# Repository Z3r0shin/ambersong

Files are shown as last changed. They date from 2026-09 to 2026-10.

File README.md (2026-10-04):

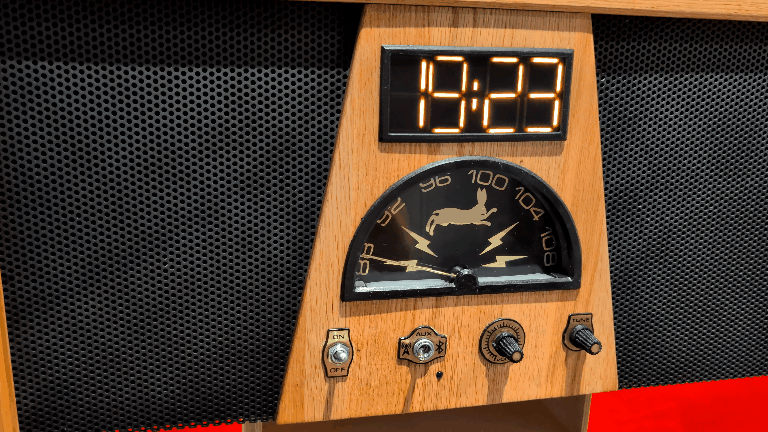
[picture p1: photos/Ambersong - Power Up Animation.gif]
Ambersong powering up


# Ambersong

*An old soul, glowing anew into the modern world.*

A LLOYD'S TM-838N tube radio from the early sixties, rebuilt around two ESP32 boards that
add Bluetooth, a retro-looking clock and a needle over a brass dial that follows the tuning.

## How it started

I found this radio in the trash, in a pile of other junk. The enclosure was bashed in and both the
power cord and antennas were pulled out. I tried it anyway, curious. Even though all it gave me was 
static, it was warm static, kind of like warm wind at night. I wasn't ready to throw that away.

So, I started restoring it. A couple of the old components had to be replaced. The tubes, though, 
still had enough life in them for a lot more years of use. If the tubes could last that long, I could
make something durable out of it, an heirloom.

I wanted it to look warm and cozy, mostly as an excuse and a challenge, to show off some of my 
woodworking skills and try some brass work. The cabinet is oiled oak and walnut, brass, and matte 
black accents. That cabinet, wood and brass together, is the part I'm proudest of. When it's on, 
it glows amber and still feels analog in all the good parts.

From there, the goal was to make it last for decades and write every part of it down so someone else 
could build their own (or use it as help/guide for something similar), repair one or change something.

## What it does

The tube set still does the receiving. Its original knob still turns its own tuning capacitor.
A magnetic angle sensor reads the capacitor's shaft and a small stepper motor moves the needle to 
match. The frequency scale isn't a straight line, so the radio calibrates itself. While it plays, 
an RDA5807M FM chip listens for the tube set's local oscillator, works out which station the set 
is really tuned to and corrects the needle's curve in firmware.

The tube radio's sound output goes through a PCM1802 ADC converter into the audio board, out through a
PCM5102A DAC to the amplifier and speakers of a repurposed Kramer Tavor 5-O pair. A front DPDT switch 
changes the audio from radio, Bluetooth or an AUX input. Four LED-filament digits at the top
show the time from a battery-backed RTC that sets itself over the network. A small web page on
the home network shows and changes every setting and updates both boards over WiFi.

## Why a Bible and a Gospel

Two documents describe the whole machine: the Hardware Bible for everything physical and the
Firmware Gospel for the code. Each one is meant to be the book you trust for its half of the
radio. The religious names are iconography, nothing more: I'm not religious, I just like the
symbols. Don't be upset about this please.

Each comes in two editions with the same information. The **Human Readable edition** is the one to
read (if you're a human): chapters, figures, an index and a "when something is wrong" table at the end of most chapters.
The **LLM edition** is the complete reference text it was written from; where the two differ, the LLM
edition is right. Why two "editions"? Because the LLM edition can't be understood at all by humans
(except maybe geniuses or complete fools) and I didn't only publish this project for it to be found
by AIs. Anyway, the Human Edition is also pretty, not the LLM one.

- **Hardware Bible**: what is wired to what, fitted values, the tube radio circuit, the FM antenna, the
  amplifier, the cabinet and the printed parts.
  [PDF](docs/Ambersong%20-%20Hardware%20Bible%20-%20Human%20Readable.pdf) ·
  [chapters](docs/human/hardware-bible/) ·
  [LLM edition](docs/llm-edition/HARDWARE-BIBLE.md)
- **Firmware Gospel**: what the firmware does and why, every setting, what was tried and dropped, and
  how to build, flash, update and recover it.
  [PDF](docs/Ambersong%20-%20Firmware%20Gospel%20-%20Human%20Readable.pdf) ·
  [chapters](docs/human/firmware-gospel/) ·
  [LLM edition](docs/llm-edition/FIRMWARE-GOSPEL.md)

## Building your own

Your radio, cabinet and amplifier probably won't be the same as mine and the documents are 
written with that in mind (hopefully). You could source your own parts and make it painful to you 
too to make everything work just enough that, past that pissed off state that you will certainly
achieve doing something like this, you can accept the flaws and embrace the result. Parts that only 
make sense for this build are marked as such. On the firmware side, expect to change pins, sensor 
directions, the tuner's travel and the needle's limits; the Gospel should say where each one lives.

The firmware is one PlatformIO project with two environments, `s3` for the main board (ESP32-S3,
N16R8) and `a32` for the audio board (ESP32). The toolchain is pinned to `espressif32@7.0.1`, just
to make sure that at least some stuff will translate correctly to you.

## Safety

Many tube radios from this era have no isolation transformer. If you find/use an old tube radio,
check if the chassis is tied to mains. Mine was, and since in those years the wall plug was reversible,
either live/hot or neutral could go to the whole chassis. Unplug it before you open it/play with such
a tube radio. Hardware Bible §31.1 covers what that means in this build.

## What's in here

```
docs/                    the Hardware Bible and the Firmware Gospel: Human Readable PDFs,
                         their chapters (docs/human/) and the LLM editions (docs/llm-edition/)
firmware/                the PlatformIO project for both boards
hardware/schematics/     the KiCad project, a collated PDF file and the radio's factory schematic
hardware/STLs/           the 76 printed parts and a Sketchup project with all those parts
photos/                  the finished radio, wow, such radio, mucho bueno
```

The KiCad sheets show what was built, drawn to be read. They aren't a PCB layout, so ERC and such do
not resolve correctly, that is normal. I don't know how to operate KiCad for this purpose anyway, I
use it to help route stuff visually only. I hope nobody's eyes bleed too much looking at them. Both 
the KiCad schematics and the Bible should agree. If not, open an issue, I'll correct it.

## What's NOT in here

I made my own antenna. I used what I had at home to make it. It's a 3 elements yagi, mainly because
where I am, almost all the stations are on Mount Royal, making it pretty directional. You should
definitely look what is best for your own case. The antenna build itself is in Bible and the Sketchup 
file though, if you want to take a look.

There is no bill of materials. Mostly because this specific build is made using what I found in a
pretty random fashion. Yes, I did buy the DAC, ADC, stepper, etc. but those are readily available in
the same form I bought, and I am pretty sure you can substitute most of them for something similar
and have similar results. Obviously, some adjustments will be needed, especially the STLs and the
electrical components values. As I said, this is not a build guide, its for inspiration and for
other mad folks that might stumble here trying to resolve a problem that is a part of my build.

## Credits

- My parents and friends, for their input on the design.
- Axiris, for the LEDitron: seven-segment digits made from LED filaments. I borrowed the idea
  and the name, nothing else. See the [LEDitron display](https://www.elektormagazine.com/labs/leditron-display-150448)
  on Elektor Labs (2015) and the [LEDitron clock and scoreboard](https://www.elektormagazine.com/labs/160205-clock-scoreboardtimer-with-leditron-modules).
- Phil Schatzmann, for the [ESP32-A2DP](https://github.com/pschatzmann/ESP32-A2DP) library that
  handles Bluetooth audio.
- My stupidity for making me do this and convincing myself that its a good idea.
- My wife and kids for putting up with me. It's done now, papa can come home.

The factory schematic of the TM-838N is included for reference, but note that it is superseded 
by the KiCad schematic. The documents also cite the SAMS Photofact for this set, which is 
copyrighted and not included.

## Disclaimer

I have barely coded anything in this. It's all been vibe-coded with Claude Code and Codex. The artwork,
design, and anything other than sound and electrical engineering and the actual coding were done
without AI, by me with the help of my friends and family.

## Contributions

You can open issues if you have questions and I'll try to help if I can, but don't count on me to 
make this yours. I'll just help with what I can, if I can.

## License

- Firmware: GPL-3.0-or-later
- Hardware design files (KiCad, STL): CERN-OHL-S-2.0
- Documentation: CC BY-SA 4.0
- Photos and renders: CC BY-NC-ND 4.0
- The running hare : all rights reserved. It's family imagery, not for reuse.

Apart from the photos and the hare, you can use any of it, change it and share it, commercially
too, as long as what you share stays under the same license. Details and exceptions are in [`LICENSE`](LICENSE) and [`NOTICE`](NOTICE).

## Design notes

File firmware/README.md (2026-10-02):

# Ambersong firmware

One PlatformIO project for the two boards of Ambersong:

| Environment | Board | What it runs |
|---|---|---|
| `s3` | ESP32-S3 (N16R8: 16 MB flash, 8 MB octal PSRAM) | the clock display, the dial needle and its sensors, the tuning calibration (RDA5807M), the panel lamps, WiFi, the web portal, over-the-air updates for both boards |
| `a32` | ESP32 | audio: the tube radio through the PCM1802 ADC, Bluetooth A2DP, the PCM5102A DAC, the source switch, the volume knob, the Bluetooth button and lamp, the DS3231 clock |

```
src/s3/      main board
src/a32/     audio board
include/     shared by both: pins.h (every pin), proto.h and link.h (the link between the boards)
data/        the portal's web page (gzipped into src/s3/page_gz.h at build time)
scripts/     build scripts: version stamping, page packing
```

## Build

```
pio run -e s3
pio run -e a32
```

The platform is pinned to `espressif32@7.0.1` (Arduino-ESP32 2.0.17, ESP-IDF 4.4.7), and the
ESP32-A2DP library to one commit. Do not update either without re-testing everything.

## Everything else

Flashing, the first boot, the portal, updates over the air, recovery, every setting and the reason
behind each design decision are in the Firmware Gospel: the [Human Readable edition](../docs/Ambersong%20-%20Firmware%20Gospel%20-%20Human%20Readable.pdf)
([chapters](../docs/human/firmware-gospel/)) or the complete [LLM edition](../docs/llm-edition/FIRMWARE-GOSPEL.md).
Start with its chapter 3 to build and flash from a clean PC, and its chapter 1 if the radio
misbehaves. What each pin is wired to is in the Hardware Bible,
the [Hardware Bible](../docs/Ambersong%20-%20Hardware%20Bible%20-%20Human%20Readable.pdf)
([chapters](../docs/human/hardware-bible/), [LLM edition](../docs/llm-edition/HARDWARE-BIBLE.md)).

Pins, sensor directions, the tuner's travel and the needle's limits are those of the author's
radio. Expect to change them for yours: the Gospel says where each one lives.

Licence: GPL-3.0-or-later (see [`../LICENSE`](../LICENSE)).

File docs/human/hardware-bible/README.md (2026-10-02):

# Ambersong — Hardware Bible, Human Readable edition

The same book as a PDF: [`Ambersong - Hardware Bible - Human Readable.pdf`](../../Ambersong%20-%20Hardware%20Bible%20-%20Human%20Readable.pdf).
The complete text it is based on (LLM edition): [`docs/llm-edition/`](../../llm-edition/).

## Contents

- [About this book](00-about.md)
- [1. What Ambersong is](01-what-it-is.md)
- [2. Safety before you open it](02-safety.md)
- [3. The physical build](03-physical-build.md)
- [4. The two microcontroller boards](04-boards.md)
- [5. Power, earth and grounds](05-power.md)
- [6. The audio chain](06-audio.md)
- [7. The clock display](07-display.md)
- [8. Dial, needle and tuning sensors](08-dial-sensors.md)
- [9. Front-panel controls and lamps](09-controls-lamps.md)
- [10. Cables and harnesses](10-cables.md)
- [11. The FM antenna](11-antenna.md)
- [12. The amplifier and speakers](12-amp.md)
- [13. The tube radio (LLOYDS TM-838N)](13a-tube-radio.md)
- [13b-tube-radio](13b-tube-radio.md)
- [Appendix A. Datasheet facts used in this machine](A-datasheet-limits.md)
- [Appendix B. Where the schematics differ from this book](B-schematic-differences.md)
- [Appendix C. What this book does not cover, and open points](C-open-points.md)
- [Appendix D. Printed parts](D-printed-parts.md)
- [Glossary](G-glossary.md)

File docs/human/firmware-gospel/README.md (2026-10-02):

# Ambersong — Firmware Gospel, Human Readable edition

The same book as a PDF: [`Ambersong - Firmware Gospel - Human Readable.pdf`](../../Ambersong%20-%20Firmware%20Gospel%20-%20Human%20Readable.pdf).
The complete text it is based on (LLM edition): [`docs/llm-edition/`](../../llm-edition/).

## Contents

- [About this book](00-about.md)
- [1. Rescue: when the radio misbehaves](01-rescue.md)
- [2. The machine at a glance](02-at-a-glance.md)
- [3. Building, flashing and updating](03-build-flash-update.md)
- [4. The main board: start-up, clock, lamps and time](04-main-board.md)
- [5. The dial needle](05-needle.md)
- [6. Tuning and the dial's self-calibration](06-tuning.md)
- [7. Settings](07-settings.md)
- [8. Network, web portal and console](08-network-portal.md)
- [9. The audio board and the link between the boards](09-audio-board-link.md)
- [10. Sound and Bluetooth](10-sound-bluetooth.md)
- [11. History and bench tests](11-history.md)
- [12. Known issues, ideas and untested paths](12-known-issues.md)
- [Appendix A. Settings reference](A-settings-reference.md)
- [Appendix B. Network and portal constants, HTTP endpoints, state fields](B-network-constants.md)
- [Appendix C. Portal actions](C-portal-actions.md)
- [Appendix D. Console keys](D-console-keys.md)
- [Appendix E. Portal map: tabs, cards, buttons and the calls they make](E-portal-map.md)
- [Appendix F. Link reference: constants, messages and payloads](F-link-reference.md)
- [Appendix G. Audio constants and experiments](G-audio-constants.md)
- [Appendix H. The pop hunt in detail](H-pop-hunt.md)
- [Appendix I. Pins as the firmware uses them](I-pin-use.md)

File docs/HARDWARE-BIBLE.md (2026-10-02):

# Ambersong — Hardware Bible

## 0. About this document

**What Ambersong is.** A vintage vacuum tube radio, a LLOYDS TM-838N AM/SW/FM set, connected with ESP32 audio and
control. Two ESP32 boards sit beside the tube chassis. The main MCU, an ESP32-S3, drives the LED clock display, the
dial-needle stepper and its sensors, the RDA5807M tuning calibrator and the panel lamps. The audio MCU, an ESP32 called
"A32" throughout, digitises the tube radio's output through a PCM1802 ADC, feeds a PCM5102A DAC to an external amplifier,
and reads the front-panel source switch (RADIO / BT / AUX), the Bluetooth button and LED, a volume pot and a DS3231 RTC.

**What this document covers.** The hardware: what joins what in the machine and in the tube radio inside it. For the
tube radio it also gives the fitted values and the original specifications held in the sheet's hidden Spec fields. The FM
antenna as built is §29; what the amp and its speakers are, and the amp's input panel, are §30; the physical build (the
cabinet, access, the front panel, the tuning and needle mechanics, the Faraday cages) is §31, mentioned rather than detailed.
This is not a step-by-step build guide: it does not cover wire colours (except the amp supply's four wires, §30), pin-1
sides, crimp/JST housings, individual cable lengths or routing, the contact order inside a connector, or the amp's circuit. Firmware is documented in `FIRMWARE-GOSPEL.md`. This document takes only five pin facts from the
firmware, listed below.

**How to read it with the Gospel and the sheets.** The KiCad sheets in `hardware/schematics/` are visual aids. The author
uses KiCad to show a human what was built, not to make a PCB, and some drawings place a part where it reads best rather
than where it sits (§22 says where). This document states the fitted hardware. Where a sheet and this document differ,
this document is right, and §25 lists the known drawing errors: all are corrected in the published sheets except two
typos. `FIRMWARE-GOSPEL.md` describes what the firmware does with this hardware. A firmware comment or define that
describes wiring is not a hardware record: where one disagrees with this document, the comment is stale (§26 lists the
known ones).

**Order of truth.** For the machine: the fitted hardware first, then the main sheet, then the sub-sheets. For the tube
radio: the fitted hardware first, then the factory schematic (`hardware/schematics/LLOYDS TM-838 factory schematic.jpg`),
then the SAMS Photofact for the set (a published, copyrighted service document, not included here). The tube radio sheet
reflects the fitted hardware, except for a few details noted on the sheet itself. Datasheet facts (§24) are quoted and
marked, and they describe the datasheet part, which is not always the fitted one.

**Pin facts taken from the firmware.** Five facts come from the firmware, not from the drawings, because on these points
the firmware is exact: the digit order, the digit MOSFET part, the Bluetooth button and LED pins, the volume pot wiper
pin, and the positions of the front DPDT source switch. The lines are quoted as they read in the firmware on 2026-09-12, before v.1.0 (paths under `firmware/`). Some of their comments have since been reworded or removed; the code on these lines and every pin number are unchanged.

- Digit order; line 42 is a comment asking for re-confirmation, written before the order was confirmed:
  - `include/pins.h` — `//  exactly one digit lights at a time. To be re-confirmed on the next run.`
  - `include/pins.h` — `#define S3_DIGIT_1         42      // was 2`
  - `include/pins.h` — `#define S3_DIGIT_2          2      // was 42, confirmed: this pin lights digit 2`
  - `include/pins.h` — `#define S3_DIGIT_3         40      // was 41`
  - `include/pins.h` — `#define S3_DIGIT_4         41      // was 40, confirmed: this pin lights digit 4`
- Digit MOSFET part FQP27P06; a comment:
  - `include/pins.h` — `//  S3 -> digit-driver ULN2003 input -> 1k -> FQP27P06 gate (high side).`
- BT button GPIO25 and BT LED GPIO33, both active low:
  - `include/pins.h` — `#define A32_BT_BUTTON      25      // ACTIVE LOW, ground-referenced, INPUT_PULLUP`
  - `include/pins.h` — `#define A32_BT_LED         33      // sinks; anode on 3V3, so drive LOW to light`
  - `src/a32/main.cpp` — `  pinMode(A32_BT_BUTTON, INPUT_PULLUP);      // ACTIVE LOW, measured`
  - `src/a32/main.cpp` — `  bool down = (digitalRead(A32_BT_BUTTON) == LOW);`
  - `src/a32/btled.cpp` — `  ledcWrite(LED_CH, 255 - v);         // ACTIVE LOW`
  - `src/a32/btled.cpp` — `  ledcAttachPin(A32_BT_LED, LED_CH);`
- Volume pot wiper GPIO35:
  - `include/pins.h` — `#define A32_VOLUME_POT     35`
  - `src/a32/main.cpp` — `  for (int i = 0; i < 5; i++) { v[i] = analogRead(A32_VOLUME_POT); delayMicroseconds(150); }`
  - `src/a32/main.cpp` — `    uint16_t r = analogRead(A32_VOLUME_POT);`
- Source select on GPIO36: below 424 counts AUX, 2471 and up RADIO, between BT:
  - `include/pins.h` — `#define A32_MODE_ADC       36`
  - `src/a32/main.cpp` — `  for (int i = 0; i < 5; i++) { v[i] = analogRead(A32_MODE_ADC); delayMicroseconds(200); }`
  - `src/a32/main.cpp` — `  raw = v[2];`
  - `include/pins.h` — `#define A32_MODE_THRESH_AUX_BT     424   // raw below this          -> AUX`
  - `include/pins.h` — `#define A32_MODE_THRESH_BT_RADIO  2471   // raw above this          -> RADIO`
  - `src/a32/main.cpp` — `  if (raw <  A32_MODE_THRESH_AUX_BT)   return SRC_AUX;`
  - `src/a32/main.cpp` — `  if (raw >= A32_MODE_THRESH_BT_RADIO) return SRC_RADIO;`
  - `src/a32/main.cpp` — `  return SRC_BT;`
- The ladder, and the level each source reads, in comments that are exact for the switch positions (which leg gives which level follows from the drawn 22 kΩ and 68 kΩ):
  - `include/pins.h` — `//  The ladder itself is exactly as drawn - A_VDC through the switch, one leg`
  - `include/pins.h` — `//  direct and one through 68k, joining a single 22k to GND, then 1k + 0.1uF at`
  - `include/pins.h` — `//  the pin. Levels land at 3.3 V / 0.807 V / 0 V as designed.`
  - `include/pins.h` — `//        measured   AUX = 0        BT = 848 (0.81 V)   RADIO = 4095 (3.3 V)`

**How it was made.** A script read the saved `.kicad_sch` source text (never the netlist, never a picture for text) and
computed connectivity. Every item was then looked up again in the source and checked against the author's knowledge of
the fitted hardware.

**Where the drawings are wrong.** §25 lists the drawing errors found while this document was made, and how each was
corrected. If a drawing disagrees with this document, check §25 first.

**Conventions.**
- Coordinates are sheet millimetres. The author often types a value into a part's Reference field, so a part may be
  named by its value plus its position: `10kΩ@21.59,140.97`.
- Pins: `#1` is a pin number; `VCC`, `SCK`, `A`, `K` are pin names. The MCU symbols name their pins by GPIO number
  (U7 pin `4` is GPIO4). `p2/3` is the 2nd of 3 pins counted top-to-bottom in the library symbol, used when a symbol
  has neither name nor number (the JST connectors, the PC817). `p`-order is not a moulded contact number.
- A label name (`GPIO4`, `A_IO22`) is how the drawings refer to one conductor. A net can carry two names, a global
  label and a local label joined by a wire; both name that conductor.
- `A_VDC` = `A_3V3`: the same rail, joined by the bus. `S3_3V3` is the S3's 3.3 V. `5VDC_S` = `5VDC`.
- `CABLE S/FTP` on a connector pin: the cable's shield and foil are terminated there, to GND on the board side, and
  left open at the cable's other end, unless noted otherwise.
- Source lines name the drawing (the main sheet, the cable sheet, or `sheet <title>`; the files are listed below);
  "the author" where the fact rests on the author's knowledge of the fitted hardware rather than on a drawing; and SCn
  for a drawing correction in §25. "Label names across all drawings" means the label name was looked up on every
  drawing. Line numbers inside the `.kicad_sch` files and net numbers are left out, because every save moves them.
- `block B47`, `note B29`, `drawn blocks B6 and B7`: the rectangles drawn on a sheet, numbered B1, B2, … by position — top edge
  first, rounded to the millimetre, then left edge — as read when this document was made (a later save may renumber them); a
  text note carries the number of the smallest rectangle around it. The numbers are not printed on the drawings. The ones
  this document cites, by corners in sheet mm: the main sheet B29 (12.70,38.10)-(71.75,43.18), B30 (12.70,43.18)-(71.75,48.26), B31 (12.70,48.26)-(71.75,53.34), B47 (69.22,93.98)-(107.31,125.73); sheet HERE (the star-point buses) B5 (130.18,76.83)-(139.06,119.38), B6 (159.38,76.83)-(168.28,119.38), B7 (173.35,76.83)-(182.25,119.38).
  `G1` to `G9` name this document's nine Ambersong groups (§4 to §12); `T1` to `T9` name the tube radio groups (§13 to §21).
- Tube radio: a tube is drawn as units of one tube (its signal sections in their circuit, its heater on the heater string);
  S1A–S1G are seven drawn units of one mode switch; the terminal identifiers of L5, L6, L8–L14 and S1A–S1G are logical, not
  physical lugs. `CHASSIS` is the radio's circuit common, on mains neutral. In the polarized capacitors C1A–C1C and C2,
  pin #1 is the + terminal (read from the symbol embedded in the sheet).

**The drawings**, in `hardware/schematics/` (as saved on 2026-09-23):

| Named in this document | File |
|---|---|
| the main sheet | `Ambersong.kicad_sch` |
| the cable sheet | `Ambersong - CABLES.kicad_sch` |
| sheet 7 SEGMENTS 24H CLOCK DISPLAY | `Ambersong - 7 SEGMENTS 24H CLOCK DISPLAY.kicad_sch` |
| sheet AUDIO MCU ESP32-WROOM-32 | `Ambersong - AUDIO MCU ESP32-WROOM-32.kicad_sch` |
| sheet BLUETOOTH PAIR BUTTON & FRONT PANEL BLUETOOTH LED & DPDT ON-OFF-ON AUDIO SWITCH | `Ambersong - BLUETOOTH PAIR BUTTON & FRONT PANEL BLUETOOTH LED & DPDT ON-OFF-ON AUDIO SWITCH.kicad_sch` |
| sheet DS3231 RTC | `Ambersong - DS3231 RTC.kicad_sch` |
| the tube radio sheet | `Ambersong - LLOYDS TM-838N TUBE RADIO.kicad_sch` |
| sheet MAIN MCU ESP32-S3 N16R8 | `Ambersong - MAIN MCU ESP32-S3 N16R8.kicad_sch` |
| sheet P-MOSFET DIGITS & P-MOSFET DIGIT DRIVER & 7 SEGMENTS BUS DRIVER | `Ambersong - P-MOSFET DIGITS & P-MOSFET DIGIT DRIVER & 7 SEGMENTS BUS DRIVER.kicad_sch` |
| sheet PANEL RADIO LED PWM CONTROL | `Ambersong - PANEL RADIO LED PWM CONTROL.kicad_sch` |
| sheet PCM1802 ADC | `Ambersong - PCM1802 ADC & TUBE RADIO AUDIO JACK IN INTO PCM1802.kicad_sch` |
| sheet PCM5102A DAC | `Ambersong - PCM5102A DAC.kicad_sch` |
| sheet HERE (the star-point buses) | `Ambersong - STAR POINT VDC & GND JST XH BUSES.kicad_sch` (its box on the main sheet reads HERE) |
| sheet Power Detect | `Ambersong - POWER DETECT.kicad_sch` |
| sheet RDA5807M | `Ambersong - RDA5807M.kicad_sch` |
| sheet STEPPER DRIVER | `Ambersong - STEPPER DRIVER.kicad_sch` |
| sheet STEPPER LIMIT | `Ambersong - STEPPER LIMIT.kicad_sch` |
| sheet USB-C CONNECTORS | `Ambersong - USB-C CONNECTORS.kicad_sch` |
| sheet BOX FAN | `Ambersong - BOX FAN.kicad_sch` |

## 1. The two MCU boards

> Board markings as read by the author. Chip data is esptool output, read over USB on 2026-09-13. Each query reset its
> board into the ROM bootloader and back (`Hard resetting via RTS pin...`). Read-only: nothing was written. The boards'
> MAC addresses are masked here.

### Main MCU — ESP32-S3 devkit

Both boards are devkits. Module tin: "ESP32-S3-N16R8 FCC ID: 2AD6X-ESP32S3N16R8 IC: 29018-ESP32S3N16R8 CMIT ID: 2022DP2107". Board: "ESP32-S3 N16R8 YD-ESP32-23 2022-v1.3". The board's RGB LED is on GPIO48.

**USB:** `USB VID:PID=303A:1001 SER=xx:xx:xx:xx:xx:xx` on COM9 (`pio device list`, 2026-09-13).

**esptool.py v4.9.0, `--port COM9 flash_id`, exit 0:**
```
esptool.py v4.9.0
Serial port COM9
Connecting...
Detecting chip type... ESP32-S3
Chip is ESP32-S3 (QFN56) (revision v0.2)
Features: WiFi, BLE, Embedded PSRAM 8MB (AP_3v3)
Crystal is 40MHz
USB mode: USB-Serial/JTAG
MAC: xx:xx:xx:xx:xx:xx
Uploading stub...
Running stub...
Stub running...
Manufacturer: 68
Device: 4018
Detected flash size: 16MB
Flash type set in eFuse: quad (4 data lines)
Flash voltage set by eFuse to 3.3V
Hard resetting via RTS pin...
```

### Audio MCU (A32) — ESP32 devkit

The A32 board is marked "FCC IDL 2BB77-ESP32-32X". It is meant to carry an ESP32-WROOM-32E module.

**USB:** `USB VID:PID=10C4:EA60 SER=0001 LOCATION=1-5.4.4`, "Silicon Labs CP210x USB to UART Bridge", on COM8 (`pio device list`, 2026-09-13).

**esptool.py v4.9.0, `--port COM8 flash_id`, exit 0:**
```
esptool.py v4.9.0
Serial port COM8
Connecting....
Detecting chip type... Unsupported detection protocol, switching and trying again...
Connecting......
Detecting chip type... ESP32
Chip is ESP32-D0WD-V3 (revision v3.1)
Features: WiFi, BT, Dual Core, 240MHz, VRef calibration in efuse, Coding Scheme None
Crystal is 40MHz
MAC: xx:xx:xx:xx:xx:xx
Uploading stub...
Running stub...
Stub running...
Manufacturer: 5e
Device: 4016
Detected flash size: 4MB
Flash voltage set by a strapping pin to 3.3V
Hard resetting via RTS pin...
```

### Not yet established

- Whether the S3 module and the A32 module match any Espressif module datasheet. Espressif's FCC grantee code is 2AC7Z (per an esp32.com thread); the S3 module's 2AD6X is a different code; the A32's 2BB77 has not been looked up. Each datasheet fact in this document says what it describes: the chips as read above, or an Espressif module or devkit document.
- The flash chip makers behind manufacturer IDs 0x68 and 0x5e — not looked up.

## 2. Pin map — Main MCU (ESP32-S3), U7 on the main sheet

One row per module pin as drawn on the main sheet, in drawn order, with the author's statements about the fitted hardware applied.

| Pin | Signal | Goes to | Source |
|---|---|---|---|
| 3V3 (ord 1, left, 30.48,138.43) | S3_3V3 | C23 0.1uF and C25 10uF (return to U7 GND ord 2); 10k pull-ups on GPIO4/GPIO5; by label: U89.VDD with C28 (RDA5807M, main), U11.VCC (AS5600, main), S3_TUNER.p2 and S3_3V3 connector (S3 sub-sheet and cable sheet), RDA_3V3.p2 (RDA5807M sub-sheet and cable sheet) | the main sheet; label names across all drawings; SC16 |
| GND (ord 2, right, 54.61,138.43) | unnamed net | C23.#2, C25.#2 only | the main sheet; the author; SC16 |
| 3V3 (ord 3, left, 30.48,140.97) | no-connect | nothing | the main sheet |
| 43 | no-connect | nothing | the main sheet |
| RST | no-connect | nothing | the main sheet |
| 44 | no-connect | nothing | the main sheet |
| 4 | GPIO4 | 10kΩ to S3_3V3 and 0.1uF to GND on the main sheet; no other GPIO4 label on any drawing; S3 sub-sheet: U70 LIMITS header p2, jack p2 no-connect. Still wired to the LIMITS JST female, goes nowhere else | the main sheet; label names across all drawings; sheet MAIN MCU ESP32-S3 N16R8; the author |
| 1 | GPIO1 | 10kΩ pull-up; U6 PC817 p2/4 (collector) (main); Power-Detect sub-sheet U83.p2/4 (collector), U84.p2, POWER_DET.p2; cable sheet POWER_DET.p2 and S3_PWR_DET.p1; S3 sub-sheet S3_PWR_DET.p1 | the main sheet; label names across all drawings |
| 5 | GPIO5 | 10kΩ pull-up and 0.1uF; U42.OUT A3144 (main); cable sheet LIMIT.p3 and S3_LIMITS.p3; STEPPER LIMIT sub-sheet U90.p1, LIMIT.p3; S3 sub-sheet S3_LIMITS.p3 | the main sheet; label names across all drawings; the author |
| 2 | GPIO2 (digit 2 per SC4) | U5.I2 (main); cable sheet DIGIT_IN.p2, S3_DIGIT.p3; P-MOSFET sub-sheet U29.p2, DIGIT_IN.p2; S3 sub-sheet S3_DIGIT.p4 (the cable sheet orders these contacts differently; contact order is out of scope) | the main sheet; label names across all drawings; SC4; the author |
| 6 | GPIO6 | U2.I1 (main); cable sheet DISPLAY_IN.p1, S3_DISPLAY.p1; P-MOSFET sub-sheet U24.p1; S3 sub-sheet S3_DISPLAY.p1 | the main sheet; label names across all drawings |
| 42 | GPIO42 (digit 1 per SC4) | U5.I1 (main); cable sheet DIGIT_IN.p1, S3_DIGIT.p4; P-MOSFET sub-sheet U29.p1, DIGIT_IN.p1; S3 sub-sheet S3_DIGIT.p3 (the cable sheet orders these contacts differently; contact order is out of scope) | the main sheet; label names across all drawings; SC4; the author |
| 7 | GPIO7 | U2.I2 (main); cable sheet DISPLAY_IN.p2, S3_DISPLAY.p2; P-MOSFET sub-sheet U24.p2; S3 sub-sheet S3_DISPLAY.p2 | the main sheet; label names across all drawings |
| 41 | GPIO41 (digit 4 per SC4) | U5.I4 (main); cable sheet DIGIT_IN.p4, S3_DIGIT.p1; P-MOSFET sub-sheet U29.p4, DIGIT_IN.p4; S3 sub-sheet S3_DIGIT.p2 (the cable sheet orders these contacts differently; contact order is out of scope) | the main sheet; label names across all drawings; SC4; the author |
| 15 | GPIO15 | U2.I3 (main); cable sheet DISPLAY_IN.p3, S3_DISPLAY.p3; P-MOSFET sub-sheet U24.p3; S3 sub-sheet S3_DISPLAY.p3 | the main sheet; label names across all drawings |
| 40 | GPIO40 (digit 3 per SC4) | U5.I3 (main); cable sheet DIGIT_IN.p3, S3_DIGIT.p2; P-MOSFET sub-sheet U29.p3, DIGIT_IN.p3; S3 sub-sheet S3_DIGIT.p1 (the cable sheet orders these contacts differently; contact order is out of scope) | the main sheet; label names across all drawings; SC4; the author |
| 16 | GPIO16 | U2.I4 (main); cable sheet DISPLAY_IN.p4, S3_DISPLAY.p4; P-MOSFET sub-sheet U24.p4; S3 sub-sheet S3_DISPLAY.p4 | the main sheet; label names across all drawings |
| 39 | pin node → 220Ω → GPIO39 | 10kΩ pull-up to S3_3V3 at the pin, then 220Ω@63.50,158.75, then U11.SCL AS5600 (main); cable sheet S3_TUNER.p4; S3 sub-sheet S3_TUNER.p4 | the main sheet; label names across all drawings; the author |
| 17 | GPIO17 | U2.I5 (main); cable sheet DISPLAY_IN.p5, S3_DISPLAY.p5; P-MOSFET sub-sheet U24.p5; S3 sub-sheet S3_DISPLAY.p5 | the main sheet; label names across all drawings |
| 38 | pin node → 220Ω → GPIO38 | 10kΩ pull-up to S3_3V3 at the pin, then 220Ω@58.42,166.37, then U11.SDA AS5600 (main); cable sheet S3_TUNER.p3; S3 sub-sheet S3_TUNER.p3 | the main sheet; label names across all drawings; the author |
| 18 | GPIO18 | U2.I7 (main); cable sheet DISPLAY_IN.p7 and S3_DISPLAY.p7; P-MOSFET sub-sheet U24.p7; S3 sub-sheet S3_DISPLAY.p6 (the cable sheet orders these contacts differently; contact order is out of scope) | the main sheet; label names across all drawings |
| 37 | no-connect | nothing | the main sheet |
| 8 | GPIO8 | U2.I6 (main); cable sheet DISPLAY_IN.p6 and S3_DISPLAY.p6; P-MOSFET sub-sheet U24.p6; S3 sub-sheet S3_DISPLAY.p7 (the cable sheet orders these contacts differently; contact order is out of scope) | the main sheet; label names across all drawings |
| 36 | no-connect | nothing | the main sheet |
| 3 | no-connect | nothing | the main sheet |
| 35 | no-connect | nothing | the main sheet |
| 46 | no-connect | nothing | the main sheet |
| 0 | no-connect | nothing | the main sheet |
| 9 | GPIO9 | U3.I1 (main); cable sheet S3_STEPPER.p4, STEPPER_IN.p1; STEPPER DRIVER sub-sheet U38.p1; S3 sub-sheet S3_STEPPER.p4 | the main sheet; label names across all drawings |
| 45 | no-connect | nothing | the main sheet |
| 10 | GPIO10 | U3.I2 (main); cable sheet S3_STEPPER.p3, STEPPER_IN.p2; STEPPER DRIVER sub-sheet U38.p2; S3 sub-sheet S3_STEPPER.p3 | the main sheet; label names across all drawings |
| 48 | GPIO48 | U89.SCLK RDA5807M (main); RDA5807M sub-sheet RDA_I2C.p2, U92.p2; cable sheet RDA_I2C.p2 and S3_RDA.p1; S3 sub-sheet S3_RDA.p2 (the cable sheet orders these contacts differently; contact order is out of scope); also the S3 board's RGB LED | the main sheet; label names across all drawings; the author |
| 11 | GPIO11 | U3.I3 (main); cable sheet S3_STEPPER.p2, STEPPER_IN.p3; STEPPER DRIVER sub-sheet U38.p3; S3 sub-sheet S3_STEPPER.p2 | the main sheet; label names across all drawings |
| 47 | GPIO47 | U89.SDIO RDA5807M (main); RDA5807M sub-sheet RDA_I2C.p1, U92.p3; cable sheet RDA_I2C.p1 and S3_RDA.p2; S3 sub-sheet S3_RDA.p1 (the cable sheet orders these contacts differently; contact order is out of scope) | the main sheet; label names across all drawings; the author |
| 12 | GPIO12 | U3.I4 (main); cable sheet S3_STEPPER.p1, STEPPER_IN.p4; STEPPER DRIVER sub-sheet U38.p4; S3 sub-sheet S3_STEPPER.p1 | the main sheet; label names across all drawings |
| 21 | GPIO21 | 100Ω.#2 in block B47 (main); PANEL RADIO LED PWM sub-sheet 100Ω.#2, U82.p3, RLPC_IN.p1; cable sheet FM_LED_IN.p1 and S3_FM_LED.p2; S3 sub-sheet S3_FM_LED.p2. GPIO21 lands on Q1's gate, through the drawn 100 Ω | the main sheet; label names across all drawings; the author |
| 13 | S3_to_A32 | U10 pin 26 (main); AUDIO MCU sub-sheet U74.26, U80.p1, A32_UART.p1; cable sheet A32_UART.p1 and S3_UART.p2; S3 sub-sheet S3_UART.p2 | the main sheet; label names across all drawings |
| 20 | no-connect on the drawing | GPIO20 is the ESP32-S3's USB_D+ (datasheet, §24). The back-panel USB-C reaches the S3's native USB port (SC24). | the main sheet; SC24 |
| 14 | A32_to_S3 | U10 pin 27 (main); AUDIO MCU sub-sheet U74.27, U80.p2, A32_UART.p2; cable sheet A32_UART.p2 and S3_UART.p3; S3 sub-sheet S3_UART.p3 | the main sheet; label names across all drawings |
| 19 | no-connect on the drawing | GPIO19 is the ESP32-S3's USB_D− (datasheet, §24). The back-panel USB-C reaches the S3's native USB port (SC24). | the main sheet; SC24 |
| 5V (ord 41, left, 30.48,189.23) | 5VDC | 100uF@19.05,191.77 and 0.1uF@22.86,191.77 (return to U7 GND ord 43); the 5VDC rail (power buses); S3 sub-sheet S3_5VIN.p2; cable sheet S3_5VIN.p2 | the main sheet; label names across all drawings; SC16 |
| GND (ord 42, right, 54.61,189.23) | GND | global GND label | the main sheet |
| GND (ord 43, left, 30.48,191.77) | unnamed net | 100uF.#2, 0.1uF@22.86,191.77.#2 only | the main sheet |
| GND (ord 44, right, 54.61,191.77) | no-connect | nothing | the main sheet |

## 3. Pin map — Audio MCU (A32), U10 on the main sheet

One row per module pin as drawn on the main sheet, in drawn order, with the author's statements about the fitted hardware applied.

| Pin | Signal | Goes to | Source |
|---|---|---|---|
| 3V3 | A_3V3 | C20 0.1µF, C21 10µF, C22 10µF (returns to U10 GND ord 2); A_3V3 bus: sheet HERE (the star-point buses) (U52-U56, A32_VDC, A32_3V3, same net as A_VDC); A32 sub A32_3V3 p1 and A32_BT_LED p1; BT sub A32_BT_LED.p2/4 | the main sheet; label names across all drawings; the author; SC17 |
| GND (ord 2, right top) | unnamed net | C20/C21/C22 returns (main); sub: GND label, C54/C55/C56 returns + A32_3V3 cable GND | the main sheet; sheet AUDIO MCU ESP32-WROOM-32 |
| EN | no-connect | — | the main sheet |
| 23 | no-connect | — | the main sheet |
| 36 | A_IO36 via 1 kΩ (A_IO36_H on sub) | 0.1µF to GND at the pin; 1kΩ to the ladder node: 22kΩ to GND, 68kΩ to A_IO36_L, A32_SWITCH p2/3 (THIS A32_SWITCH.p2/3 -> LISTENER.p2/3; BT sub LISTENER/U43/U44 p2/3) to the front DPDT switch; main 22kΩ.#1, 68kΩ.#1, DPDT_ON_OFF_ON.A | the main sheet; label names across all drawings; the author |
| 22 | A_IO22 | U8.SDA (main); RTC module SDA U16/RTC_I2C p3/4; A32_RTC cable; THIS A32_RTC.p1/3, RTC_I2C.p3/4 | the main sheet; label names across all drawings |
| 39 | no-connect | — as drawn; not joined to GPIO34 or GPIO36 on the board now (§26) | the main sheet; the author |
| 1 | no-connect | — | the main sheet |
| 34 | no-connect | — as drawn; not joined to GPIO39 or GPIO36 on the board now (§26) | the main sheet; the author |
| 3 | no-connect | — | the main sheet |
| 35 | A_IO35 (drawn A_IO34 until 2026-09-23; SC6 done) | RV4.2 volume pot wiper (main); A32_VOL cable p1/2 (sub); THIS VOLUME.p2/3 | the main sheet; label names across all drawings; the author; SC6; firmware (§0) |
| 21 | A_IO21 | U8.SCL (main); RTC module SCL U16/RTC_I2C p4/4 as drawn; A32_RTC cable; THIS A32_RTC.p3/3, RTC_I2C.p4/4 as drawn. The RTC_I2C 4th position is not connected (SCV6 done: the 2026-09-23 save draws RTC_I2C with two of its four positions connected, which is right) | the main sheet; label names across all drawings; the author |
| 32 | no-connect | — | the main sheet |
| GND (ord 14, right) | no-connect | — on the main sheet; the sub-sheet puts a local GND label on the pin (since 2026-09-23) | the main sheet; sheet AUDIO MCU ESP32-WROOM-32 |
| 33 | A_IO33 | BT LED D29 cathode (main, anode A_VDC); A32_BT_LED p2/4; THIS BT_LED.p1/4; BT sub LED − (SC3) | the main sheet; label names across all drawings; the author; SC3; firmware (§0) |
| 19 | A_IO19 | PCM1802.DOUT (main); A32_I2S p7/7; THIS ADC_I2S.p1/6; PCM1802 sub U23.p1/6 | the main sheet; label names across all drawings |
| 25 | A_IO25 | BT pair button SW2.1 (main; SW2 pin 2 on GND per SC3); A32_BT_LED p4/4; THIS BT_LED.p3/4; BT sub button (SC3) | the main sheet; label names across all drawings; the author; SC3; firmware (§0) |
| 18 | A_IO18 | PCM1802.BCK and U9 PCM5102A.BCK (main); A32_I2S p6/7; THIS ADC_I2S.p2/6, DAC_I2S.p2/6 | the main sheet; label names across all drawings |
| 26 | S3_to_A32 | S3 U7.13 (main) / U63.13 (S3 sub); A32_UART p1/3; THIS S3_UART.p2/3 | the main sheet; label names across all drawings |
| 5 | no-connect | — | the main sheet |
| 27 | A32_to_S3 | S3 U7.14 (main) / U63.14 (S3 sub); A32_UART p2/3; THIS S3_UART.p3/3 | the main sheet; label names across all drawings |
| 17 | A_IO17 | PCM1802.LRCK and U9.LRCK (main); A32_I2S p4/7; THIS ADC_I2S.p4/6, DAC_I2S.p4/6 | the main sheet; label names across all drawings |
| 14 | no-connect | — | the main sheet |
| 16 | no-connect (unused) | — | the main sheet; the author (GPIO16 unused) |
| 12 | no-connect | — | the main sheet |
| 4 | A_IO4 | U9 PCM5102A.DIN and 100kΩ@116.84,24.13.#1 (main); A32_I2S p2/7; THIS DAC_I2S.p3/6; DAC sub U13.p4/6 | the main sheet; label names across all drawings |
| GND (ord 27, left) | GND | 5V decoupling returns; A32_5VIN cable GND (sub) | the main sheet; sheet AUDIO MCU ESP32-WROOM-32 |
| 0 | GPIO0 node → A_IO0A (ADC clock) and A_IO0D (DAC clock) | Two 33 Ω at the A32 pin, one per converter. Main sheet: 33Ω@109.22,175.26 → A_IO0A → PCM1802.SCK, 33Ω@109.22,180.34 → A_IO0D → U9 PCM5102A.SCK (SC8 done). A32 sub-sheet: 33Ω@167.64,102.87 → A_IO0A → A32_I2S.p3/7, 33Ω@167.64,107.95 → A_IO0D → A32_I2S.p1/7. Cable sheet: A32_I2S.p3/7 = A_IO0A = ADC_I2S.p6/6; A32_I2S.p1/7 = A_IO0D = DAC_I2S.p1/6. | the main sheet; sheet AUDIO MCU ESP32-WROOM-32; the cable sheet; label names across all drawings; the author; SC7; SC8 |
| 13 | no-connect | — | the main sheet |
| 2 | no-connect | — | the main sheet |
| 9 | no-connect | — | the main sheet |
| 15 | no-connect | — | the main sheet |
| 10 | no-connect | — | the main sheet |
| 8 | no-connect | — | the main sheet |
| 11 | no-connect | — | the main sheet |
| 7 | no-connect | — | the main sheet |
| 5V | 5VDC | 0.1µF + 100µF to GND; 5VDC rail via A32_5VIN cable (THIS A32_5VIN.p2/2; sheet HERE (the star-point buses)) | the main sheet; label names across all drawings |
| 6 | no-connect | — | the main sheet |

## 4. Main MCU (ESP32-S3) and the back-panel USB-C

### On the main sheet

- **S3_3V3** — The S3 board's upper 3V3 pin drives the S3_3V3 rail, decoupled by C23 0.1 µF and C25 10 µF, and feeds the GPIO4 and GPIO5 pull-ups.
  - members: U7.3V3 (ord 1, upper left), C23.#1 (0.1uF), C25.#1 (10uF), 10kΩ@21.59,140.97.#1, 10kΩ@27.94,143.51.#1, global label S3_3V3 (22.86,135.89)
  - source: the main sheet; SC16
- **unnamed net** — C23/C25 return to U7's top-right GND pin. The net has no GND label.
  - members: C23.#2, C25.#2, U7.GND (ord 2, top right, 54.61,138.43)
  - source: the main sheet (U7 pin 2/44)
- **S3_3V3** — Supply end of the GPIO1 pull-up.
  - members: 10kΩ@57.15,143.51.#1, global label S3_3V3 (58.42,140.97)
  - source: the main sheet
- **S3_3V3** — Supply end of the GPIO38/GPIO39 pull-ups (10 kΩ).
  - members: 10kΩ@58.42,161.29.#1, 10kΩ@60.96,160.02.#1, global label S3_3V3 (66.04,161.29)
  - source: the main sheet; the author
- **GPIO1** — GPIO1 has a 10 kΩ pull-up to S3_3V3. By label it reaches U6 (PC817) pin p2/4 on the main sheet.
  - members: U7.1, 10kΩ@57.15,143.51.#2, global label GPIO1
  - source: the main sheet; label names across all drawings
- **GPIO4** — GPIO4 has a 10 kΩ pull-up and 0.1 µF to GND. No other drawing carries a GPIO4 label. It is still wired to the LIMITS JST female with these parts, and goes nowhere else.
  - members: U7.4, 10kΩ@21.59,140.97.#2, 0.1uF@19.05,146.05.#1, global label GPIO4 (19.05,142.24)
  - source: the main sheet; label names across all drawings; the author
- **GPIO5** — GPIO5 has a 10 kΩ pull-up and 0.1 µF to GND. By label it reaches U42.OUT (A3144 Hall switch), carried on the LIMITS harness.
  - members: U7.5, 10kΩ@27.94,143.51.#2, 0.1uF@19.02,151.13.#2, global label GPIO5 (19.05,154.94)
  - source: the main sheet; label names across all drawings; the author
- **GND** — Ground return of the GPIO4 and GPIO5 capacitors.
  - members: 0.1uF@19.05,146.05.#2, 0.1uF@19.02,151.13.#1, global label GND (15.24,147.32)
  - source: the main sheet
- **GND** — The only U7 GND pin drawn onto a GND label.
  - members: U7.GND (ord 42, right, 54.61,189.23), global label GND (57.15,189.23)
  - source: the main sheet
- **5VDC** — The S3 board's 5V pin takes 5VDC, with 100 µF and 0.1 µF across it.
  - members: U7.5V, 100uF@19.05,191.77.#1, 0.1uF@22.86,191.77.#1, global label 5VDC (16.51,186.69)
  - source: the main sheet; SC16
- **unnamed net** — The 5V capacitors return to U7's bottom-left GND pin. The net has no GND label.
  - members: U7.GND (ord 43, bottom left, 30.48,191.77), 100uF@19.05,191.77.#2, 0.1uF@22.86,191.77.#2
  - source: the main sheet (U7 pin 43/44)
- **unnamed net** — Pin 39, then the 10 kΩ pull-up junction, then the 220 Ω series resistor.
  - members: U7.39, 10kΩ@60.96,160.02.#2, 220Ω@63.50,158.75.#2
  - source: the main sheet
- **GPIO39** — Cable side of the 220 Ω. By label it reaches U11.SCL (AS5600).
  - members: 220Ω@63.50,158.75.#1, global label GPIO39
  - source: the main sheet; label names across all drawings
- **unnamed net** — Pin 38, then the 10 kΩ pull-up junction, then the 220 Ω series resistor.
  - members: U7.38, 10kΩ@58.42,161.29.#2, 220Ω@58.42,166.37.#1
  - source: the main sheet
- **GPIO38** — Cable side of the 220 Ω. By label it reaches U11.SDA (AS5600).
  - members: 220Ω@58.42,166.37.#2, global label GPIO38
  - source: the main sheet; label names across all drawings
- **GPIO2 / GPIO42 / GPIO41 / GPIO40** — Digit-select outputs: GPIO42 → digit 1, GPIO2 → digit 2, GPIO40 → digit 3, GPIO41 → digit 4 (SC4). The main sheet draws this order (SC4 done).
  - members: U7.2 label GPIO2, U7.42 label GPIO42, U7.41 label GPIO41, U7.40 label GPIO40
  - source: the main sheet; SC4
- **GPIO6, 7, 15, 16, 17, 8, 18** — Segment outputs by global label to the segment ULN2003A U2.
  - members: U7.6 → U2.I1, U7.7 → U2.I2, U7.15 → U2.I3, U7.16 → U2.I4, U7.17 → U2.I5, U7.8 → U2.I6, U7.18 → U2.I7
  - source: the main sheet; label names across all drawings
- **GPIO9, 10, 11, 12** — Stepper outputs by global label to U3 (ULN2003A_1).
  - members: U7.9 → U3.I1, U7.10 → U3.I2, U7.11 → U3.I3, U7.12 → U3.I4
  - source: the main sheet; label names across all drawings
- **S3_to_A32 / A32_to_S3** — Inter-MCU UART: S3 GPIO13 to A32 pin 26, A32 pin 27 to S3 GPIO14.
  - members: U7.13 → U10.26, U7.14 → U10.27
  - source: the main sheet; label names across all drawings
- **GPIO48 / GPIO47** — RDA5807M bus with no external pull-ups. GPIO48 also controls the S3 board's RGB LED (it was off before, and is bright now).
  - members: U7.48 → U89.SCLK, U7.47 → U89.SDIO
  - source: the main sheet; label names across all drawings; the author
- **GPIO21** — Panel-lamp PWM output. It lands on Q1's gate; the 100 Ω on the way is drawn.
  - members: U7.21 → 100Ω.#2 (block B47)
  - source: the main sheet; label names across all drawings; the author
- **U7 no-connect** — No-connect X on each; nothing attached.
  - members: 3V3 (ord 3), RST, 43, 44, 37, 36, 35, 3, 46, 0, 45, 20, 19, GND (ord 44)
  - source: the main sheet

### On sheet: MAIN MCU ESP32-S3 N16R8

- **U63 power** — Since the 2026-09-23 save (SC16 done) the sub-sheet draws U63's power pins connected: both 3V3 pins on the local label 3V3 (= S3_3V3), decoupled by C45 0.1uF and C53 10uF, which return to U63's GND ord 2; the 5V pin on the local label 5V (= 5VDC); the other three GND pins on local GND labels. The main sheet X's U7's lower 3V3 pin (ord 3) and GND ord 44; this sheet puts both on labels.
  - members: U63.3V3 (ord 1), C45.#1, C53.#1, U63.3V3 (ord 3) on 3V3; U63.GND (ord 2), C45.#2, C53.#2 on GND; U63.5V (ord 41) on 5V; U63.GND (ord 42, 43, 44) on GND
  - source: sheet MAIN MCU ESP32-S3 N16R8; the author; SC16
- **3V3 = S3_3V3** — The local label 3V3 carries U63's two 3V3 pins with C45 and C53, and feeds all five pull-ups (the global name S3_3V3 is drawn only on the TUNER pull-ups' conductor and the S3_3V3 connector), the TUNER harness supply and the 2-pin S3_3V3 connector.
  - members: U63.3V3 (ord 1), U63.3V3 (ord 3), C45.#1, C53.#1, 10kΩ@133.35,73.66.#1, 10kΩ@130.81,74.93.#1, 10kΩ@167.64,73.66.#1, 10kΩ@170.18,96.52.#1, 10kΩ@165.10,96.52.#1, U66.p3, S3_TUNER.p2, S3_3V3.p1, U73.p1
  - source: sheet MAIN MCU ESP32-S3 N16R8
- **5V = 5VDC / GND** — 5VIN connector (pin 1 GND, pin 2 5VDC) with 100 µF + 0.1 µF; S3_3V3 connector (pin 1 3V3, pin 2 GND).
  - members: U63.5V, S3_5VIN.p2, U72.p2, 0.1uF@146.05,130.81.#1, 100uF.#1, both cap returns (local GND), U63.GND (all four), S3_5VIN.p1, U72.p1, S3_3V3.p2, U73.p2
  - source: sheet MAIN MCU ESP32-S3 N16R8
- **CABLE S/FTP = GND** — LIMITS harness ground, also the GPIO4/GPIO5 capacitor return. Shield and foil are terminated to GND at the board and open at the far end.
  - members: S3_LIMITS.p1, U70.p1, 0.1uF@128.27,72.39.#1, 0.1uF@121.92,74.93.#1
  - source: sheet MAIN MCU ESP32-S3 N16R8; the author
- **GPIO4 node** — GPIO4 with pull-up and cap reaches LIMITS header pin 2; the jack pin 2 is no-connect. It is wired to the LIMITS JST female, and goes nowhere else.
  - members: U63.4, 10kΩ@133.35,73.66.#2, 0.1uF@128.27,72.39.#2, U70.p2, S3_LIMITS.p2 (no-connect)
  - source: sheet MAIN MCU ESP32-S3 N16R8; the author
- **GPIO5** — GPIO5 with pull-up and cap leaves on LIMITS pin 3.
  - members: U63.5, 10kΩ@130.81,74.93.#2, 0.1uF@121.92,74.93.#2, U70.p3, S3_LIMITS.p3
  - source: sheet MAIN MCU ESP32-S3 N16R8
- **GPIO1 / GND** — Power-detect harness: pin 1 GPIO1, pin 2 GND and shield.
  - members: U63.1, 10kΩ@167.64,73.66.#2, U64.p2, S3_PWR_DET.p1, S3_PWR_DET.p2, U64.p1 (CABLE S/FTP = GND)
  - source: sheet MAIN MCU ESP32-S3 N16R8; the author
- **DIGIT harness** — Digit-select harness as drawn. Digit order truth is SC4.
  - members: S3_DIGIT.p1 GPIO40 / U67.p4, S3_DIGIT.p2 GPIO41 / U67.p3, S3_DIGIT.p3 GPIO42 / U67.p2, S3_DIGIT.p4 GPIO2 / U67.p1
  - source: sheet MAIN MCU ESP32-S3 N16R8; SC4
- **DISPLAY harness** — Segment harness as drawn on this sheet.
  - members: S3_DISPLAY.p1 GPIO6, p2 GPIO7, p3 GPIO15, p4 GPIO16, p5 GPIO17, p6 GPIO18, p7 GPIO8
  - source: sheet MAIN MCU ESP32-S3 N16R8
- **STEPPER harness** — Stepper harness.
  - members: S3_STEPPER.p1 GPIO12, p2 GPIO11, p3 GPIO10, p4 GPIO9
  - source: sheet MAIN MCU ESP32-S3 N16R8
- **UART harness** — Inter-MCU UART harness.
  - members: S3_UART.p1 GND / CABLE S/FTP, S3_UART.p2 S3_to_A32 (U63.13), S3_UART.p3 A32_to_S3 (U63.14)
  - source: sheet MAIN MCU ESP32-S3 N16R8
- **TUNER harness** — AS5600 harness with 10 kΩ pull-ups and 220 Ω series resistors at the S3 end.
  - members: U63.39 → 10k junction → 220Ω@167.64,92.71 → GPIO39 → S3_TUNER.p4, U63.38 → 10k junction → 220Ω@172.72,95.25 → GPIO38 → S3_TUNER.p3, S3_TUNER.p2 S3_3V3, S3_TUNER.p1 GND / CABLE S/FTP
  - source: sheet MAIN MCU ESP32-S3 N16R8; the author
- **RDA harness** — RDA5807M I2C pair only, no ground or supply conductor.
  - members: S3_RDA.p1 GPIO47 / U91.p2, S3_RDA.p2 GPIO48 / U91.p1
  - source: sheet MAIN MCU ESP32-S3 N16R8
- **FM LED harness** — Panel-lamp PWM harness.
  - members: S3_FM_LED.p2 GPIO21 / U62.p1, S3_FM_LED.p1 GND (local) + CABLE S/FTP / U62.p2
  - source: sheet MAIN MCU ESP32-S3 N16R8
- **U63 no-connect** — Same X'd signal pins as the main sheet.
  - members: RST, 43, 44, 37, 36, 35, 3, 46, 0, 45, 20, 19
  - source: sheet MAIN MCU ESP32-S3 N16R8

### On sheet: USB-C CONNECTORS

- **P2 (MAIN)** — Back-panel USB-C for the S3: carried through, VBUS and GND included, to the S3 board's native USB port.
  - members: P2.VBUS, P2.D-, P2.D+ and P2.GND (ord 4), each labelled 'TO MAIN MCU ESP32-S3'S USB-C' (a visual aide, not one conductor); P2's other three GND pins (A12, B1, B12) wired together, unlabelled
  - source: sheet USB-C CONNECTORS; the author; SC24
- **P1 (AUDIO)** — Back-panel USB-C for the A32: carried through, VBUS and GND included, to the audio MCU board's USB-C.
  - members: P1.VBUS, P1.D-, P1.D+ and P1.GND (ord 4), each labelled 'TO AUDIO MCU ESP32-WROOM USB-C' (a visual aide, not one conductor); P1's other three GND pins (A12, B1, B12) wired together, unlabelled
  - source: sheet USB-C CONNECTORS; the author; SC24

## 5. Audio MCU (ESP32, "A32") and the DS3231 RTC

### On the main sheet

- **A_3V3** — A32 3V3 pin on the A_3V3 bus, decoupled by 0.1 µF + 10 µF + 10 µF
  - members: U10.3V3, C20.#1 (0.1uF), C21.#1 (10uF), C22.#1 (10uF), label A_3V3(g)
  - source: the main sheet; the author; SC17
- **unnamed net** — 3V3 decoupling caps return to the top-right GND pin
  - members: U10.GND (ord 2), C20.#2, C21.#2, C22.#2
  - source: the main sheet
- **5VDC** — A32 5V pin on 5VDC, 0.1 µF + 100 µF
  - members: U10.5V, 0.1uF@76.20,180.34.#1, 100uF@80.01,180.34.#1, label 5VDC(g)
  - source: the main sheet
- **GND** — Left GND pin and 5V cap returns
  - members: U10.GND (ord 27), 0.1uF@76.20,180.34.#2, 100uF@80.01,180.34.#2, label GND(g)
  - source: the main sheet
- **GPIO36 input** — Front DPDT audio switch input: pin, 0.1 µF to GND at the pin, 1 kΩ to the ladder node. This is the **selector signal only**: on AUX the audio itself never reaches the A32 (§22).
  - members: U10.36, 1kΩ@80.01,147.32 (series), 0.1 µF to GND on the pin side, A_IO36 ladder node: 22kΩ.#1, 68kΩ.#1, DPDT_ON_OFF_ON.A
  - source: the main sheet; the author
- **A_IO35 (drawn A_IO34 until 2026-09-23; SC6 done)** — Volume pot wiper to GPIO35
  - members: U10.35, RV4.2
  - source: the main sheet; the author; SC6; firmware (§0)
- **A_IO33** — BT LED cathode to GPIO33 (active low)
  - members: U10.33, D29.K
  - source: label names across all drawings; the author; SC3; firmware (§0)
- **A_IO25** — BT pair button to GPIO25 (active low; SW2 pin 2 on GND)
  - members: U10.25, SW2.1
  - source: label names across all drawings; the author; SC3; firmware (§0)
- **S3_to_A32** — UART S3 GPIO13 -> A32 GPIO26
  - members: U10.26, U7.13
  - source: label names across all drawings
- **A32_to_S3** — UART A32 GPIO27 -> S3 GPIO14
  - members: U10.27, U7.14
  - source: label names across all drawings
- **A_IO22** — RTC SDA
  - members: U10.22, U8.SDA
  - source: label names across all drawings
- **A_IO21** — RTC SCL
  - members: U10.21, U8.SCL
  - source: label names across all drawings
- **A_IO19** — ADC data in
  - members: U10.19, PCM1802.DOUT
  - source: label names across all drawings
- **A_IO18** — Shared I2S bit clock
  - members: U10.18, PCM1802.BCK, U9.BCK
  - source: label names across all drawings
- **A_IO17** — Shared I2S word clock
  - members: U10.17, PCM1802.LRCK, U9.LRCK
  - source: label names across all drawings
- **A_IO4** — DAC data out
  - members: U10.4, U9.DIN, 100kΩ@116.84,24.13.#1
  - source: label names across all drawings
- **GPIO0 clock (A_IO0A, A_IO0D)** — SCK clock from GPIO0, one 33 Ω per converter branch at the A32: the branch named A_IO0A reaches the PCM1802 SCK, the branch named A_IO0D the PCM5102A SCK
  - members: U10.0, 33Ω@109.22,175.26 → A_IO0A → PCM1802.SCK, 33Ω@109.22,180.34 → A_IO0D → U9 (PCM5102A).SCK
  - source: the main sheet; the author; SC8
- **A_VDC** — RTC supply on A_VDC (= A_3V3 on sheet HERE (the star-point buses))
  - members: U8.VCC, label A_VDC(g); as drawn, the DS3231M symbol's eight hidden GND pins (#5–#12) also lie on this wire, and are disregarded because they are hidden — the fitted RTC is a DS3231 ZS-042-style module
  - source: the main sheet; label names across all drawings
- **GND** — RTC ground
  - members: U8.GND (visible), label GND(g)
  - source: the main sheet
- **no-connect** — Unused U10 pins carry X
  - members: U10.EN, 23, 39, 1, 34, 3, 32, GND ord 14, 5, 14, 16, 12, 13, 2, 9, 15, 10, 8, 11, 7, 6
  - source: the main sheet; the author (GPIO16 unused)

### On sheet: AUDIO MCU ESP32-WROOM-32

- **5VDC** — 5 V in on the A32_5VIN cable
  - members: U74.5V, 0.1uF@128.27,118.11.#1, 100uF.#1, U81.p1/2, A32_5VIN.p2/2
  - source: sheet AUDIO MCU ESP32-WROOM-32
- **GND** — 5 V input ground
  - members: U74.GND ord 27, 0.1uF@128.27,118.11.#2, 100uF.#2, U81.p2/2, A32_5VIN.p1/2
  - source: sheet AUDIO MCU ESP32-WROOM-32
- **A_3V3** — A32 3V3 pin feeds A_3V3 out on the +-3V3 cable, decoupled by C54 0.1uF, C55 10uF and C56 10uF (since the 2026-09-23 save; SC17 done)
  - members: U74.3V3, C54.#1 (0.1uF), C55.#1 (10uF), C56.#1 (10uF), U75.p1/2, A32_3V3.p1/2
  - source: sheet AUDIO MCU ESP32-WROOM-32; SC17
- **GND** — 3V3 cable ground, and the returns of C54, C55 and C56
  - members: U74.GND ord 2, C54.#2, C55.#2, C56.#2, U75.p2/2, A32_3V3.p2/2
  - source: sheet AUDIO MCU ESP32-WROOM-32
- **A_3V3** — 3V3 to the BT LED/button cable
  - members: U79.p4/4, A32_BT_LED.p1/4
  - source: sheet AUDIO MCU ESP32-WROOM-32
- **A_IO33** — BT LED (active low)
  - members: U74.33, U79.p3/4, A32_BT_LED.p2/4
  - source: sheet AUDIO MCU ESP32-WROOM-32; the author; firmware (§0)
- **GND** — BT cable ground (labels only)
  - members: U79.p2/4, A32_BT_LED.p3/4
  - source: sheet AUDIO MCU ESP32-WROOM-32
- **A_IO25** — BT pair button (active low)
  - members: U74.25, U79.p1/4, A32_BT_LED.p4/4
  - source: sheet AUDIO MCU ESP32-WROOM-32; the author; firmware (§0)
- **S3_to_A32** — UART RX
  - members: U74.26, U80.p1/3, A32_UART.p1/3
  - source: sheet AUDIO MCU ESP32-WROOM-32
- **A32_to_S3** — UART TX
  - members: U74.27, U80.p2/3, A32_UART.p2/3
  - source: sheet AUDIO MCU ESP32-WROOM-32
- **GND + CABLE S/FTP** — UART cable GND and shield/foil terminated at board side
  - members: U80.p3/3, A32_UART.p3/3
  - source: sheet AUDIO MCU ESP32-WROOM-32; the author
- **GND + CABLE S/FTP** — Switch cable ground/shield; ladder and filter returns
  - members: U78.p3/3, A32_SWITCH.p1/3, 22kΩ.#1, 0.1uF@135.89,77.47.#1
  - source: sheet AUDIO MCU ESP32-WROOM-32; the author
- **A_IO36_H** — Ladder node (H = 3.3 V level)
  - members: U78.p2/3, A32_SWITCH.p2/3, 22kΩ.#2, 68kΩ.#1, 1kΩ.#2
  - source: sheet AUDIO MCU ESP32-WROOM-32; the author
- **A_IO36_L** — L leg through 68 kΩ (0.8 V level)
  - members: U78.p1/3, A32_SWITCH.p3/3, 68kΩ.#2
  - source: sheet AUDIO MCU ESP32-WROOM-32; the author
- **GPIO36 pin node** — Pin node with 0.1 µF at the pin
  - members: U74.36, 1kΩ.#1, 0.1uF@135.89,77.47.#2
  - source: sheet AUDIO MCU ESP32-WROOM-32; the author
- **A_IO21** — RTC SCL out
  - members: U74.21, U76.p3/3, A32_RTC.p1/3
  - source: sheet AUDIO MCU ESP32-WROOM-32
- **GND + CABLE S/FTP** — RTC cable ground/shield
  - members: U76.p2/3, A32_RTC.p2/3
  - source: sheet AUDIO MCU ESP32-WROOM-32; the author
- **A_IO22** — RTC SDA out
  - members: U74.22, U76.p1/3, A32_RTC.p3/3
  - source: sheet AUDIO MCU ESP32-WROOM-32
- **A_IO19** — I2S ADC data
  - members: U74.19, U77.p1/7, A32_I2S.p7/7
  - source: sheet AUDIO MCU ESP32-WROOM-32
- **A_IO18** — I2S BCK
  - members: U74.18, U77.p2/7, A32_I2S.p6/7
  - source: sheet AUDIO MCU ESP32-WROOM-32
- **GND + CABLE S/FTP** — I2S cable ground/shield
  - members: U77.p3/7, A32_I2S.p5/7
  - source: sheet AUDIO MCU ESP32-WROOM-32; the author
- **A_IO17** — I2S LRCK
  - members: U74.17, U77.p4/7, A32_I2S.p4/7
  - source: sheet AUDIO MCU ESP32-WROOM-32
- **A_IO0A — GPIO0 clock branch to the ADC (through 33Ω@167.64,102.87)** — One of the two GPIO0 clock branches, each with its own 33 Ω, both at the A32's pin. Since the 2026-09-23 save this branch is named A_IO0A, the name the PCM1802 sheet puts on the ADC's SCK (ADC_I2S.p6/6, U23.p6/6).
  - members: 33Ω@167.64,102.87.#2, U77.p5/7, A32_I2S.p3/7
  - source: the author; SC7; SC8; sheet AUDIO MCU ESP32-WROOM-32
- **A_IO4** — I2S DAC data
  - members: U74.4, U77.p6/7, A32_I2S.p2/7
  - source: sheet AUDIO MCU ESP32-WROOM-32
- **A_IO0D — GPIO0 clock branch to the DAC (through 33Ω@167.64,107.95)** — The second GPIO0 clock branch. Since the 2026-09-23 save it is named A_IO0D, the name the PCM5102A sheet puts on the DAC's SCK (U13.p6/6, U14.p1/6).
  - members: 33Ω@167.64,107.95.#2, U77.p7/7, A32_I2S.p1/7
  - source: sheet AUDIO MCU ESP32-WROOM-32; SC8
- **GPIO0 node** — GPIO0 splits into two 33 Ω at the pin
  - members: U74.0, 33Ω@167.64,107.95.#1, 33Ω@167.64,102.87.#1
  - source: sheet AUDIO MCU ESP32-WROOM-32; SC8
- **A_IO35** — Volume pot wiper to GPIO35
  - members: U74.35, U45.p2/2, A32_VOL.p1/2
  - source: sheet AUDIO MCU ESP32-WROOM-32; the author; SC6; firmware (§0)
- **GND + CABLE S/FTP** — Volume cable ground/shield
  - members: U45.p1/2, A32_VOL.p2/2
  - source: sheet AUDIO MCU ESP32-WROOM-32; the author
- **no-connect** — Unused pins with X. GND ord 14 is not one of them: since the 2026-09-23 save it carries a local GND label at the pin, and nothing else is on its wire.
  - members: U74.EN, 23, 39, 1, 34, 3, 32, 5, 14, 16, 12, 13, 2, 9, 15, 10, 8, 11, 7, 6
  - source: sheet AUDIO MCU ESP32-WROOM-32; SC17

### On sheet: DS3231 RTC (file renamed from DS3132 2026-09-23)

- **A_VDC = VCC** — RTC module supply from A_VDC
  - members: RTC_3V3.p1/2, U15.p2/2
  - source: sheet DS3231 RTC; the author
- **GND** — Supply header ground
  - members: RTC_3V3.p2/2, U15.p1/2
  - source: sheet DS3231 RTC
- **RTC_I2C 4th position — not connected** — The RTC_I2C 4th position is not connected. As drawn, RTC_I2C and U16 put p1/4 and p2/4 on no-connect, p3/4 on A_IO22 (SDA) and p4/4 on A_IO21 (SCL) (SCV6 done: the 2026-09-23 save draws RTC_I2C with two of its four positions connected, which is right).
  - members: RTC_I2C.p1/4 and p2/4, U16.p1/4 and p2/4: all drawn no-connect
  - source: the author; sheet DS3231 RTC
- **A_IO22 = SDA** — Module SDA to A32 GPIO22
  - members: RTC_I2C.p3/4, U16.p3/4
  - source: sheet DS3231 RTC
- **A_IO21 = SCL** — Module SCL to A32 GPIO21, drawn on RTC_I2C p4/4 and U16 p4/4; p1/4 and p2/4 are drawn no-connect (the 2026-09-23 save, which is right: it is a 4-pin JST with only 2 pins connected). The RTC_I2C 4th position is not connected; "4th position" counts the positions from one end, and the drawing's contact order does not settle which one that is (contact order inside a connector is not covered).
  - members: RTC_I2C.p4/4, U16.p4/4
  - source: sheet DS3231 RTC; the author
- **no-connect (as drawn)** — As drawn, p2/4 of the RTC I2C header is also no-connect; see the 4th-position entry above (SCV6 done 2026-09-23).
  - members: RTC_I2C.p2/4, U16.p2/4
  - source: sheet DS3231 RTC; the author

## 6. Audio converters: PCM1802 ADC, tube radio input, radio transformer output, PCM5102A DAC

### On the main sheet

- **5VDC (PCM1802 supply)** — The PCM1802 module's 5V pin is on 5VDC, with 100 µF and 0.1 µF (both fitted) to GND.
  - members: PCM1802.5V, 100uF@78.74,50.80.#1, 0.1uF@78.74,54.61.#1, global label 5VDC
  - source: the main sheet; the author
- **GND (PCM1802 supply caps)** — The other side of both PCM1802 supply caps is GND.
  - members: 100uF@78.74,50.80.#2, 0.1uF@78.74,54.61.#2, global label GND
  - source: the main sheet
- **GND (PCM1802 straps)** — MODE1, MODE0, BYPAS, OSR and FMT1 are tied to the module's GND.
  - members: PCM1802.GND, PCM1802.MODE1, PCM1802.MODE0, PCM1802.BYPAS, PCM1802.OSR, PCM1802.FMT1, global label GND
  - source: the main sheet
- **(unnamed) FMT0** — FMT0 is wired to the module's own P_3V3 pin, and to nothing else.
  - members: PCM1802.FMT0, PCM1802.P_3V3
  - source: the main sheet
- **P_3V3 (label)** — PDW and FSY are joined to a global label P_3V3 that appears on no other drawing and is not wired to the module's P_3V3 pin.
  - members: PCM1802.PDW, PCM1802.FSY, global label P_3V3
  - source: the main sheet; label names across all drawings
- **A_IO17** — LRCK of both converters is A32 GPIO17.
  - members: PCM1802.LRCK, U9.LRCK (#15), U10 GPIO17
  - source: label names across all drawings
- **A_IO18** — BCK of both converters is A32 GPIO18.
  - members: PCM1802.BCK, U9.BCK (#13), U10 GPIO18
  - source: label names across all drawings
- **A_IO19** — The ADC's data output goes to A32 GPIO19.
  - members: PCM1802.DOUT, U10 GPIO19
  - source: label names across all drawings
- **J51 — the radio jack (drawn as J42 before the correction)** — Cable side: sleeve on CABLE S/FTP, ring = RAD_L, tip = RAD_R (tip and ring interchangeable). Output side: sleeve and ring on GND, tip into the 4.7 kΩ. The radio output is mono.
  - members: J51.#S (ord1, output side) = GND, J51.#R (ord2, output side) = GND, J51.#S (ord3, cable side) = CABLE S/FTP, J51.#T (ord4, output side) → 4.7kΩ@92.71,90.17, J51.#R (ord5, cable side) = RAD_L, J51.#T (ord6, cable side) = RAD_R
  - source: the main sheet; the author
- **the attenuator node (LIN, and RIN in the hardware)** — The tip leg goes through the 4.7 kΩ to this node; a 1 kΩ and the 0.001 µF CBB22 capacitor C59 run from it to GND. It feeds the PCM1802's LIN by label, and its RIN in the hardware; the main sheet joins RIN to it by name since 2026-09-23 (SCH1 done).
  - members: 4.7kΩ@92.71,90.17.#2 ← J51.#T (ord4); 4.7kΩ@92.71,90.17.#1, 1kΩ@95.25,85.09.#2, C59.#1, label LIN → PCM1802.LIN; in the hardware also PCM1802.RIN
  - source: the main sheet; the author
- **GND (radio input)** — J51's output-side sleeve and ring, the 1 kΩ and C59 are on GND; so are the radio cable's shield and foil.
  - members: J51.#S (ord1), J51.#R (ord2), 1kΩ@95.25,85.09.#1, C59.#2, global label GND
  - source: the main sheet; the author
- **CABLE S/FTP (radio cable)** — J51's cable-side sleeve carries the radio cable's shield and foil.
  - members: J51.#S (ord3)
  - source: the main sheet; the author
- **RAD_L** — One end of the radio transformer secondary, with the 7.5 Ω 5 W load across it (marked 5W7Ω5J; drawn reference text 7.5Ω, Value 5W7.5Ω; the ±5% is irrelevant), to J51's cable-side ring (tip and ring interchangeable).
  - members: T1.SA, 7.5Ω.#1, J51.#R (ord5, cable side)
  - source: the main sheet; the author
- **RAD_R** — The other end of the transformer secondary (the 7.5 Ω 5 W load across the two) to J51's cable-side tip.
  - members: T1.SB, 7.5Ω.#2, J51.#T (ord6, cable side)
  - source: the main sheet; the author
- **50C5** — T1's primary is the tube radio's 50C5 output stage (the tube radio's internals: §13–§21).
  - members: T1.AA, T1.AB
  - source: the author
- **A_IO4** — DAC data input is A32 GPIO4, with a 100 kΩ (fitted) to GND.
  - members: U9.DIN (#14), 100kΩ@116.84,24.13.#1, U10 GPIO4
  - source: the main sheet; label names across all drawings; the author
- **GND (DIN pull-down)** — The DIN pull-down's other end is GND.
  - members: 100kΩ@116.84,24.13.#2, global label GND
  - source: the main sheet
- **5VDC (PCM5102A supply)** — The DAC module's VIN is on 5VDC with 100 µF, 10 µF ceramic and 0.1 µF, all fitted.
  - members: U9.VIN, C27.#1 (100 µF), C24.#1 (10 µF ceramic), C26.#1 (0.1 µF)
  - source: the main sheet; the author
- **GND (PCM5102A)** — The DAC module's GND and its supply caps are on GND.
  - members: U9.GND, C24.#2, C26.#2, C27.#2
  - source: the main sheet
- **GND (DAC straps)** — FLT, DEMP and FMT are tied to GND (normal-latency filter, de-emphasis off, I2S).
  - members: U9.FLT (#11), U9.DEMP (#10), U9.FMT (#16)
  - source: the main sheet
- **no-connect (XSMT is pulled up on the module)** — Nothing outside the module reaches XSMT or the module's A3V3 pin, and GPIO16 is unused. On the module XSMT is pulled up to the module's own 3.3 V, so the DAC is un-muted without any connection here.
  - members: U9.XSMT (#17), U9.A3V3, U10 GPIO16
  - source: the main sheet; the author; SC7
- **AMP_R+ / AMP_R- / AMP_L+ / AMP_L- (the four DAC-to-amp 470 Ω, drawn as a visual aide)** — The main sheet draws the four 470 Ω on U9's output pins. The main sheet is a visual aide that shows the resistances applied to the pins, not their exact emplacement. Where they are is the cable sheet's, and §6 "On sheet: THIS (cable) via SC13" and §12 carry it.
  - members: 470Ω@116.84,48.26 (#2 U9.OUTR (#7), #1 AMP_R+); 470Ω@116.84,55.88 (#2 U9.AGND (#9), #1 AMP_R-); 470Ω@116.84,60.96 (#1 U9.OUTL (#6), #2 AMP_L+); 470Ω@116.84,63.50 (#1 U9.AGND (#9), #2 AMP_L-); AMP_G on both drawn U9.AGND pins
  - source: the main sheet; the author

### On sheet: AUDIO MCU + THIS (cable) + PCM1802 ADC

- **clock at the ADC (A_IO0A)** — One of the two GPIO0 clock branches, each with its own 33 Ω, both at the A32's pin. Since the 2026-09-23 save the ADC's branch is named A_IO0A on every drawing: at the A32, GPIO0 → 33Ω@167.64,102.87 → A_IO0A → A32_I2S.p3/7; on the cable sheet A32_I2S.p3/7 and ADC_I2S.p6/6; on the PCM1802 sheet ADC_I2S.p6/6 and U23.p6/6 (SCK); on the main sheet 33Ω@109.22,175.26 → A_IO0A → PCM1802.SCK.
  - members: ADC_I2S.p6/6, U23.p6/6 (SCK), PCM1802.SCK
  - source: sheet AUDIO MCU ESP32-WROOM-32; the cable sheet; sheet PCM1802 ADC; SC8; SC7; the author

### On sheet: AUDIO MCU + THIS (cable) + PCM5102A DAC

- **clock at the DAC (A_IO0D)** — GPIO0 of the A32 feeds both the PCM1802 SCK and the PCM5102A SCK, each through its own 33 Ω, both at the A32's pin. Since the 2026-09-23 save the DAC's branch is named A_IO0D on every drawing: at the A32, GPIO0 → 33Ω@167.64,107.95 → A_IO0D → A32_I2S.p1/7; on the cable sheet A32_I2S.p1/7 and DAC_I2S.p1/6; on the PCM5102A sheet U13.p6/6 and U14.p1/6 (SCK); on the main sheet 33Ω@109.22,180.34 → A_IO0D → U9.SCK (#12).
  - members: DAC_I2S.p1/6, U13.p6/6 / U14.p1/6 (SCK), U9.SCK (#12)
  - source: the author; SC7; SC8

### On sheet: PCM1802 ADC

- **5VDC = 5VIN / GND** — The ADC module's 2-pin power header: + = 5VDC (left), - = GND (right).
  - members: U21.p1/2, ADC_5VIN.p1/2 (5VDC), U21.p2/2, ADC_5VIN.p2/2 (GND)
  - source: sheet PCM1802 ADC
- **I2S header** — The ADC's 6-pin I2S header, left to right as drawn.
  - members: U23/ADC_I2S p1 DOUT=A_IO19, p2 BCK=A_IO18, p3 no-connect, p4 LRCK=A_IO17, p5 no-connect, p6 SCK=A_IO0A
  - source: sheet PCM1802 ADC

### On sheet: PCM1802 ADC + THIS (cable)

- **RADIO_TO_ADC (= J42, drawn as J51 on the main sheet)** — Cable side: RAD_L on ring, RAD_R on tip, sleeve on CABLE S/FTP. Output side: ring and tip both labelled ATTENUATOR (into the main sheet's radio input), sleeve on GND.
  - members: RADIO_TO_ADC.#R (ord5) / J50.#R = RAD_L, RADIO_TO_ADC.#T (ord6) / J50.#T = RAD_R, RADIO_TO_ADC.#S (ord3) / J50.#S = CABLE S/FTP, RADIO_TO_ADC.#R (ord2) and #T (ord4) = ATTENUATOR, RADIO_TO_ADC.#S (ord1) = GND
  - source: sheet PCM1802 ADC, the cable sheet; the author
- **Ferrite cores on this cable (not drawn)** — Two clip-on cores, one near the tube radio transformer T1 end, one near the ADC end; the cable passes through each once. Measured: 10 mm OD, 3.5 mm ID, 3.5 mm walls, 20 mm long (the figures do not close: 3.5 + 3.5 + 3.5 is 10.5 against a 10 mm OD, so one is rounded). Material as supplied with the cores, with no maker, part number or grade: rectangle ratio 20, coercivity 16 A/m, remanence 200 mT, Curie temperature 130 °C, density 4.9 g/cm³, "Soft Magnetic".
  - source: the author

### On sheet: PCM5102A DAC

- **header** — The DAC's 6-pin header, left to right as drawn (no pull-down or caps drawn on this sheet; those are on the main sheet and fitted).
  - members: U13/U14 SCK=A_IO0D, BCK=A_IO18, DIN=A_IO4, LCK=A_IO17, GND, VIN=5VDC
  - source: sheet PCM5102A DAC; the author
- **module output jack J43, and plug J40 (DAC_OUT)** — The DAC module's 3-pole (TRS) output jack J43. Since the 2026-09-23 save the plug J40, Value DAC_OUT, is drawn on the same three nets. The cable sheet's plug J49 carries the same Value, DAC_OUT; no label name joins J40's poles to J49's, so the drawings do not say whether they are one plug.
  - members: J43.#S = J40.#S = AGND, J43.#R = J40.#R = OUTR, J43.#T = J40.#T = OUTL
  - source: sheet PCM5102A DAC; the author

### On sheet: THIS (cable) via SC13

- **AMP_L+** — DAC left out -> plug tip -> a 470 Ω at the DAC end of the cable -> amp input AMP_L+.
  - members: J43.#T (OUTL), J49.#T (plug DAC_OUT), 470Ω@212.09,40.64, AMP_IN.p3/9
  - source: the cable sheet; sheet PCM5102A DAC; the author; SC13
- **AMP_R+** — DAC right out -> plug ring -> a 470 Ω at the DAC end of the cable -> AMP_R+.
  - members: J43.#R (OUTR), J49.#R, 470Ω@212.09,30.48, AMP_IN.p7/9
  - source: the cable sheet; sheet PCM5102A DAC; the author; SC13
- **AMP_G** — DAC analog ground -> plug sleeve -> AMP_G, and to one end of both in-cable 470 Ω (the two on the − legs; all four signal legs carry a 470 Ω, the two others in series with AMP_L+ and AMP_R+ at the DAC end).
  - members: J43.#S (AGND), J49.#S, 470Ω@214.63,33.02.#1, 470Ω@214.63,38.10.#1, AMP_IN.p5/9
  - source: the cable sheet; sheet PCM5102A DAC; SC13
- **Ferrite cores on this cable (not drawn)** — Six cores, three at each end: one HDMI-type sleeve (17.4 mm OD, 9.7 mm ID, 28.5 mm long, the same type as the antenna feedpoint cores of §29), one small toroid (16 mm OD, 3 mm wall, 8 mm long) and one large toroid (22 mm OD, 4 mm wall, 8 mm long). The cable passes through each once; it is under 12 inches long, so no turns. The toroids are salvaged and unidentified: no maker, part number, grade or magnetic figure is recorded, and their material is not the clip-ons'.
  - source: the author
- **AMP_R-** — AMP_G through 470 Ω to AMP_R-.
  - members: 470Ω@214.63,33.02.#2, AMP_IN.p9/9
  - source: the cable sheet; SC13
- **AMP_L-** — AMP_G through 470 Ω to AMP_L-.
  - members: 470Ω@214.63,38.10.#2, AMP_IN.p1/9
  - source: the cable sheet; SC13

## 7. Volume pot, amp PSU 20 VDC, power detect, box and cage fans

*Specific to this build — adapt: the fans, the box and the amplifier's ±20 V supply suit this cabinet and this amplifier.*

### On the main sheet

- **+20V** — The amp PSU module's +20V output feeds the box-fan LM7812 input, with its 0.1uF and 100uF input caps, and the power-detect opto's 4.7kΩ LED resistor. The two drawn nets are joined by the +20V label.
  - members: U40.VI (#1), C14.#1, C15.#1, global label +20V @(132.08,130.81), U1.+20V, 4.7kΩ@264.16,171.45.#2, global label +20V @(260.35,168.91)
  - source: the main sheet
- **-20V** — The amp PSU -20V output goes only to a -20V label; no other drawing carries -20V.
  - members: U1.-20V, global label -20V @(255.27,179.07)
  - source: the main sheet; label names across all drawings
- **20V_GND** — The amp PSU's two 20V_GND pins are joined and return the PC817 input side (p3/4).
  - members: U1.20V_GND (ord 2/7), U1.20V_GND (ord 3/7), U6.p3/4 (LED cathode), global label 20V_GND @(255.27,173.99)
  - source: the main sheet
- **20V_GND (box-fan / LM7812 return; drawn unnamed as)** — The LM7812 ground, the low side of all four regulator caps, box fan M1's - and one end of D34 share one return. The drawing leaves it unnamed; it is 20V_GND.
  - members: U40.GND (#2), C13.#1, C14.#2, C15.#2, C16.#2, M1.-, D34.p1/2
  - source: the main sheet; the author
- **unnamed net 12 V box-fan rail** — The LM7812 output feeds box fan M1 +, with its output caps C13 0.1uF and C16 100uF and the other end of D34.
  - members: U40.VO (#3), C13.#2, C16.#1, M1.+, D34.p2/2
  - source: the main sheet
- **5VDC** — Cage fan M2 + is wired to the 5VDC bus.
  - members: M2.+, global label 5VDC @(134.62,144.78)
  - source: the main sheet
- **GND (cage fan)** — Cage fan M2 - is on GND.
  - members: M2.-, global label GND on pin @(125.73,144.78)
  - source: the main sheet
- **AC_L** — The amp PSU AC+ input is on AC_L, the switched side of the front-panel power toggle SW1; SW1.B is on AC_L_IN with J30.L and U4.AC+.
  - members: U1.AC+, SW1.A (by name,)
  - source: label names across all drawings; the main sheet
- **AC_N** — The amp PSU AC- input shares AC_N with the AC inlet J30 and the 5V PSU U4.
  - members: U1.AC-, J30.N (by name,), U4.AC- (by name,)
  - source: label names across all drawings
- **Earth** — The amp PSU EARTH pin is on the Earth node with the AC inlet earth, the Faraday-cage label and the antenna jack's shell.
  - members: U1.EARTH (power:Earth symbol on pin), J30.E (power:Earth), FARADAY_CAGE label net, J10 shell 'Ext' (per SC30)
  - source: the main sheet; SC30
- **unnamed net** — The 4.7kΩ resistor's pin 1 touches PC817 p1/4 (LED anode) directly, pin to pin.
  - members: 4.7kΩ@264.16,171.45.#1, U6.p1/4 (LED anode)
  - source: the main sheet
- **GPIO1** — The PC817 output p2/4 is on GPIO1, the S3's pin 1, which is pulled up to S3_3V3 through 10kΩ@57.15,143.51.
  - members: U6.p2/4 (collector) (label on pin), U7.1 (S3 pin '1', by name), 10kΩ@57.15,143.51.#2 (by name)
  - source: the main sheet
- **S3_3V3 (pull-up)** — The GPIO1 pull-up's other end is on S3_3V3.
  - members: 10kΩ@57.15,143.51.#1
  - source: the main sheet
- **GND (opto)** — PC817 p4/4 (emitter) is on GND.
  - members: U6.p4/4 (emitter) (label on pin)
  - source: the main sheet
- **A_IO35 (drawn A_IO34 until 2026-09-23; SC6 done)** — The volume pot RV4 (Value B10K on the main sheet) has its wiper on the A32's GPIO35.
  - members: RV4.2 (wiper), U10 pin 35 (A32, by label)
  - source: the main sheet; SC6; the author; firmware (§0)
- **A_VDC (= A_3V3)** — Pot end 1 is on A_VDC, which sheet HERE (the star-point buses) names A_3V3 as well; on the main sheet A_3V3 is the A32's 3V3 pin.
  - members: RV4.1
  - source: the main sheet; sheet HERE (the star-point buses); label names across all drawings
- **GND (pot)** — Pot end 3 is on GND.
  - members: RV4.3
  - source: the main sheet

### On sheet: Power Detect

- **+20V** — The sub-sheet LED resistor is fed from +20V.
  - members: 4.7kΩ.#2 (label on pin)
  - source: sheet Power Detect
- **unnamed net** — The resistor touches PC817 p1/4 (LED anode) directly.
  - members: 4.7kΩ.#1, U83.p1/4 (LED anode)
  - source: sheet Power Detect
- **20V_GND** — PC817 p3/4 (LED cathode) is wired to 20V_GND.
  - members: U83.p3/4 (LED cathode)
  - source: sheet Power Detect
- **GPIO1** — PC817 p2/4 (collector) runs through the U84 JST to the POWER_DET cable end, on GPIO1.
  - members: U83.p2/4 (collector), U84.p2/2, POWER_DET.p2/2
  - source: sheet Power Detect
- **GND** — PC817 p4/4 (emitter) runs through the U84 JST to the POWER_DET cable end, on GND.
  - members: U83.p4/4 (emitter), U84.p1/2, POWER_DET.p1/2
  - source: sheet Power Detect

### On sheet: BOX FAN (the 12V box-fan harness; file renamed from VOLUME POT 2026-09-23)

- **+20V = VI** — Box-fan harness supply in: +20V, locally named VI.
  - members: FAN_IN.p1/2, U88.p1/2
  - source: sheet BOX FAN; the author
- **20V_GND = FAN_- = GND** — Box-fan harness return: 20V_GND, the fan's -, locally named GND.
  - members: FAN_IN.p2/2, U88.p2/2, FAN_OUT.p1/2, U87.p2/2
  - source: sheet BOX FAN; the author
- **FAN_+ = VO** — Box-fan harness output to the fan's +, locally named VO.
  - members: FAN_OUT.p2/2, U87.p1/2
  - source: sheet BOX FAN; the author

## 8. The Leditron clock display (four digits and the colon)

*Specific to this build — adapt: the display (digits of discrete segment LEDs, and the colon) is made for this front panel.*

- **Digit numbering** — Digit 1 is the rightmost digit (units of minutes); digits 2, 3 and 4 run leftwards from it. GPIO42 → digit 1, GPIO2 → 2, GPIO40 → 3, GPIO41 → 4 (SC4).

### On the main sheet

- **Colon** — 5VDC → 33 Ω → colon LED → variable resistor (stuck at 1.5 kΩ) → GND, as the 7-segment sub-sheet draws it; the variable sits at the colon module. The main sheet draws R17 (variable, 1.5 kΩ) and the 33 Ω both on the 5 V side of the LED; that placement is intentional (SC12 done).
  - members: 5VDC, 33 Ω, COLON1 (colon LED), variable resistor stuck at 1.5 kΩ, GND
  - source: the author; SC12
- **unnamed net (digit 1 common anode)** — All seven segment anodes of LEDITRON DIGIT 1 join on header J1 pin 8.
  - members: D1.A, D2.A, D3.A, D4.A, D5.A, D6.A, D7.A, J1.Pin_8
  - source: the main sheet
- **unnamed nets** — Digit 1 Seg A cathode to J1 pin 1.
  - members: D1.K, J1.Pin_1
  - source: the main sheet
- **unnamed nets** — Digit 1 Seg B cathode to J1 pin 2.
  - members: D3.K, J1.Pin_2
  - source: the main sheet
- **unnamed nets** — Digit 1 Seg C cathode to J1 pin 3.
  - members: D5.K, J1.Pin_3
  - source: the main sheet
- **unnamed nets** — Digit 1 Seg D cathode to J1 pin 4.
  - members: D6.K, J1.Pin_4
  - source: the main sheet
- **unnamed nets** — Digit 1 Seg E cathode to J1 pin 5.
  - members: D4.K, J1.Pin_5
  - source: the main sheet
- **unnamed nets** — Digit 1 Seg F cathode to J1 pin 6.
  - members: D2.K, J1.Pin_6
  - source: the main sheet
- **unnamed nets** — Digit 1 Seg G cathode to J1 pin 7.
  - members: D7.K, J1.Pin_7
  - source: the main sheet
- **unnamed net (digit 2 common anode)** — All seven segment anodes of LEDITRON DIGIT 2 join on header J8 pin 8.
  - members: D22.A, D23.A, D24.A, D25.A, D26.A, D27.A, D28.A, J8.Pin_8
  - source: the main sheet
- **unnamed nets** — Digit 2 cathodes, one net each: Seg A..G to J8 pins 1..7 (A=D24, B=D27, C=D28, D=D26, E=D23, F=D22, G=D25).
  - members: D24.K–J8.Pin_1, D27.K–J8.Pin_2, D28.K–J8.Pin_3, D26.K–J8.Pin_4, D23.K–J8.Pin_5, D22.K–J8.Pin_6, D25.K–J8.Pin_7
  - source: the main sheet
- **unnamed net (digit 3 common anode)** — All seven segment anodes of LEDITRON DIGIT 3 join on header J4 pin 8.
  - members: D15.A, D16.A, D17.A, D18.A, D19.A, D20.A, D21.A, J4.Pin_8
  - source: the main sheet
- **unnamed nets** — Digit 3 cathodes, one net each: Seg A..G to J4 pins 1..7 (A=D17, B=D20, C=D21, D=D19, E=D16, F=D15, G=D18).
  - members: D17.K–J4.Pin_1, D20.K–J4.Pin_2, D21.K–J4.Pin_3, D19.K–J4.Pin_4, D16.K–J4.Pin_5, D15.K–J4.Pin_6, D18.K–J4.Pin_7
  - source: the main sheet
- **unnamed net (digit 4 common anode)** — All seven segment anodes of LEDITRON DIGIT 4 join on header J3 pin 8.
  - members: D8.A, D9.A, D10.A, D11.A, D12.A, D13.A, D14.A, J3.Pin_8
  - source: the main sheet
- **unnamed nets** — Digit 4 cathodes, one net each: Seg A..G to J3 pins 1..7 (A=D10, B=D13, C=D14, D=D12, E=D9, F=D8, G=D11).
  - members: D10.K–J3.Pin_1, D13.K–J3.Pin_2, D14.K–J3.Pin_3, D12.K–J3.Pin_4, D9.K–J3.Pin_5, D8.K–J3.Pin_6, D11.K–J3.Pin_7
  - source: the main sheet
- **Header/socket pairs (drawn mating, not a file net)** — Each digit's LED-side header is drawn plugged into a bus-side socket at the same origin. Pin n reaches pin n only through the connector mating; the file does not join them.
  - members: J1 Conn_01x08_Pin over J5 Conn_01x08_Socket @158.75,68.58, J8 over J7 @191.77,68.58, J4 over J6 @233.68,68.58, J3 over J2 @266.70,68.58
  - source: the main sheet; Ambersong.kicad_sch '(at 5.08 7.62 180)' and '(at -5.08 7.62 0)'
- **SEG_A_BUS (by label name)** — Segment A bus: socket pin 1 of all four digits, linked by global label to the bus-driver 200 Ω.
  - members: J5.Pin_1, J7.Pin_1, J6.Pin_1, J2.Pin_1, 200Ω@270.51,101.60.#1
  - source: the main sheet; label names across all drawings
- **SEG_B_BUS (by label name)** — Segment B bus: socket pin 2 of all four digits, linked to the bus-driver 200 Ω.
  - members: J5.Pin_2, J7.Pin_2, J6.Pin_2, J2.Pin_2, 200Ω@264.16,104.14.#1
  - source: the main sheet; label names across all drawings
- **SEG_C_BUS (by label name)** — Segment C bus: socket pin 3 of all four digits, linked to the bus-driver 200 Ω.
  - members: J5.Pin_3, J7.Pin_3, J6.Pin_3, J2.Pin_3, 200Ω@256.54,106.68.#1
  - source: the main sheet; label names across all drawings
- **SEG_D_BUS (by label name)** — Segment D bus: socket pin 4 of all four digits, linked to the bus-driver 200 Ω.
  - members: J5.Pin_4, J7.Pin_4, J6.Pin_4, J2.Pin_4, 200Ω@247.65,109.22.#1
  - source: the main sheet; label names across all drawings
- **SEG_E_BUS (by label name)** — Segment E bus: socket pin 5 of all four digits, linked to the bus-driver 200 Ω.
  - members: J5.Pin_5, J7.Pin_5, J6.Pin_5, J2.Pin_5, 200Ω@238.76,111.76.#1
  - source: the main sheet; label names across all drawings
- **SEG_F_BUS (by label name)** — Segment F bus: socket pin 6 of all four digits, linked to the bus-driver 200 Ω.
  - members: J5.Pin_6, J7.Pin_6, J6.Pin_6, J2.Pin_6, 200Ω@229.87,114.30.#1
  - source: the main sheet; label names across all drawings
- **SEG_G_BUS (by label name)** — Segment G bus: socket pin 7 of all four digits, linked to the bus-driver 200 Ω. Like the other six, it is its own bus (SC29).
  - members: J5.Pin_7, J7.Pin_7, J6.Pin_7, J2.Pin_7, 200Ω@220.98,116.84.#1
  - source: the main sheet; label names across all drawings; SC29
- **D1 (by label name)** — Label D1 joins socket J5 pin 8 and the first digit P-MOSFET's drain; GPIO42 selects it (SC4), drawn through U5.I1.
  - members: J5.Pin_8, P-Mosfet.D
  - source: the main sheet; label names across all drawings; SC4
- **D2 (by label name)** — Label D2 joins socket J7 pin 8 and PFet1's drain; GPIO2 selects it (SC4), drawn through U5.I2.
  - members: J7.Pin_8, PFet1.D
  - source: the main sheet; label names across all drawings; SC4
- **D3 (by label name)** — Label D3 joins socket J6 pin 8 and PFet2's drain; GPIO40 selects it (SC4), drawn through U5.I3.
  - members: J6.Pin_8, PFet2.D
  - source: the main sheet; label names across all drawings; SC4
- **D4 (by label name)** — Label D4 joins socket J2 pin 8 and PFet3's drain; GPIO41 selects it (SC4), drawn through U5.I4.
  - members: J2.Pin_8, PFet3.D
  - source: the main sheet; label names across all drawings; SC4

### On sheet: 7 SEGMENTS 24H CLOCK DISPLAY

- **5V = 5VDC** — Colon harness supply contact to the 33 Ω.
  - members: COLON_IN.p2/2, U34.p1/2, 33Ω.#1, 5V(l), 5VDC(g)
  - source: sheet 7 SEGMENTS 24H CLOCK DISPLAY
- **unnamed nets** — 33 Ω to colon output connector U35, first contact.
  - members: 33Ω.#2, U35.p1/2
  - source: sheet 7 SEGMENTS 24H CLOCK DISPLAY
- **GND** — Colon harness GND contact to the variable resistor.
  - members: COLON_IN.p1/2, U34.p2/2, R99.#1 (variable resistor glued at 1.5 kΩ; R1 until 2026-09-23, SCE2), GND(l), GND(g)
  - source: sheet 7 SEGMENTS 24H CLOCK DISPLAY; the author
- **unnamed nets** — Variable resistor to colon output connector U35, second contact.
  - members: R99.#2, U35.p2/2
  - source: sheet 7 SEGMENTS 24H CLOCK DISPLAY
- **Note beside COLON_IN (verbatim)** — "Caution! This 5VDC cable's polarity is / reversed at the COLON_IN side compared to others!".
  - source: sheet 7 SEGMENTS 24H CLOCK DISPLAY; the author
- **SEG_A_BUS (aliases IN SEG A, D1..D4 SEG A)** — Segment A: first contact of the 7-way input and of all four 8-way digit outputs.
  - members: LEDITRON_IN.p1/7, U12.p1/7, U18.p1/8, U17.p1/8, U19.p1/8, U32.p1/8
  - source: sheet 7 SEGMENTS 24H CLOCK DISPLAY
- **SEG_B_BUS** — Segment B: second contact of input and all four digit outputs.
  - members: LEDITRON_IN.p2/7, U12.p2/7, U18.p2/8, U17.p2/8, U19.p2/8, U32.p2/8
  - source: sheet 7 SEGMENTS 24H CLOCK DISPLAY
- **SEG_C_BUS** — Segment C: third contact.
  - members: LEDITRON_IN.p3/7, U12.p3/7, U18.p3/8, U17.p3/8, U19.p3/8, U32.p3/8
  - source: sheet 7 SEGMENTS 24H CLOCK DISPLAY
- **SEG_D_BUS** — Segment D: fourth contact.
  - members: LEDITRON_IN.p4/7, U12.p4/7, U18.p4/8, U17.p4/8, U19.p4/8, U32.p4/8
  - source: sheet 7 SEGMENTS 24H CLOCK DISPLAY
- **SEG_E_BUS** — Segment E: fifth contact.
  - members: LEDITRON_IN.p5/7, U12.p5/7, U18.p5/8, U17.p5/8, U19.p5/8, U32.p5/8
  - source: sheet 7 SEGMENTS 24H CLOCK DISPLAY
- **SEG_F_BUS** — Segment F: sixth contact.
  - members: LEDITRON_IN.p6/7, U12.p6/7, U18.p6/8, U17.p6/8, U19.p6/8, U32.p6/8
  - source: sheet 7 SEGMENTS 24H CLOCK DISPLAY
- **SEG_G_BUS** — Segment G: seventh contact.
  - members: LEDITRON_IN.p7/7, U12.p7/7, U18.p7/8, U17.p7/8, U19.p7/8, U32.p7/8
  - source: sheet 7 SEGMENTS 24H CLOCK DISPLAY
- **D1** — Digit 1 common: fourth ordinal of the 4-way driver input to contact 8 of output '1'.
  - members: DRIVER_IN.p4/4, U33.p4/4, U18.p8/8
  - source: sheet 7 SEGMENTS 24H CLOCK DISPLAY
- **D2** — Digit 2 common to contact 8 of output '2'.
  - members: DRIVER_IN.p3/4, U33.p3/4, U17.p8/8
  - source: sheet 7 SEGMENTS 24H CLOCK DISPLAY
- **D3** — Digit 3 common to contact 8 of output '3'.
  - members: DRIVER_IN.p2/4, U33.p2/4, U19.p8/8
  - source: sheet 7 SEGMENTS 24H CLOCK DISPLAY
- **D4** — Digit 4 common: first ordinal of the driver input to contact 8 of output '4'.
  - members: DRIVER_IN.p1/4, U33.p1/4, U32.p8/8
  - source: sheet 7 SEGMENTS 24H CLOCK DISPLAY

## 9. Display drivers: digit select (P-MOSFETs) and segment sinks

### On the main sheet

- **digit 1 select** — GPIO42 → digit 1 (SC4): label GPIO42 → U5.I1 → U5.O1 = PFET1 → 1 kΩ → P-Mosfet gate; its drain is D1.
  - members: label GPIO42, U5.I1 (#1), U5.O1 (#16) = PFET1, 1kΩ@153.67,135.89, P-Mosfet (FQP27P06) gate, P-Mosfet.D = D1
  - source: SC4; the main sheet
- **digit 2 select** — GPIO2 → digit 2 (SC4): label GPIO2 → U5.I2 → PFET2 → PFet1; drain D2.
  - members: label GPIO2, U5.I2 (#2), U5.O2 (#15) = PFET2, 1kΩ@189.23,135.89, PFet1 (FQP27P06) gate, PFet1.D = D2
  - source: SC4; the main sheet
- **digit 3 select** — GPIO40 → digit 3 (SC4): label GPIO40 → U5.I3 → PFET3 → PFet2; drain D3.
  - members: label GPIO40, U5.I3 (#3), U5.O3 (#14) = PFET3, 1kΩ@224.79,135.89, PFet2 (FQP27P06) gate, PFet2.D = D3
  - source: SC4; the main sheet
- **digit 4 select** — GPIO41 → digit 4 (SC4): label GPIO41 → U5.I4 → PFET4 → PFet3; drain D4.
  - members: label GPIO41, U5.I4 (#4), U5.O4 (#13) = PFET4, 1kΩ@261.62,135.89, PFet3 (FQP27P06) gate, PFet3.D = D4
  - source: SC4; the main sheet
- **PFET1 / PFET2 / PFET3 / PFET4** — Each U5 output reaches its gate resistor by global label name only (no wire).
  - members: U5.O1 ↔ 1kΩ@153.67,135.89.#2, U5.O2 ↔ 1kΩ@189.23,135.89.#2, U5.O3 ↔ 1kΩ@224.79,135.89.#2, U5.O4 ↔ 1kΩ@261.62,135.89.#2
  - source: label names across all drawings; the main sheet
- **unnamed net (gates)** — Each P-FET gate is fed through 1 kΩ and pulled to 5VDC (its source) by 100 kΩ.
  - members: 1kΩ@153.67.#1, 100kΩ@160.02,138.43.#1, P-Mosfet.G, 1kΩ@189.23.#1, 100kΩ@195.58,138.43.#1, PFet1.G, 1kΩ@224.79.#1, 100kΩ@231.14,138.43.#1, PFet2.G, 1kΩ@261.62.#1, 100kΩ@267.97,138.43.#1, PFet3.G
  - source: the main sheet
- **5VDC (digit sources)** — Each digit's source, gate pull-up and one side (#1) of its 0.1 µF and 10 µF are on 5VDC.
  - members: P-Mosfet.S, 100kΩ@160.02.#2, 0.1uF@160.02,146.05.#1, 10uF@165.10,146.05.#1, PFet1.S, 100kΩ@195.58.#2, 0.1uF@195.58.#1, 10uF@200.66.#1, PFet2.S, 100kΩ@231.14.#2, 0.1uF@231.14.#1, 10uF@236.22.#1, PFet3.S, 100kΩ@267.97,138.43.#2, 0.1uF@267.97.#1, 10uF@273.05.#1
  - source: the main sheet
- **GND (digit caps)** — Each digit block's two capacitors return to GND.
  - members: 0.1uF@160.02.#2, 10uF@165.10.#2, 0.1uF@195.58.#2, 10uF@200.66.#2, 0.1uF@231.14.#2, 10uF@236.22.#2, 0.1uF@267.97.#2, 10uF@273.05.#2
  - source: the main sheet
- **D1 / D2 / D3 / D4** — The four P-FET drains are the digit outputs D1-D4.
  - members: P-Mosfet.D, PFet1.D, PFet2.D, PFet3.D
  - source: the main sheet
- **U5 power and unused pins** — Digit driver ground on GND; COM and channels 5-7 no-connect.
  - members: U5.GND (#8) → GND, U5.COM (#9) NC, U5.I5-I7, O5-O7 NC
  - source: the main sheet
- **segment inputs** — Seven S3 GPIOs drive U2 inputs 1-7 (segments A-G).
  - members: GPIO6 → U2.I1, GPIO7 → U2.I2, GPIO15 → U2.I3, GPIO16 → U2.I4, GPIO17 → U2.I5, GPIO8 → U2.I6, GPIO18 → U2.I7
  - source: the main sheet
- **U2 power and COM** — Segment driver ground on GND; COM no-connect.
  - members: U2.GND (#8) → GND, U2.COM (#9) NC
  - source: the main sheet
- **U2 outputs to first resistor** — Each U2 output feeds a 10 Ω.
  - members: U2.O1 – 10Ω@260.35,101.60.#2, U2.O2 – 10Ω@252.73,104.14.#2, U2.O3 – 10Ω@243.84,106.68.#2, U2.O4 – 10Ω@234.95,109.22.#2, U2.O5 – 10Ω@226.06,111.76.#2, U2.O6 – 10Ω@217.17,114.30.#2, U2.O7 – 10Ω@213.36,116.84.#2 (, pin on pin)
  - source: the main sheet
- **channel mid-nodes A-F** — On each channel A–F the 10 Ω and 200 Ω are in series, and the mid-node has its own 100 kΩ to 5VDC: the seven channels are separate, one 100 kΩ per segment (SC29 done).
  - members: 10Ω@260.35.#1 – 200Ω@270.51.#2 – 100kΩ@267.97,119.38.#1, 10Ω@252.73.#1 – 200Ω@264.16.#2 – 100kΩ@260.35,119.38.#1, 10Ω@243.84.#1 – 200Ω@256.54.#2 – 100kΩ@252.73,119.38.#1, 10Ω@234.95.#1 – 200Ω@247.65.#2 – 100kΩ@243.84,119.38.#1, 10Ω@226.06.#1 – 200Ω@238.76.#2 – 100kΩ@234.95,119.38.#1, 10Ω@217.17.#1 – 200Ω@229.87.#2 – 100kΩ@226.06,119.38.#1
  - source: the main sheet; the author; SC29
- **channel G mid-node** — Channel G mid-node with its 100 kΩ pull-up to 5VDC.
  - members: 10Ω@213.36,116.84.#1, 200Ω@220.98,116.84.#2, 100kΩ@217.17,119.38.#1
  - source: the main sheet
- **SEG_A_BUS..SEG_G_BUS** — Each 200 Ω output end is its segment bus. There are seven separate buses (SC29).
  - members: 200Ω@270.51.#1 = SEG_A_BUS, 200Ω@264.16.#1 = SEG_B_BUS, 200Ω@256.54.#1 = SEG_C_BUS, 200Ω@247.65.#1 = SEG_D_BUS, 200Ω@238.76.#1 = SEG_E_BUS, 200Ω@229.87.#1 = SEG_F_BUS, 200Ω@220.98.#1 = SEG_G_BUS
  - source: the main sheet; SC29
- **5VDC (segment pull-up row)** — The bottom ends of all seven segment-section 100 kΩ are on 5VDC.
  - members: 100kΩ@217.17/226.06/234.95/243.84/252.73/260.35/267.97 ,119.38 .#2, 5VDC global label (275.59,121.92)
  - source: the main sheet
- **sheet box** — The sub-sheet box carries no sheet pins.
  - members: P-MOSFET DIGITS & P-MOSFET DIGIT DRIVER & 7 SEGMENTS BUS DRIVER box (153.03,90.17) 131.4x59.7, 0 pins
  - source: the main sheet

### On sheet: P-MOSFET DIGITS & P-MOSFET DIGIT DRIVER & 7 SEGMENTS BUS DRIVER

- **DISPLAY IN (segment inputs)** — The 7-pin JST DISPLAY_IN jack mates with header U24 and brings the seven segment GPIOs onto the driver board.
  - members: U24.p1/7–DISPLAY_IN.p1/7 GPIO6 = SEG DRIVER I1, p2 GPIO7 = I2, p3 GPIO15 = I3, p4 GPIO16 = I4, p5 GPIO17 = I5, p6 GPIO8 = I6, p7 GPIO18 = I7
  - source: sheet P-MOSFET DIGITS & P-MOSFET DIGIT DRIVER & 7 SEGMENTS BUS DRIVER
- **DISPLAY OUT (segment buses)** — Header U20 and jack DISPLAY_OUT carry the seven separate segment buses out to the display.
  - members: U20.p1/7–DISPLAY_OUT.p1/7 SEG DRIVER O1 = SEG_A_BUS, p2 O2 = SEG_B_BUS, p3 O3 = SEG_C_BUS, p4 O4 = SEG_D_BUS, p5 O5 = SEG_E_BUS, p6 O6 = SEG_F_BUS, p7 O7 = SEG_G_BUS
  - source: sheet P-MOSFET DIGITS & P-MOSFET DIGIT DRIVER & 7 SEGMENTS BUS DRIVER
- **DIGIT IN** — The 4-pin DIGIT_IN cable brings the four digit-select GPIOs, in the SC4 order.
  - members: U29.p1/4–DIGIT_IN.p1/4 = P_MOSFET I1 ← GPIO42 (digit 1), p2 = I2 ← GPIO2 (digit 2), p3 = I3 ← GPIO40 (digit 3), p4 = I4 ← GPIO41 (digit 4)
  - source: SC4; sheet P-MOSFET DIGITS & P-MOSFET DIGIT DRIVER & 7 SEGMENTS BUS DRIVER
- **DIGIT OUT** — The four drain outputs leave on the 4-pin DIGIT_OUT jack; header pin order is reversed relative to the jack's.
  - members: U26.p4/4–DIGIT_OUT@184.15,102.87.p1/4 = P_MOSFET O1 = D1, U26.p3/4–p2/4 = O2 = D2, U26.p2/4–p3/4 = O3 = D3, U26.p1/4–p4/4 = O4 = D4
  - source: sheet P-MOSFET DIGITS & P-MOSFET DIGIT DRIVER & 7 SEGMENTS BUS DRIVER
- **GND X2** — The GND×2 pair is the cable shield + foil terminating at the perfboard's common GND. DIGIT_OUT and DIGIT_OUT1 are one cable split by two JSTs.
  - members: U22.p1/2–DIGIT_OUT@184.15,77.47.p1/2 GND, U22.p2/2–DIGIT_OUT@184.15,77.47.p2/2 GND
  - source: the author; sheet P-MOSFET DIGITS & P-MOSFET DIGIT DRIVER & 7 SEGMENTS BUS DRIVER
- **VDC IN** — The driver board's 5 V and ground come in on the 2-pin DRIVERS_5VIN jack.
  - members: U28.p1/2–DRIVERS_5VIN.p1/2 GND, U28.p2/2–DRIVERS_5VIN.p2/2 5VDC
  - source: sheet P-MOSFET DIGITS & P-MOSFET DIGIT DRIVER & 7 SEGMENTS BUS DRIVER

## 10. Power distribution, mains side, earth and antenna

### On the main sheet

- **AC_L_IN** — Mains live from the IEC C14 inlet. It feeds the front-panel toggle's inlet side and, by the same name, the 5 V PSU's AC+. As drawn, the 5 V PSU sits ahead of the toggle.
  - members: J30.L (#1), SW1.B (#2), U4.AC+
  - source: the main sheet; label names across all drawings
- **AC_L** — Switched live from the front-panel power toggle SW1, to the amp PSU.
  - members: SW1.A (#1), U1.AC+ (AMP PSU, other group)
  - source: the main sheet; label names across all drawings
- **AC_N** — Mains neutral from the inlet, to the 5 V PSU and the amp PSU.
  - members: J30.N (#2), U4.AC-, U1.AC- (AMP PSU, other group)
  - source: label names across all drawings
- **Earth** — Earth: the inlet's E pin, the amp PSU earth, the radio's Faraday cage and the antenna connector's shell. Earth is a global power name, so these are one net. A Faraday cage sits over the AC line filter (between the tube radio's mains input and Ambersong's AC input, after the front power switch), bonded to the same earth; it is not drawn.
  - members: J30.E (#3) via #PWR03, U1.EARTH via #PWR04 (other group), FARADAY_CAGE label via #PWR01, J10.Ext (#2, coax shell)
  - source: the main sheet, with its Earth power symbol description; SC30
- **Earth and GND are joined in the machine, not on the drawings** — The amp's ground reaches the earth star point on its back aluminium plate through a washer on its Bass pot, so the DC-side GND is on mains earth at almost 0 Ω (§30.4).
  - source: the author
- **ANT** — Antenna signal on the coax connector's centre pin. The name ANT appears on no other drawing, so its destination is not drawn; the antenna (any FM/VHF antenna works, and the author made one for this) is §29, as built and installed. J10 is deliberately just a coax connector: it was F-type and is now a BNC male (the type does not matter).
  - members: J10.In (#1, coax centre)
  - source: SC30; label names across all drawings
- **FARADAY_CAGE = Earth** — The Faraday cage over the tube radio is bonded to Earth. Note B30 also says the cage over the AS5600 goes to EARTH (text only, no drawn symbol).
  - members: global label FARADAY_CAGE (134.62,162.56), #PWR01 Earth (128.27,167.64)
  - source: the main sheet
- **5VDC (= 5VDC_S)** — The 5 V PSU output feeds the 5 V star-point bus, 15 positions, drawn on the bus sub-sheet (box HERE) only: the main sheet no longer draws the bus. On the drawings 5VDC_S is on U4.5VDC alone; it is 5VDC, 5VDC_S being only the pre-bus name.
  - members: U4.5VDC (5VDC_S); by name, every 5VDC label on every drawing, the bus sub-sheet's 15 5 VDC positions included (On sheet: HERE (the star-point buses), below)
  - source: the main sheet; sheet HERE (the star-point buses); label names across all drawings; the author; SC15
- **GND (= PSU_GND)** — All the grounds are joined at a single star point, represented by the JST 2-pin buses (note B29). PSU_GND is the pre-bus name for GND.
  - members: U4.GND (PSU_GND); by name, every GND label on every drawing, the bus sub-sheet's GND pins included (On sheet: HERE (the star-point buses), below)
  - source: the main sheet; sheet HERE (the star-point buses); the author
- **A_VDC / A_3V3 bus** — The 5-position 3.3 VDC JST 2-pin bus, drawn on the bus sub-sheet (box HERE) only since the main sheet's drawing of the buses was removed; supplied from the A32's 3V3 pin with its three decoupling caps on the main sheet.
  - members: A_3V3 by name: U10.3V3 with C20 0.1 µF, C21 10 µF, C22 10 µF (main sheet); bus sub-sheet U52–U56 p1/2 with A32_VDC.p1/2 and A32_3V3.p1/2 (A_3V3 = A_VDC), U52–U56 p2/2 on GND
  - source: the main sheet; sheet HERE (the star-point buses); label names across all drawings; SC17; the author
- **SW1 placement** — SW1 (SPST, block 'FRONT PANEL / POWER TOGGLE') sits in the live leg between AC_L_IN and AC_L.
  - members: SW1.B on AC_L_IN, SW1.A on AC_L
  - source: the main sheet

### On sheet: HERE (the star-point buses)

- **A_3V3 = A_VDC** — The + pin of all five 3.3 VDC connectors is one wire. It joins the A32_VDC jack and the A32_3V3 jack, so A_VDC and A_3V3 are drawn as one net here.
  - members: U56.p1/2, U55.p1/2, U54.p1/2, U53.p1/2, U52.p1/2, A32_VDC.p1/2 (label A_VDC), A32_3V3.p1/2 (label A_3V3)
  - source: sheet HERE (the star-point buses)
- **GND** — A wired ground covering the 3.3 VDC column, both A32 jacks and the first 5 VDC column.
  - members: U56..U52 p2/2, A32_VDC.p2/2, A32_3V3.p2/2, U61..U57 p1/2
  - source: sheet HERE (the star-point buses)
- **5VDC** — The + pins of the first 5 VDC column (drawn block B5).
  - members: U61.p2/2, U60.p2/2, U59.p2/2, U58.p2/2, U57.p2/2
  - source: sheet HERE (the star-point buses)
- **GND** — A wired ground for the second and third 5 VDC columns (drawn blocks B6, B7). It joins by the name GND.
  - members: U51..U47 p1/2, U46.p1/2, U31.p1/2, U30.p1/2, U27.p1/2, U25.p1/2
  - source: sheet HERE (the star-point buses)
- **5VDC** — The + pins of the columns in drawn blocks B6 and B7. It joins by the name 5VDC. With block B5, that makes 15 5 VDC positions.
  - members: U51..U47 p2/2, U46.p2/2, U31.p2/2, U30.p2/2, U27.p2/2, U25.p2/2
  - source: sheet HERE (the star-point buses); SC15

## 11. Stepper and index sensor, AS5600, RDA5807M, panel lamps, BT button/LED, audio source switch

*Specific to this build — adapt: the dial-needle drive (the stepper, its index sensor, the AS5600 and its magnet), the panel lamps and the front-panel controls suit this cabinet and this dial.*

### On the main sheet

- **GPIO9 / GPIO10 / GPIO11 / GPIO12** — S3 GPIO9, 10, 11, 12 drive ULN2003A inputs I1, I2, I3, I4 (linked by global label names).
  - members: U3.I1 (#1), U3.I2 (#2), U3.I3 (#3), U3.I4 (#4), U7.9, U7.10, U7.11, U7.12
  - source: the main sheet
- **unnamed net** — ULN2003A outputs O1-O4 go to stepper socket J9 pins 1-4 ('To 28BYJ-48'). J9 is the connector that comes with the common ULN2003A boards.
  - members: U3.O1 (#16)-J9.Pin_1, U3.O2 (#15)-J9.Pin_2, U3.O3 (#14)-J9.Pin_3, U3.O4 (#13)-J9.Pin_4
  - source: the main sheet
- **5VDC** — ULN2003A COM and the motor common (J9 pin 5) are on 5VDC, with 0.1 µF and 47 µF to GND.
  - members: U3.COM (#9), J9.Pin_5, 0.1uF@142.24,101.60.#1, 47uF.#1
  - source: the main sheet
- **GND** — Stepper driver decoupling returns and ULN2003A GND pin to GND.
  - members: 0.1uF@142.24,101.60.#2, 47uF.#2, U3.GND (#8)
  - source: the main sheet
- **5VDC / GND** — A3144 Hall sensor U42 on 5VDC with C17 0.1 µF across its supply.
  - members: U42.VCC, C17.#1, U42.GND, C17.#2
  - source: the main sheet
- **GPIO5** — Hall output to S3 GPIO5, pulled up to S3_3V3 by 10 kΩ, 0.1 µF to GND at the S3.
  - members: U42.OUT, U7.5, 10kΩ@27.94,143.51 (to S3_3V3), 0.1uF@19.02,151.13 (to GND)
  - source: the main sheet; label names across all drawings
- **S3_3V3 / GND** — AS5600 module on S3_3V3; GND; DIR tied to GND. Its magnet is a 6 × 3 mm disc neodymium magnet, less than 0.5 mm from the IC.
  - members: U11.VCC, U11.GND, U11.DIR
  - source: the main sheet
- **GPIO38 (AS5600 SDA)** — AS5600 SDA → 220 Ω → S3 GPIO38, with 10 kΩ pull-up to S3_3V3 at the pin.
  - members: U11.SDA, 220Ω@58.42,166.37, U7.38, 10kΩ@58.42,161.29 to S3_3V3
  - source: the main sheet; the author
- **GPIO39 (AS5600 SCL)** — AS5600 SCL → 220 Ω → S3 GPIO39, with 10 kΩ pull-up to S3_3V3 at the pin.
  - members: U11.SCL, 220Ω@63.50,158.75, U7.39, 10kΩ@60.96,160.02 to S3_3V3
  - source: the main sheet; the author
- **GPIO47 / GPIO48** — RDA5807M SDIO on S3 GPIO47, SCLK on GPIO48; no external pull-ups.
  - members: U89.SDIO (#5), U7.47, U89.SCLK (#4), U7.48
  - source: the main sheet; the author
- **30CM_ANT** — RDA5807M ANT carries only the local label 30CM_ANT: a 30 cm length of wire inside the tube radio's Faraday cage, bent in a U over the FM oscillator section. The RDA module reaches that wire through U71, a 2×3 pin grid that lets someone making repairs unplug the module from the antenna (drawn on sheet RDA5807M).
  - members: U89.ANT
  - source: the main sheet
- **S3_3V3 / GND — RDA supply** — RDA5807M VDD on S3_3V3, GND on GND; 100 µF electrolytic, 10 µF and 0.1 µF ceramic each directly across VDD–GND.
  - members: U89.VDD (#7), U89.GND (#1), C28 100uF, C29 0.1uF, C30 10uF
  - source: the main sheet; SC14
- **RDA no-connects** — RCLK, IO1, IO2, ROUT, LOUT have no-connect X.
  - members: U89.RCLK (#6), U89.IO1, U89.IO2, U89.ROUT (#9), U89.LOUT (#10)
  - source: the main sheet
- **5VDC** — Panel lamp LED anodes (LED 1-4) on 5VDC.
  - members: D30.A, D31.A, D32.A, D33.A
  - source: the main sheet
- **unnamed nets** — Each LED cathode goes through its own 120 Ω.
  - members: D30.K-120Ω@95.25,101.60.#2, D31.K-120Ω@95.25,106.68.#2, D32.K-120Ω@95.25,111.76.#2, D33.K-120Ω@95.25,116.84.#2
  - source: the main sheet; the author
- **unnamed net (drain)** — The four 120 Ω resistors join on the IRL540N drain.
  - members: Q1.D (#1), 120Ω@95.25,101.60.#1, 120Ω@95.25,106.68.#1, 120Ω@95.25,111.76.#1, 120Ω@95.25,116.84.#1
  - source: the main sheet; the author
- **unnamed net (gate) / GPIO21** — S3 GPIO21 → 100 Ω → Q1 gate; 100 kΩ and 220 pF from gate to GND.
  - members: Q1.G (#2), 100Ω.#1, 100kΩ@86.36,121.92.#2, 220pF.#1, 100Ω.#2 = GPIO21, U7.21
  - source: the main sheet; the author
- **GND** — Q1 source, gate pull-down and gate cap to GND.
  - members: Q1.S (#3), 100kΩ@86.36,121.92.#1, 220pF.#2
  - source: the main sheet; the author
- **A_IO25 / GND — BT pair button** — Pair button SW2 between A32 GPIO25 and GND (active low, INPUT_PULLUP).
  - members: SW2.1, U10.25, SW2.2 → GND
  - source: the main sheet; the author; SC3; firmware (§0)
- **A_VDC / A_IO33** — Front-panel BT LED D29: anode on A_VDC, cathode on A32 GPIO33 (drive low to light); no series resistor drawn.
  - members: D29.A, D29.K, U10.33
  - source: the main sheet; the author; SC3; firmware (§0)
- **A_VDC / A_IO36 / GND** — DPDT pins 2 and 5 on A_VDC; pin 1 straight to the A_IO36 node; pin 6 through 68 kΩ to it; 22 kΩ from the node to GND; pins 3 and 4 no-connect. The 22 k / 68 k are physically on the A32 board. Positions, from the firmware: the direct leg (pin 1) puts 3.3 V on GPIO36 = RADIO; the 68 kΩ leg (pin 6) puts 0.81 V = BT; the centre, off, leaves the 22 kΩ at 0 V = AUX. The A32 reads below 424 counts as AUX, 2471 and up as RADIO, and between as BT.
  - members: DPDT_ON_OFF_ON.B (#2), DPDT_ON_OFF_ON.B (#5), DPDT_ON_OFF_ON.A (#1), DPDT_ON_OFF_ON.C (#6)-68kΩ, 22kΩ to GND, DPDT C (#3) nc, DPDT A (#4) nc
  - source: the main sheet; the author; firmware (§0)
- **A_IO36 at the A32** — A_IO36 node → 1 kΩ → A32 GPIO36; the 0.1 µF to GND sits on the pin (A32) side.
  - members: 1kΩ@80.01,147.32, U10.36, 0.1uF@74.93,144.78
  - source: the main sheet; the author
- **no-connects (stepper, AS5600)** — ULN2003A channels 5-7 and AS5600 OUT carry no-connect X.
  - members: U3.I5, U3.I6, U3.I7, U3.O5, U3.O6, U3.O7, U11.OUT
  - source: the main sheet

### On sheet: STEPPER DRIVER

- **GPIO9-12 = ULN IN1-4** — 4-wire cable into the driver board's INPUT header, IN1-IN4 in GPIO order.
  - members: STEPPER_IN.p1/4-U38.p1/4 GPIO9, STEPPER_IN.p2/4-U38.p2/4 GPIO10, STEPPER_IN.p3/4-U38.p3/4 GPIO11, STEPPER_IN.p4/4-U38.p4/4 GPIO12
  - source: sheet STEPPER DRIVER
- **ULN OUT1-4 / ULN COM** — TO STEPPER header pins 1-4 carry OUT1-OUT4 (named coil 4..1); pin 5 is COM.
  - members: U39.p1/5 ULN OUT1 = STEPPER COIL 4, U39.p2/5 ULN OUT2 = STEPPER COIL 3, U39.p3/5 ULN OUT3 = STEPPER COIL 2, U39.p4/5 ULN OUT4 = STEPPER COIL 1, U39.p5/5 ULN COM = STEPPER COM
  - source: sheet STEPPER DRIVER
- **5VDC = ULN2003A COM / GND = ULN2003A GND** — Driver board power header: '+' 5VDC, '−' GND.
  - members: STEPPER_5VIN.p2/2, U37.p2/2, STEPPER_5VIN.p1/2, U37.p1/2
  - source: sheet STEPPER DRIVER

### On sheet: STEPPER LIMIT

- **5VDC = VCC / GND / GPIO5 = OUT** — Sensor cable: conductor 1 5VDC to VCC, 2 GND, 3 sensor OUT to GPIO5.
  - members: LIMIT.p1/3-U90.p3/3, LIMIT.p2/3-U90.p2/3, LIMIT.p3/3-U90.p1/3
  - source: sheet STEPPER LIMIT

### On sheet: RDA5807M

- **GPIO47 = SDA / GPIO48 = SCL** — I2C cable conductor 1 SDA (GPIO47), 2 SCL (GPIO48).
  - members: RDA_I2C.p1/3-U92.p3/3, RDA_I2C.p2/3-U92.p2/3
  - source: sheet RDA5807M
- **CABLE S/FTP (labelled GND at module header)** — Third conductor = cable shield + foil, terminated to GND at the board side and open at the cable's other end (S3_RDA at the S3 is 2-pin).
  - members: RDA_I2C.p3/3, U92.p1/3
  - source: sheet RDA5807M; label names across all drawings; the author
- **S3_3V3 = VDD / GND** — 3V3 cable '+' S3_3V3, '−' GND; C18 100 µF (polarized), C31 10 µF and C19 0.1 µF across the supply at the module (SC14 done 2026-09-23).
  - members: RDA_3V3.p2/2-U93.p1/2, C18 100uF (polarized), C31 10uF, C19 0.1uF, RDA_3V3.p1/2-U93.p2/2
  - source: sheet RDA5807M; SC14
- **30CM_ANT / U71 — the antenna plug** — U71 is a 2×3 pin grid that physically connects the RDA5807M module to the antenna, so someone making repairs can unplug the module from the antenna there. Its symbol is drawn without pins. The label 30CM_ANT (the same as the main sheet's 30CM_ANT) is drawn reaching no pin.
  - members: U71 (Mine:2x3_Pin_GRID, drawn without pins), label 30CM_ANT (reaches no pin)
  - source: sheet RDA5807M; the author

### On sheet: PANEL RADIO LED PWM CONTROL

- **GPIO21 / 5VDC / GND** — PWM board input: GPIO21 via 100 Ω to the MOSFET gate, 5VDC out through 5VOUT to the LED anodes, GND = source.
  - members: RLPC_IN.p1/3-U82.p3/3 GPIO21 → 100Ω → gate, RLPC_IN.p2/3-U82.p2/3 5VDC → U85.p1/2, U85.p2/2 → D46-D49 anodes, RLPC_IN.p3/3-U82.p1/3 GND = S
  - source: sheet PANEL RADIO LED PWM CONTROL; SC33
- **LEDS RTN** — Each LED cathode returns through LEDS RTN to its own 120 Ω; the four resistors join on the MOSFET drain.
  - members: U86.p1/4-D46.K, U86.p2/4-D47.K, U86.p3/4-D48.K, U86.p4/4-D49.K, four LED resistors (120Ω) → drain
  - source: sheet PANEL RADIO LED PWM CONTROL; SC2; SC33

### On sheet: BLUETOOTH PAIR BUTTON & FRONT PANEL BLUETOOTH LED & DPDT ON-OFF-ON AUDIO SWITCH

- **A_IO25 / A_3V3 / A_IO33 / GND** — Pair button between GPIO25 and GND; LED anode on A_3V3 (= A_VDC), cathode on GPIO33.
  - members: SW4 → A_IO25, SW4 other side → GND (A32_BT_LED.p4/4, U36.p4/4), LED + → A_3V3 (A32_BT_LED.p2/4, U36.p2/4), LED − (cathode) → A_IO33
  - source: sheet BLUETOOTH PAIR BUTTON & FRONT PANEL BLUETOOTH LED & DPDT ON-OFF-ON AUDIO SWITCH; label names across all drawings; the author; SC3; firmware (§0)
- **A_VDC = 3V3 IN / A_IO36_H / A_IO36_L** — Three-wire switch cable through the IN/LISTENER/OUT board to the front DPDT switch; H is the leg that puts 3.3 V on the line, L the 0.8 V leg.
  - members: LISTENER.p1/3-U43.p1/3-U44.p1/3 A_VDC, LISTENER.p2/3-U43.p2/3-U44.p2/3 A_IO36_H, LISTENER.p3/3-U43.p3/3-U44.p3/3 A_IO36_L
  - source: sheet BLUETOOTH PAIR BUTTON & FRONT PANEL BLUETOOTH LED & DPDT ON-OFF-ON AUDIO SWITCH; the author

## 12. The cable harnesses (cable sheet "THIS")

The cable sheet is a visual aid: each harness is drawn as it looks when seen as drawn.

### On the main sheet

- **(none)** — G9 on the main sheet is only the note B31 with the sheet box 'THIS' over its blank. It has no parts, nets or sheet pins, so the cable sheet links to the main sheet only by label names.
  - members: THIS sheet symbol (0 sheet pins)
  - source: the main sheet
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

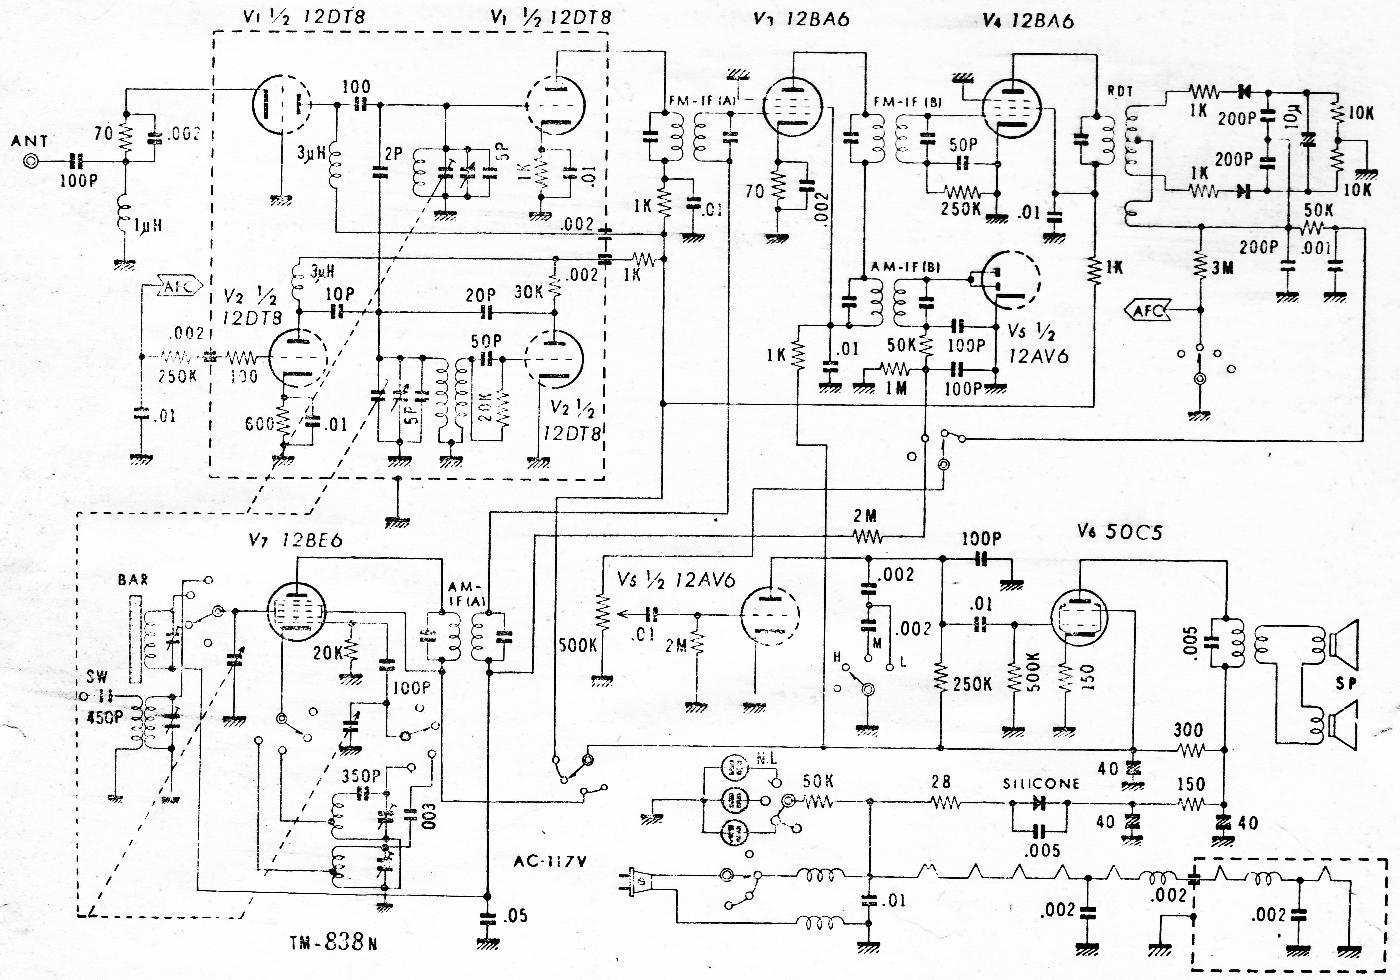
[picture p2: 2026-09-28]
hardware/schematics/LLOYDS TM-838 factory schematic.jpg

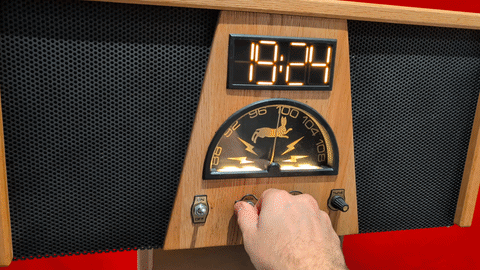
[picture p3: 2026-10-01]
photos/Ambersong - Power Down Animation.gif

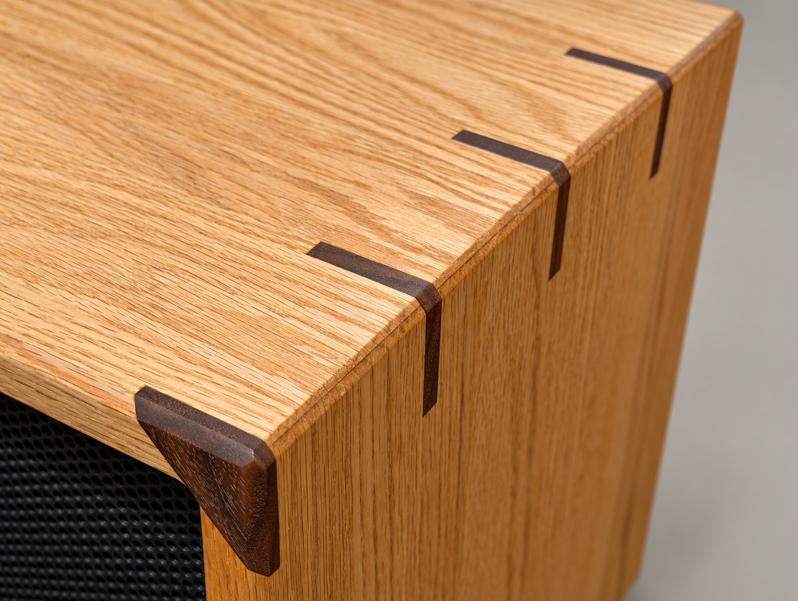
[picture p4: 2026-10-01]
photos/Ambersong - Corner Closeup.png

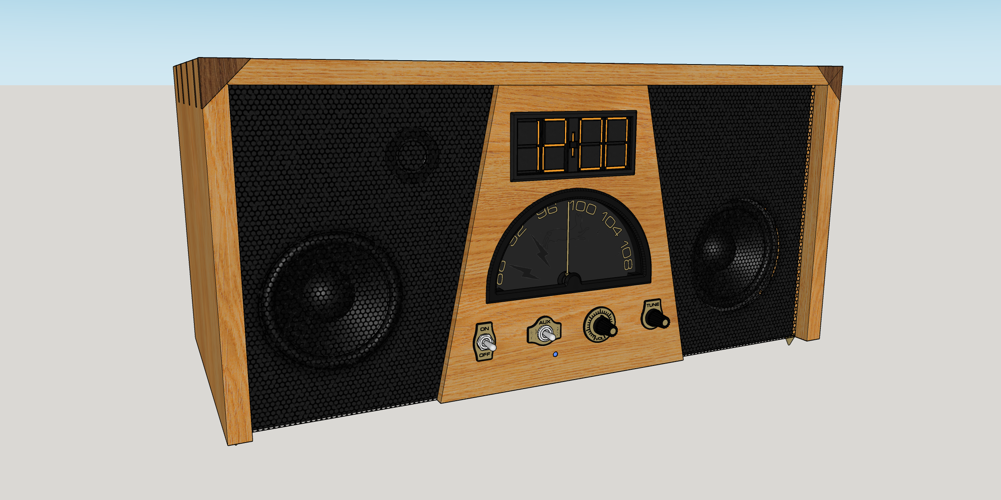
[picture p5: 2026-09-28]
photos/Ambersong - Render - Isometric Front.png

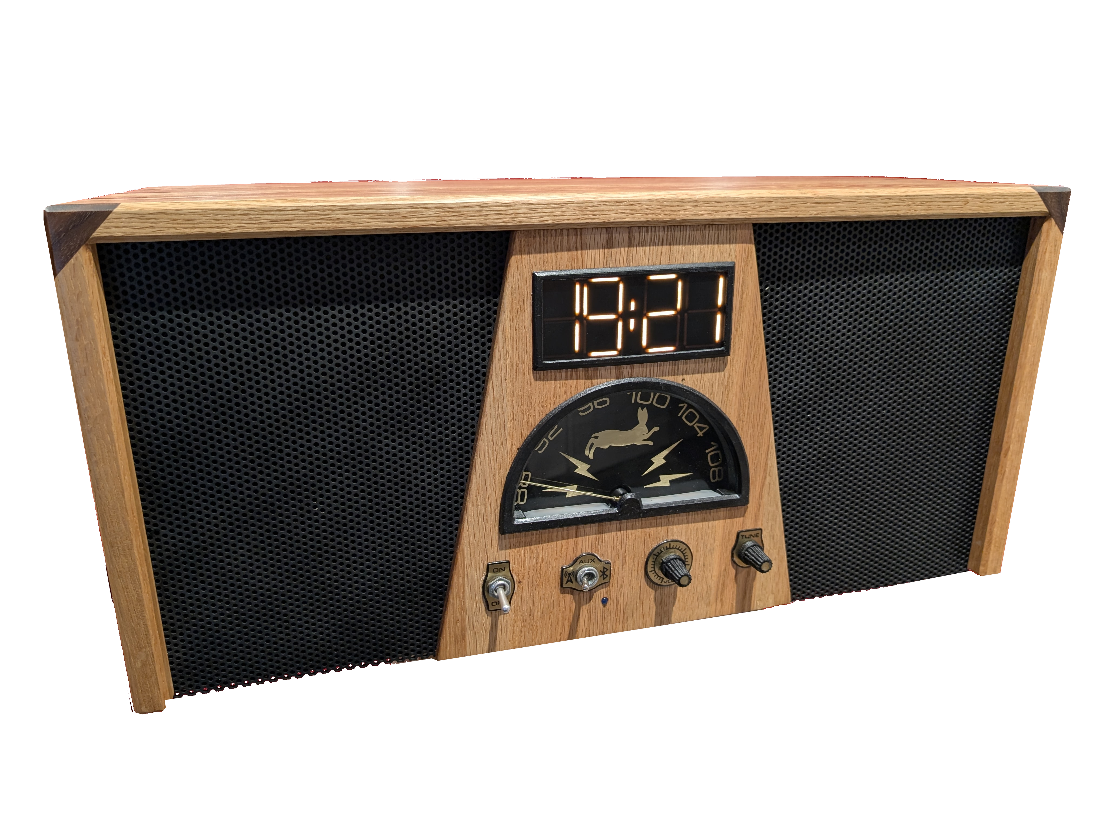
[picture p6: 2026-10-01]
photos/Ambersong - Isometric Front.png

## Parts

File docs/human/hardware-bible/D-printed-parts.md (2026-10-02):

# Appendix D. Printed parts

This appendix lists every printed part of the build. You need it when you reprint a broken or lost
part, or when you build a cabinet of your own.

Every printed part is an STL file (the file a 3D printer works from) in the `hardware/STLs/` folder of
the published Ambersong project files, named as in the tables below: 76 files. **All are PLA, except the passive radiator's membrane,
which is TPU** (a flexible filament). They are the author's parts for this cabinet and these boards;
adapt them to yours. In the file names, MCU means a microcontroller board, PSU a power supply, and
LEDITRON the clock display.

Not printed: the source switch and the power switch (fixed in the wooden front panel), the mains inlet
(on the amplifier's aluminium back plate), and the standoffs of the amplifier's ±20 V supply, which are
plastic screws and standoffs.

## D.1 Speakers

These are the passive radiators that replace the speakers' original ports, and the speaker holder
(chapter 12, section 12.1).

| File | What it is |
|---|---|
| `AUDIO - Passive Radiator - Holder.stl` | passive radiator: holder |
| `AUDIO - Passive Radiator - Inside Protector.stl` | passive radiator: inside protector |
| `AUDIO - Passive Radiator - Membrane Weight.stl` | passive radiator: membrane weight |
| `AUDIO - Passive Radiator - Outside Protector.stl` | passive radiator: outside protector |
| `AUDIO - Passive Radiator - TPU Membrane.stl` | passive radiator: membrane, **printed in TPU** |
| `AUDIO - Speakers Holder and Seal.stl` | speaker holder and seal |

## D.2 Back

The files whose names begin with BACK are the back panel's anchors and vents, and the parts for the
USB-C ports and the antenna connector (chapter 3, sections 3.1 and 3.4).

| File | What it is |
|---|---|
| `BACK - Dual USB-C Ports.stl` | the two back-panel USB-C ports (chapter 4, section 4.6) |
| `BACK - Electronics - BNC Antenna Interface.stl` | the antenna connector's interface: the connector (J10) is a BNC on the back panel (chapter 11) |
| `BACK - Fan Exhaust.stl` | the box fan's exhaust |
| `BACK - Fan Intake.stl` | the louvred air intakes |
| `BACK - Panel Anchors Bottom.stl` | back panel anchors, bottom |
| `BACK - Panel Anchors Inner Corners.stl` | back panel anchors, inner corners |
| `BACK - Panel Anchors Outer Corners.stl` | back panel anchors, outer corners |
| `BACK - Panel Anchors.stl` | back panel anchors |

## D.3 Front panel

These are the parts of the front panel, the FM dial and the tuning knob (chapter 3, section 3.2;
chapter 8, section 8.1).

| File | What it is |
|---|---|
| `FRONT - FM Dial - Back.stl` | FM dial back; it is also the stepper motor's mount |
| `FRONT - FM Dial - Cover.stl` | FM dial cover |
| `FRONT - FM Dial - Spacer.stl` | FM dial spacer |
| `FRONT - FM Dial - Stepper Needle and Magnet Holder.stl` | the mount on the stepper motor's shaft that carries the needle and the index magnet |
| `FRONT - Panel Anchors - Insidemost.stl` | front panel anchors, insidemost |
| `FRONT - Panel Anchors - Outsidemost.stl` | front panel anchors, outsidemost |
| `FRONT - Tuner Pot Knob.stl` | the printed front tuning knob. On the printed shaft extension, it turns the radio's original tuning knob, which drives the dial cord and the tuning capacitor (chapter 3, section 3.2). "Pot" is the file's word: tuning is by the tuning capacitor. |
| `FRONT - Tuning Pot Extender PLA Shaft.stl` | the tuning shaft extension |
| `FRONT - Tuning Shaft Bearing Seat.stl` | the tuning shaft's bearing seat |
| `FRONT - Volume Pot Knob.stl` | the front volume knob (chapter 9, section 9.4) |

## D.4 Board cases and holders, inside the cabinet

Each board or module sits in its own printed case, or on a printed carrying plate, screwed to the
cabinet (chapter 3, section 3.1).

| File | What it is |
|---|---|
| `IN - Electronics - 5V BUS case Bottom.stl` | 5 V bus case, bottom (chapter 5, section 5.5) |
| `IN - Electronics - 5V BUS case Top.stl` | 5 V bus case, top |
| `IN - Electronics - 5V PSU Case Bottom.stl` | 5 V power supply case, bottom |
| `IN - Electronics - 5V PSU Case Top.stl` | 5 V power supply case, top |
| `IN - Electronics - 5V+3V3 BUS case Bottom.stl` | 5 V and 3.3 V bus case, bottom |
| `IN - Electronics - 5V+3V3 BUS case Top.stl` | 5 V and 3.3 V bus case, top |
| `IN - Electronics - AC Line Filter Case.stl` | mains line filter case (chapter 5, section 5.4) |
| `IN - Electronics - AS5600 Case - Bottom.stl` | the angle sensor's cage, bottom (chapter 5, section 5.4) |
| `IN - Electronics - AS5600 Case - Connecting Rod.stl` | the printed shaft that carries the angle sensor's magnet (chapter 8, section 8.1) |
| `IN - Electronics - AS5600 Case - Top.stl` | the angle sensor's cage, top |
| `IN - Electronics - Audio Listener Case BOTTOM.stl` | the source-switch board's case, bottom (chapter 9, section 9.3) |
| `IN - Electronics - Audio Listener Case TOP.stl` | the source-switch board's case, top |
| `IN - Electronics - Audio MCU Case BOTTOM.stl` | audio board case, bottom |
| `IN - Electronics - Audio MCU Case TOP.stl` | audio board case, top |
| `IN - Electronics - Backing Panel 1.stl` | a panel that holds several of the cases |
| `IN - Electronics - Bluetooth LED Holder.stl` | Bluetooth LED holder |
| `IN - Electronics - Bluetooth LED Pusher.stl` | Bluetooth LED pusher (the LED is also the button) |
| `IN - Electronics - Box Fan LM7812 Case Bottom.stl` | the box fan's regulator case, bottom (chapter 5, section 5.6) |
| `IN - Electronics - Box Fan LM7812 Case Top.stl` | the box fan's regulator case, top |
| `IN - Electronics - DS3231 RTC Case BOTTOM.stl` | real-time clock module case, bottom |
| `IN - Electronics - DS3231 RTC Case TOP.stl` | real-time clock module case, top |
| `IN - Electronics - Digit Drivers Case BOTTOM.stl` | digit driver case, bottom (chapter 7) |
| `IN - Electronics - Digit Drivers Case TOP.stl` | digit driver case, top |
| `IN - Electronics - Front Panel FM LEDs Case BOTTOM.stl` | FM panel lamp board case, bottom (chapter 9, section 9.1) |
| `IN - Electronics - Front Panel FM LEDs Case TOP.stl` | FM panel lamp board case, top |
| `IN - Electronics - Hall Sensor Stepper Limit Case.stl` | the needle index sensor's case (chapter 8, section 8.3) |
| `IN - Electronics - LEDITRON Back.stl` | clock display back |
| `IN - Electronics - LEDITRON Bus Case Bottom.stl` | clock display bus case, bottom |
| `IN - Electronics - LEDITRON Bus Case TOP.stl` | clock display bus case, top |
| `IN - Electronics - PCM1802 ADC Case BOTTOM.stl` | ADC case, bottom |
| `IN - Electronics - PCM1802 ADC Case TOP.stl` | ADC case, top |
| `IN - Electronics - PCM5102A DAC Case Bottom.stl` | DAC case, bottom |
| `IN - Electronics - PCM5102A DAC Case TOP.stl` | DAC case, top |
| `IN - Electronics - Power Detect Case BOTTOM.stl` | amplifier power sensor case, bottom (chapter 9, section 9.5) |
| `IN - Electronics - Power Detect Case TOP.stl` | amplifier power sensor case, top |
| `IN - Electronics - RDA5807M - Bottom.stl` | FM calibration receiver case, bottom (chapter 8, section 8.5) |
| `IN - Electronics - RDA5807M - Cage Holder.stl` | FM calibration receiver cage holder |
| `IN - Electronics - RDA5807M - Middle Bottom.stl` | FM calibration receiver case, middle bottom |
| `IN - Electronics - RDA5807M - Middle TOP.stl` | FM calibration receiver case, middle top |
| `IN - Electronics - RDA5807M - TOP.stl` | FM calibration receiver case, top |
| `IN - Electronics - S3 Main MCU Backing.stl` | main board backing |
| `IN - Electronics - S3 Main MCU Case BOTTOM.stl` | main board case, bottom |
| `IN - Electronics - S3 Main MCU Case TOP.stl` | main board case, top |
| `IN - Electronics - Stepper Driver ULN2003A Case - Bottom.stl` | needle motor driver case, bottom (chapter 8, section 8.2) |
| `IN - Electronics - Stepper Driver ULN2003A Case - Top.stl` | needle motor driver case, top |

## D.5 The tube radio's Faraday cage

These two parts make the cage over the tube radio (chapter 3, section 3.5; chapter 5, section 5.4).

| File | What it is |
|---|---|
| `IN - Tube Radio - Faraday Cage 1.stl` | the tube radio's Faraday cage, part 1; the cage fan's mount is part of it |
| `IN - Tube Radio - Faraday Cage 2.stl` | the tube radio's Faraday cage, part 2 |

## D.6 Clock display

These are the clock display's housing and digits (chapter 7).

| File | What it is |
|---|---|
| `LEDITRON - Colon - Blanket.stl` | colon blanket |
| `LEDITRON - Colon.stl` | colon |
| `LEDITRON - Digit.stl` | digit |
| `LEDITRON - Front Case.stl` | front case |
| `LEDITRON - Glass Spacer.stl` | glass spacer |

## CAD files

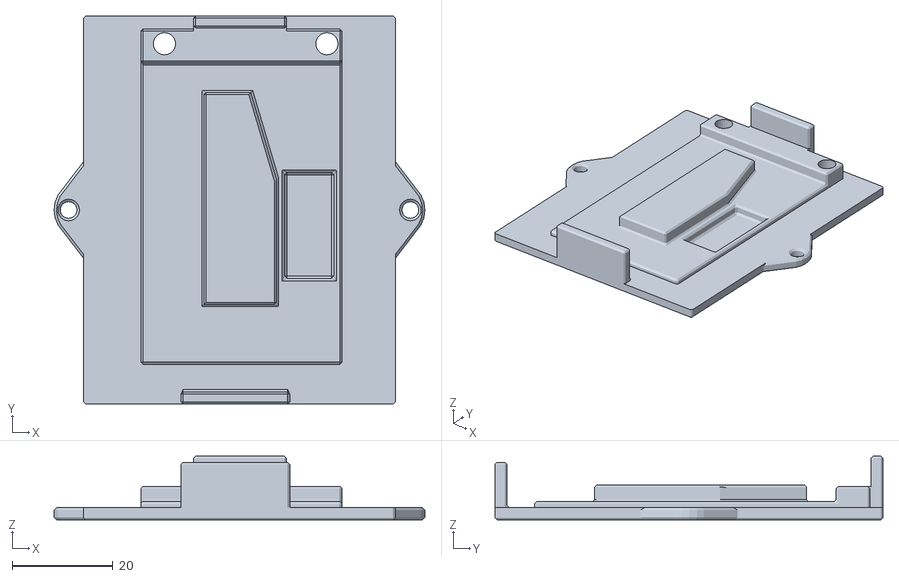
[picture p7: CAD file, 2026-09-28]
hardware/STLs/IN - Electronics - S3 Main MCU Case BOTTOM.stl
73.5 x 76.9 x 12.6

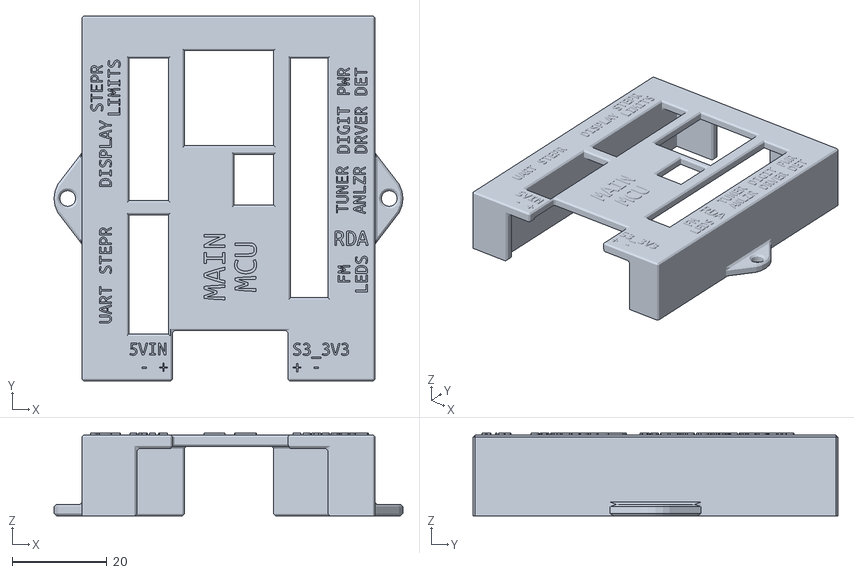
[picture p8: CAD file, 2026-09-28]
hardware/STLs/IN - Electronics - S3 Main MCU Case TOP.stl
73.5 x 76.9 x 17.4

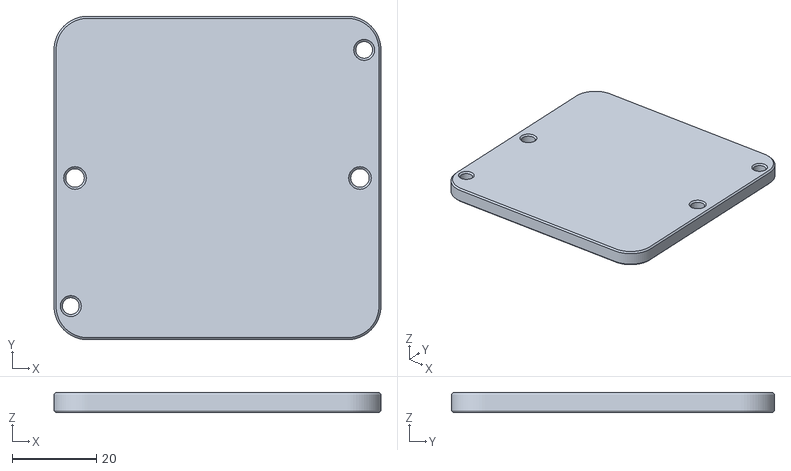
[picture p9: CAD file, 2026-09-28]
hardware/STLs/IN - Electronics - S3 Main MCU Backing.stl
77.7 x 76.9 x 4.80

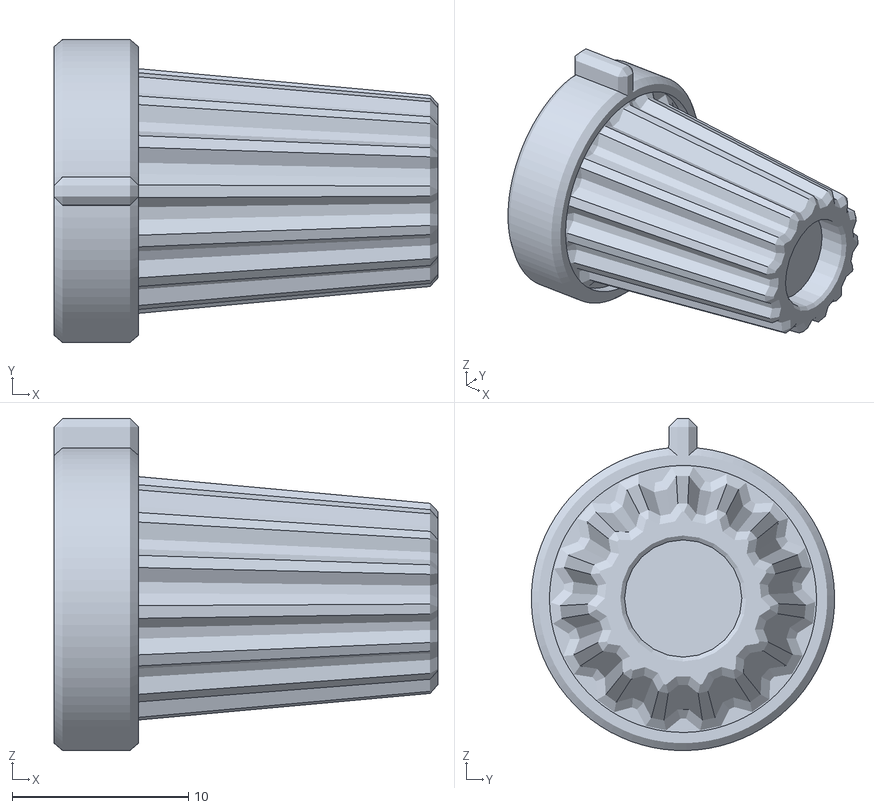
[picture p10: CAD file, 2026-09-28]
hardware/STLs/FRONT - Volume Pot Knob.stl
21.8 x 17.2 x 18.8

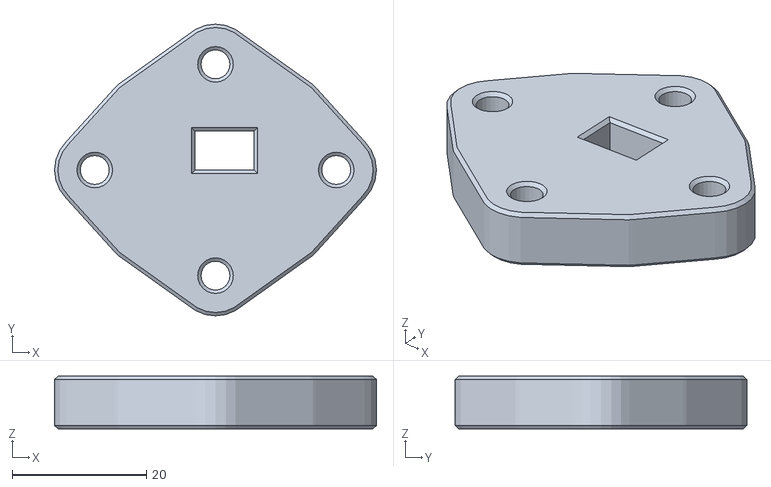
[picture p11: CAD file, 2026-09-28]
hardware/STLs/IN - Electronics - RDA5807M - Middle TOP.stl
48.0 x 43.5 x 7.86

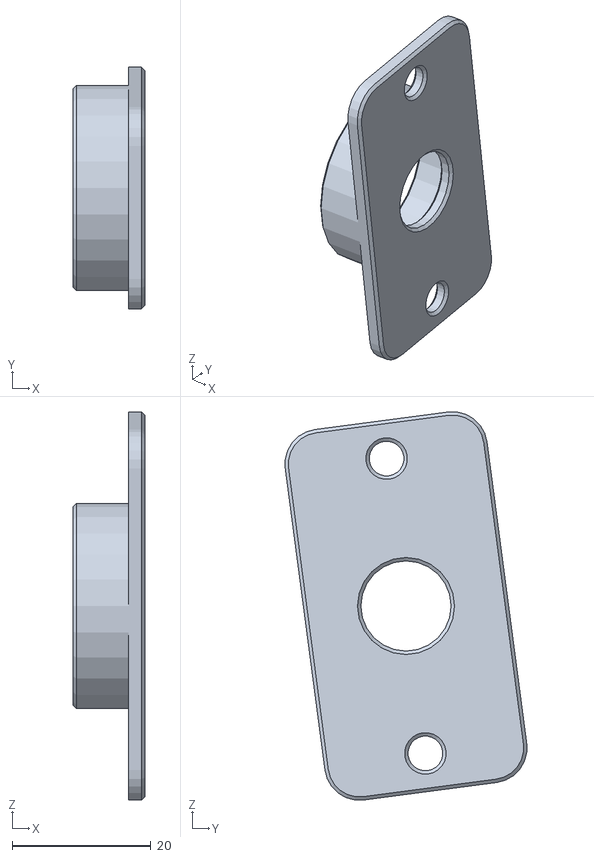
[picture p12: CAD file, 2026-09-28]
hardware/STLs/FRONT - Tuning Shaft Bearing Seat.stl
10.4 x 34.8 x 55.9

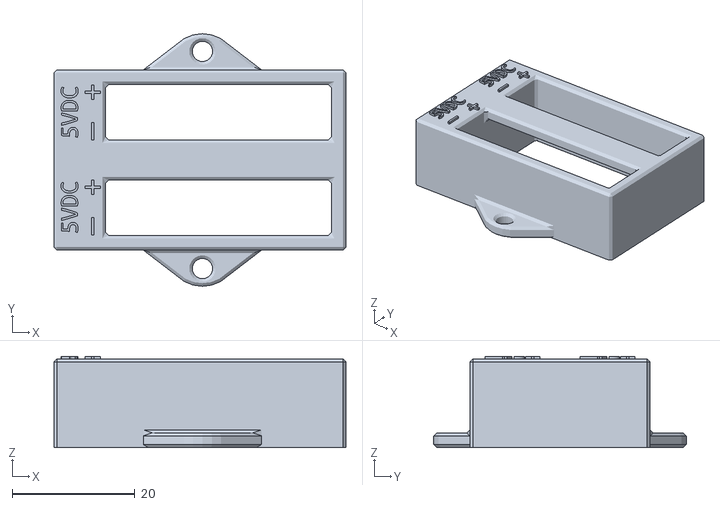
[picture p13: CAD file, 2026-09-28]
hardware/STLs/IN - Electronics - 5V BUS case Top.stl
47.6 x 41.2 x 14.9

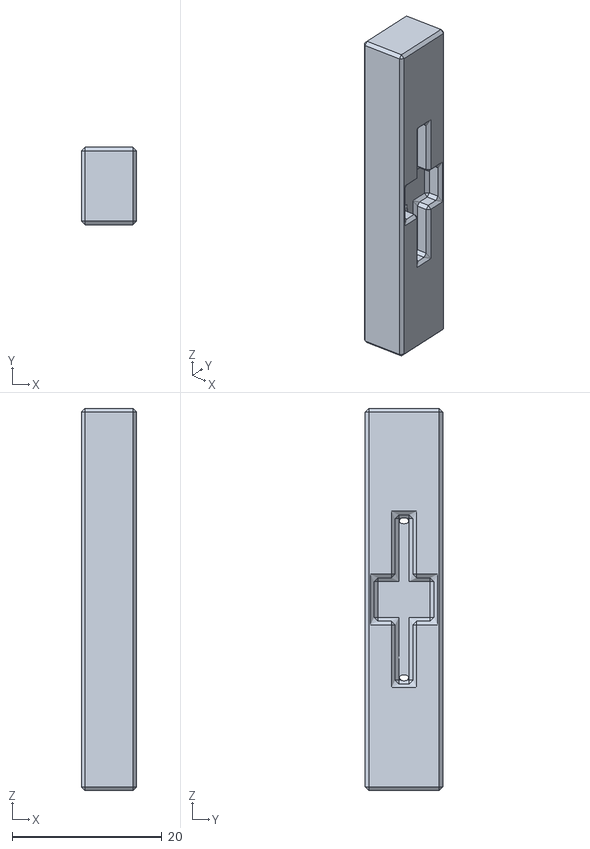
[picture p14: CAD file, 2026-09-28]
hardware/STLs/LEDITRON - Colon.stl
7.40 x 10.4 x 51.1

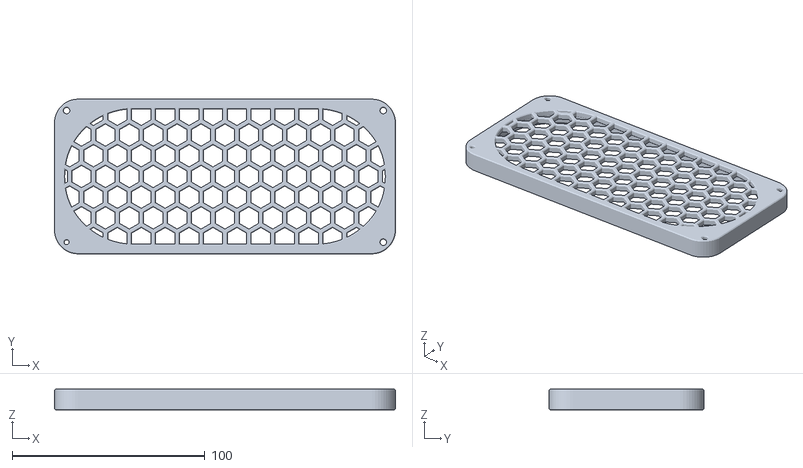
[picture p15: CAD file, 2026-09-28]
hardware/STLs/AUDIO - Passive Radiator - Inside Protector.stl
176.8 x 80.2 x 10.8

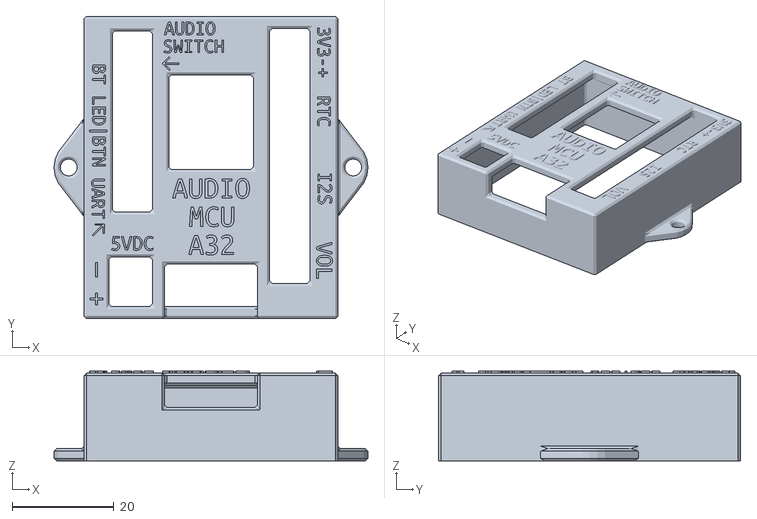
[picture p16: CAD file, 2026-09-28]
hardware/STLs/IN - Electronics - Audio MCU Case TOP.stl
61.7 x 59.4 x 17.6

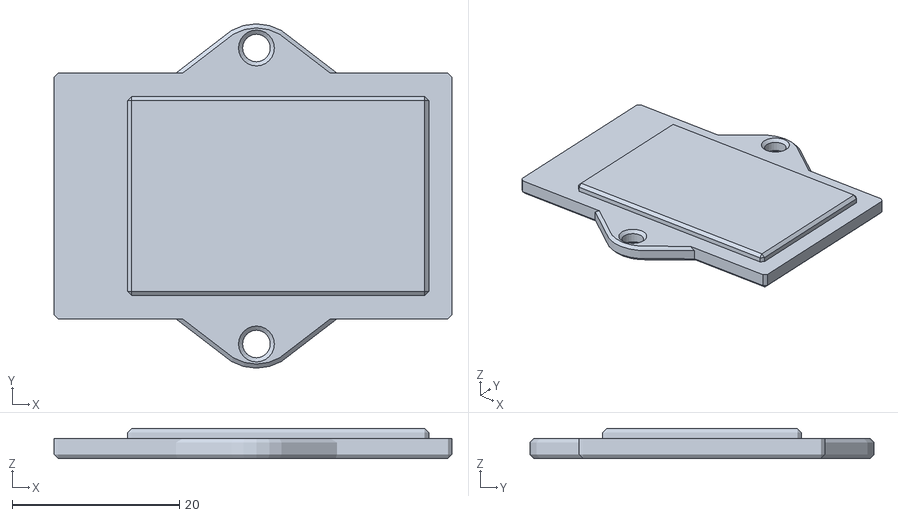
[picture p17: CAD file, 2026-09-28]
hardware/STLs/IN - Electronics - 5V+3V3 BUS case Bottom.stl
47.6 x 41.2 x 3.60

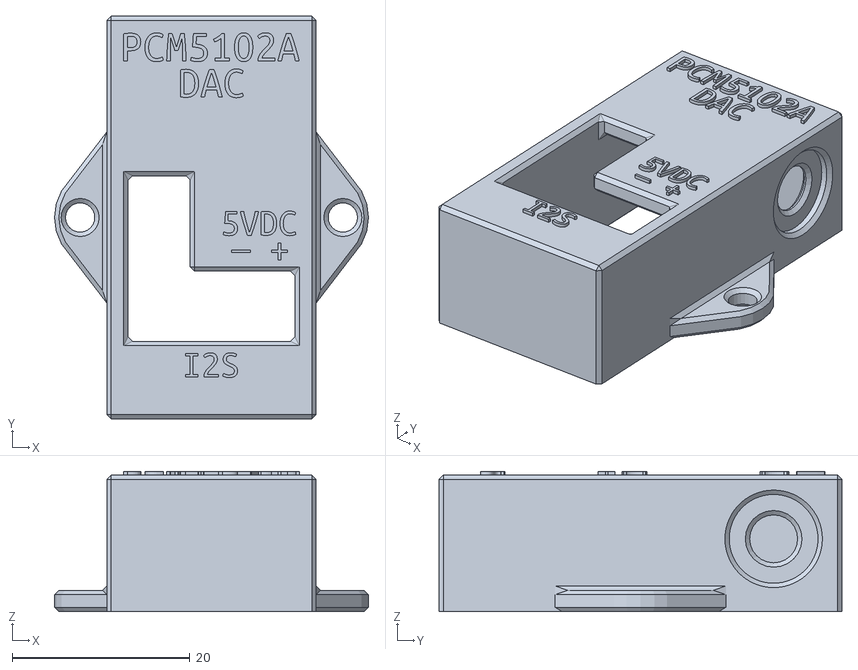
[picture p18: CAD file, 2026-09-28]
hardware/STLs/IN - Electronics - PCM5102A DAC Case TOP.stl
35.4 x 45.4 x 15.8

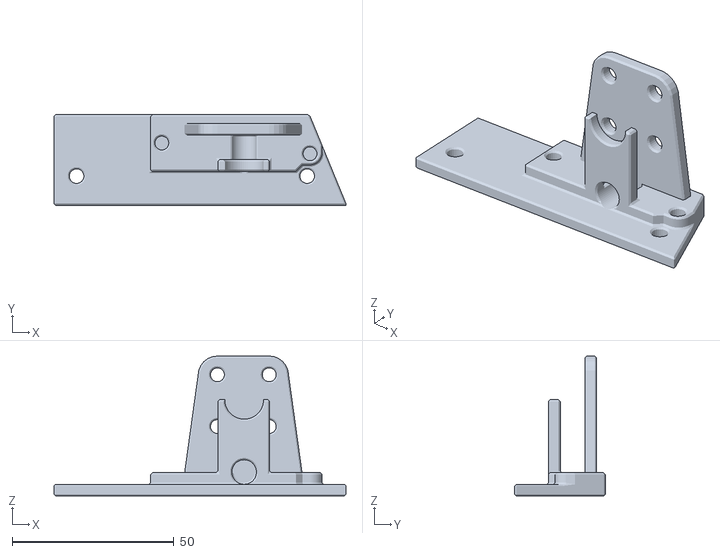
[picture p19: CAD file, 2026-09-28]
hardware/STLs/IN - Electronics - AS5600 Case - Bottom.stl
90.3 x 28.0 x 43.3

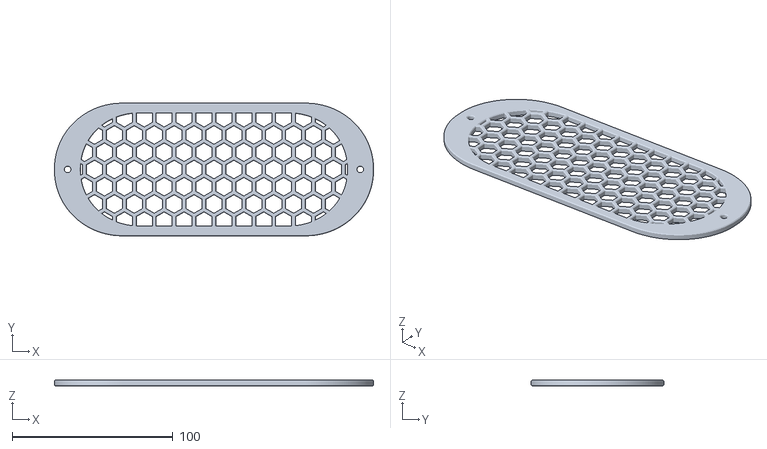
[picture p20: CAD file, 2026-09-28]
hardware/STLs/AUDIO - Passive Radiator - Outside Protector.stl
198.5 x 82.6 x 3.60

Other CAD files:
hardware/STLs/AUDIO - Passive Radiator - Holder.stl
hardware/STLs/IN - Electronics - LEDITRON Bus Case Bottom.stl
hardware/STLs/IN - Electronics - Power Detect Case BOTTOM.stl
hardware/STLs/FRONT - Panel Anchors - Outsidemost.stl
hardware/STLs/AUDIO - Passive Radiator - Membrane Weight.stl
hardware/STLs/AUDIO - Passive Radiator - TPU Membrane.stl
hardware/STLs/AUDIO - Speakers Holder and Seal.stl
hardware/STLs/BACK - Dual USB-C Ports.stl
hardware/STLs/BACK - Electronics - BNC Antenna Interface.stl
hardware/STLs/BACK - Fan Exhaust.stl
hardware/STLs/BACK - Fan Intake.stl
hardware/STLs/BACK - Panel Anchors Bottom.stl
hardware/STLs/BACK - Panel Anchors Inner Corners.stl
hardware/STLs/BACK - Panel Anchors Outer Corners.stl
hardware/STLs/BACK - Panel Anchors.stl
hardware/STLs/FRONT - FM Dial - Back.stl
hardware/STLs/FRONT - FM Dial - Cover.stl
hardware/STLs/FRONT - FM Dial - Spacer.stl
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

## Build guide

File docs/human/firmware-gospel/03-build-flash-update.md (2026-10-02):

# 3. Building, flashing and updating

The firmware is one PlatformIO project that builds two programs: one for the S3, the main board, and
one for the A32, the audio board. This chapter tells you how to build both on a clean PC. It shows how
to put them on the boards the first time over a USB cable, and how to update them afterwards without a
cable, through the portal. It explains the version numbers each program carries, so that you can always tell
which program runs on which board and which source it was built from. And it is the one place in this
book that explains how a freshly updated program is put **on trial**, then **confirmed** or **rolled
back**; every other chapter points here.

## 3.1 Five things to remember

1. **The toolchain is pinned, and stays pinned.** The PlatformIO platform is `espressif32@7.0.1`.
2. **The only library, the Bluetooth library, is pinned to one exact commit** (section 3.3).
3. **Identify a board by its MAC address before you write anything to it.**
4. **Judge a build or an update by what the machine reports afterwards**, never by what a tool printed
   on the way.
5. **A program sent over the air runs on trial for its first minute or so.** If it hangs or resets
   before it has proved itself, the board goes back by itself to the program it had before. Neither
   board saves its settings during the trial; they are written once the new program is confirmed. A
   reboot from the portal during the trial is the way to take the new program back out.

## 3.2 The project and its two environments

The firmware lives in the folder `firmware/` (chapter 2, section 2.6 lists its files). Its
`platformio.ini` defines two build **environments**. An environment is PlatformIO's name for one
complete build recipe: target board, compiler flags, libraries and sources.

> **For firmware changes**
>
>
> The two environments differ as follows:
>
> | | `s3` | `a32` |
> |---|---|---|
> | Board definition | `esp32-s3-devkitc-1` | `esp32dev` |
> | Sources compiled | `src/s3/` | `src/a32/` |
> | Shared headers | `include/pins.h`, `include/proto.h`, `include/link.h` | the same three files |
> | Identity define | `-DAMB_S3=1` | `-DAMB_A32=1` |
> | Other defines | `-DBOARD_HAS_PSRAM`, `-DARDUINO_USB_CDC_ON_BOOT=1` | none |
> | Partition table | `default_16MB.csv` | `min_spiffs.csv` |
> | Libraries | none beyond the Arduino core | ESP32-A2DP, pinned to one commit |
> | Pre-build scripts | `scripts/version.py`, `scripts/page.py` | `scripts/version.py` |
>
> Both environments also get `-DCORE_DEBUG_LEVEL=3` (the Arduino core's warning-level logging), a serial
> monitor at 115 200 baud, and two monitor filters: `esp32_exception_decoder`, which turns a crash
> address into a function name, and `time`, which timestamps each line. No source file tests the two
> identity defines; each program is selected by its own source folder.
>
> The `build_src_filter` line decides which folder of sources goes into which program. The `include/`
> folder goes into both. That is the point of the single project. The pin map and the protocol between
> the boards are one set of files compiled into both programs, so the two boards cannot disagree about
> them by accident.
>
> **The S3's memory settings.** Four lines tell the Arduino core how the S3 module's flash and its
> external RAM (**PSRAM**) are connected: `board_build.arduino.memory_type = qio_opi`, `flash_mode = qio`,
> `psram_type = opi` and `flash_size = 16MB`. The module has 16 MB of quad-SPI flash and 8 MB of octal
> PSRAM (Hardware Bible, chapter 4). **Getting `memory_type` wrong fails silently:** the board boots normally and reports 0 MB
> of PSRAM. `ARDUINO_USB_CDC_ON_BOOT=1` sends the S3's console to the chip's own USB port, which is
> where the S3's back-panel USB-C socket leads (Hardware Bible, chapter 4). If that ever changes, the
> define must become 0, or the console goes nowhere visible.
>

The `s3` environment builds for Espressif's ESP32-S3-DevKitC-1 with those memory overrides. The board
fitted here runs it: it is compatible with the DevKitC-1 in firmware, and pin-compatible for every pin
the machine uses (Hardware Bible, chapter 4). The firmware relies only on the pins in `include/pins.h`
and on the memory type above. The A32 build is laid out for a 4 MB flash chip, because
`min_spiffs.csv` lays out 4 MB.

## 3.3 The two pins: the platform and the library

**The platform.** `platform = espressif32@7.0.1`. This PlatformIO platform release brings Arduino core
2.0.17, built on ESP-IDF 4.4.7, Espressif's own framework underneath Arduino. The next major Arduino
core, 3.x on ESP-IDF 5, retires the "legacy" I2S driver; I2S is the serial audio bus between the A32
and its converters. Without that driver, the Bluetooth library routes its audio through a second
library, AudioTools, instead of driving I2S directly.

The A32 runs three things at once on one chip: a Bluetooth audio receiver, audio capture from the
radio, and audio output. Its whole audio design rests on the legacy driver. One full-duplex I2S driver
is installed once and never reconfigured. The Bluetooth library is given an output that has no route
to I2S at all (chapter 10 explains why). Core 2.0.17 is the most-travelled road for that combination.
Official PlatformIO support for Espressif stopped at 7.0.1 (May 2024), so the pin costs nothing in
practice.

> **For firmware changes**
>
>
> If core 3.x is ever truly needed, the escape hatch is one line: point `platform` at the community fork
> `https://github.com/pioarduino/platform-espressif32`, and then expect to redo the A32's audio engine.
>

**The library.** The A32 depends on exactly one library, ESP32-A2DP by Phil Schatzmann, which turns the
classic ESP32 into a Bluetooth A2DP audio receiver (a "sink"). It is not in the PlatformIO registry
under a short name, so it is fetched from source with git, pinned to one commit (library version
1.8.11):

```
lib_deps = https://github.com/pschatzmann/ESP32-A2DP.git#3245602afc494f9e62160a0cfb2af864af45a37f
```

The pin matters because the A32 overrides one of the library's internal hooks. With it, only the A32's
own code decides whether the radio is visible to Bluetooth scans (chapter 10). An override of
internals is exactly what a silent library update breaks. Unpinned, a fresh clone or a deleted `.pio`
folder fetches whatever the library's main branch holds that day.

## 3.4 Version stamps and the build scripts

Two scripts run before every build. `scripts/version.py` stamps the version on both boards;
`scripts/page.py`, on the S3 only, packs the portal's web page into the program.

> **For firmware changes**
>
>
> Both scripts run before compilation (`pre:` in `extra_scripts`). The `s3` environment lists
> `version.py` a second time, because an environment's own `extra_scripts` replaces the common list
> instead of adding to it.
>

**`scripts/version.py` (both boards)** gives the compiler two strings:

- **`FW_VERSION`, the version stamp:** `v.<MAJOR>.<YYYYMMDDTHHMMSS>`, taken from the build PC's clock
  (local time, with no time zone in the string). Example: `v.1.20260926T101500`. MAJOR is a number
  typed into the script by hand (`MAJOR = 1`); it is `1` from the v.1.0 release on.
- **`FW_COMMIT`, the source stamp:** the 7-character short git hash of the commit checked out,
  followed by `-dirty` if any file that git tracks had uncommitted changes at build time. Files git does
  not track do not count. If git is not available, or the folder is not a repository, the value is
  `nogit`.

The script prints both at build time: `Ambersong firmware version: v.1.<stamp> (<hash>)`.

**Why two stamps.** The stamp is taken at build time, not from a file, because the question that
matters in the field is "which binary is this?". Two builds of the same source get different stamps
on purpose. The S3 updates the A32, so the two boards *will* run builds from different moments, and
the start-up handshake between them must be able to tell them apart. The commit hash answers the second
question, "which source?", and `-dirty` warns you when the hash alone would name code that is not what
was built.

**Why they are kept apart.** The version string travels between the boards inside the link's
handshake message, in a fixed 24-byte field. `v.1.` plus a 15-character timestamp is 19 characters and
fits. The version and the hash together would not fit, and widening the field would be a protocol
change. So `FW_COMMIT` is shown next to the version wherever a person reads it, and never travels on
the link as part of the version. The A32's commit reaches the S3 only inside the text of its boot
report (section 3.11.7).

If `version.py` did not run at all, both programs fall back to `FW_VERSION "v.0.unstamped"` and
`FW_COMMIT "nogit"`. Seeing `unstamped` on a running board means it was built outside PlatformIO's
normal flow.

> **For firmware changes**
>
>
> **`scripts/page.py` (S3 only)** turns the portal's single web page into C data:
>
> 1. It reads `data/portal.html`.
> 2. It checks that the page's one `<script>` block parses as JavaScript, with the Python package
>    `esprima`. If the script does not parse, **the build fails**. If `esprima` is not installed, it
>    prints `[WARN] esprima not installed - the portal's script was NOT checked.` and the build carries
>    on.
> 3. It compresses the page with gzip at level 9, with the gzip timestamp forced to zero (`mtime=0`).
> 4. It computes an **ETag**, a cache identifier that browsers send back to ask "has this changed?": the
>    first 16 hexadecimal digits of the SHA-256 of the compressed bytes.
> 5. It writes `src/s3/page_gz.h`, holding `PAGE_GZ[]` (the compressed page, in program memory),
>    `PAGE_GZ_LEN` and `PAGE_ETAG`. It rewrites the file only when its text changed, so an untouched page
>    does not force a rebuild.
>
> `src/s3/page_gz.h` is generated, but it is kept in git so that the source tree is always complete.
> **Never edit it by hand:** edit `data/portal.html` and rebuild. At v.1.0.3 the page was 35 886 bytes of
> HTML and 13 322 bytes compressed (37 %). The portal never reads a filesystem: the page lives inside the
> program. So there is nothing to upload separately, and nothing that can fall out of step with the
> firmware serving it. Section 3.16 gives the reason for each step; chapter 8 explains how the page is
> served.
>

## 3.5 Flash layout, and what survives a reflash

A **partition table** divides the flash chip into named regions. Both tables are stock files from the
Arduino core; the firmware does not ship its own.

> **For firmware changes**
>
>
> **S3, `default_16MB.csv` (16 MB flash)**
>
> | Name | Type / subtype | Offset | Size | Used for |
> |---|---|---|---|---|
> | nvs | data / nvs | 0x9000 | 0x5000 (20 KB) | settings, calibrations, network, accounts |
> | otadata | data / ota | 0xE000 | 0x2000 | which program slot boots |
> | app0 | app / ota_0 | 0x10000 | 0x640000 (6.25 MiB) | program slot 0 |
> | app1 | app / ota_1 | 0x650000 | 0x640000 (6.25 MiB) | program slot 1 |
> | spiffs | data / spiffs | 0xC90000 | 0x360000 | unused |
> | coredump | data / coredump | 0xFF0000 | 0x10000 | crash dump area |
>
> **A32, `min_spiffs.csv` (4 MB flash)**
>
> | Name | Type / subtype | Offset | Size | Used for |
> |---|---|---|---|---|
> | nvs | data / nvs | 0x9000 | 0x5000 | audio and Bluetooth settings |
> | otadata | data / ota | 0xE000 | 0x2000 | which program slot boots |
> | app0 | app / ota_0 | 0x10000 | 0x1E0000 (1.875 MiB) | program slot 0 |
> | app1 | app / ota_1 | 0x1F0000 | 0x1E0000 (1.875 MiB) | program slot 1 |
> | spiffs | data / spiffs | 0x3D0000 | 0x20000 | unused |
> | coredump | data / coredump | 0x3F0000 | 0x10000 | crash dump area |
>
> The `spiffs` partitions exist only because the stock tables contain them; this firmware never mounts
> them.
>

**Two program slots make an update over the air possible.** The running program writes the new
program into the slot it is not running from. It then tells the bootloader to start the other slot
next time. At v.1.0.5 the S3's program is 999 568 bytes, about 15 % of its slot; at v.1.0.4 the A32's is
1 218 608 bytes, about 62 % of its slot.

**NVS** ("non-volatile storage") is the ESP-IDF key-value store in flash.

> **For firmware changes**
>
>
> The firmware uses these NVS namespaces:
>
> | Board | Namespace | Holds |
> |---|---|---|
> | S3 | `amb3` | The settings: one versioned, append-only structure (magic `0xA838`, settings version 7; chapter 7). Also the learned WiFi transmit power (`wifiTxQ`), which is not in the settings file. |
> | S3 | `net` | WiFi network name and password, network time server, time zone. |
> | S3 | `auth` | Portal accounts, stored as salted SHA-256 hashes. |
> | A32 | `amb` | Audio and Bluetooth settings. |
>

The needle's remembered position is not in NVS. It lives in RAM that a software restart does not
clear, and a power cycle does (chapter 5).

**What survives what.** This table shows which ways of writing a board keep your settings.

| What you do | What it writes | Settings, calibrations, accounts, WiFi network |
|---|---|---|
| A normal PlatformIO upload over USB | The bootloader, the partition table, a fresh `otadata` (so the board starts slot 0), and the program into slot 0. | **Kept**: NVS is not touched. |
| A full chip erase (`pio run -t erase`, or `esptool.py erase_flash`) | Everything. | **Wiped.** |
| An update over the air | The new program into the idle slot; then the bootloader is told to start that slot next time. | **Kept**, and not written during the trial (section 3.11). |
| A change of partition table | Possible only over USB: the running program cannot rewrite the table it runs under. | Kept as long as NVS stays at 0x9000. |

## 3.6 Building from a clean PC

These steps were written on Windows. They work the same on Linux or macOS, with the obvious path
changes.

1. **Install git.** PlatformIO uses it to fetch the pinned library, and `version.py` uses it to read
   the commit hash.
2. **Install PlatformIO:** either VS Code with the PlatformIO IDE extension, or PlatformIO Core on its
   own. The `pio` command may not be on your `PATH`; on Windows it lives at
   `%USERPROFILE%\.platformio\penv\Scripts\pio.exe`.
3. **Install `esprima` into PlatformIO's own Python** (recommended). PlatformIO runs its own Python, so
   install the package there: `%USERPROFILE%\.platformio\penv\Scripts\pip install esprima`. Without it
   the portal's JavaScript is not checked (section 3.4).
4. **Get the `firmware/` folder**, ideally as a git clone, so that the commit stamp works. Nothing
   outside `firmware/` is needed to build.
5. **Build both programs**, from inside `firmware/`:

   ```
   pio run -e s3        # the main board
   pio run -e a32       # the audio board
   ```

   The first build downloads the pinned platform, Arduino core 2.0.17, the Xtensa compilers and the
   pinned library commit. That takes a while and needs internet access. Later builds work offline.
6. **Check the exit code, not the output.** `0` means built; anything else means not built, whatever
   the last lines on the screen say. In PowerShell read `$LASTEXITCODE`; in a POSIX shell, `$?`. A
   filter that searched the output for `SUCCESS` once hid a linker failure, and a pre-build script can
   fail before printing anything at all.
7. **Never let two builds use the same `.pio` folder at once.** Two builds compiling into one `.pio`
   produced that linker failure.
8. **Find the outputs** in `.pio/build/s3/` and `.pio/build/a32/`. `firmware.bin` is the program, the
   file you upload through the portal. `bootloader.bin` and `partitions.bin` go onto a board only in a
   USB upload.

## 3.7 Identify the board first

> **Warning — never write to a board you have not identified by its MAC address.** Every ESP32 has a
> factory-burned MAC address, unique to the chip. Keep a written list of your own boards' MAC
> addresses, and compare the target against that list before every write.

**Why.** A workbench often has several ESP32 boards plugged in, and boards of the same kind share the
same USB vendor and product numbers. PlatformIO's automatic port detection will happily pick the wrong
one. So never let PlatformIO choose the port: pass `--upload-port` every time.

**How to read a board's MAC address:**

- **A board on the chip's own USB port** (the S3 here). `pio device list` shows the MAC address directly
  as the serial number, `SER=xx:xx:xx:xx:xx:xx`.
- **A board behind a USB-to-serial bridge chip** (the A32 here, behind a CP210x bridge). The serial
  number that `pio device list` shows belongs to the bridge, not to the ESP32. Ask the chip itself:

  ```
  esptool.py --port COMx read_mac
  ```

  (`flash_id` also prints the MAC address, together with the flash size.) `esptool.py` ships with
  PlatformIO as the package `tool-esptoolpy`. Reading the MAC address resets the board into its ROM
  bootloader and back; it writes nothing.

**The same rule applies to updates over the air.** The portal is reached by a network address, and an
address is not an identity. Before an update, find the board's MAC address in the PC's ARP table
(`arp -a`), against the address the browser is about to use.

**A second rule travels with the first: never flash a machine while someone is listening to it or
looking at it.** A new program pushed into a machine under observation spoils the observation. The
person may not know why the behaviour changed.

## 3.8 The first flash, by USB

A blank board needs one USB flash. After that, both boards can be updated over the air through the
portal.

> **Danger — read the Hardware Bible's safety chapter before you connect a cable** (chapter 2, and the
> earth and grounds in chapter 5). The tube radio in this machine is tied to the mains. Read those
> chapters before you connect any cable from the machine to a mains-powered PC. The portal's console and
> its updates exist partly so that no cable is needed after the first flash.

```
pio device list                                     # find your S3 by SER=<its MAC>
pio run -e s3  -t upload --upload-port COMx         # the port you found, never automatic
esptool.py --port COMy read_mac                     # confirm the A32 is the board you mean
pio run -e a32 -t upload --upload-port COMy
pio device monitor -p COMx -b 115200                # the S3's console
```

Practical notes:

- On this machine both boards entered their download mode by themselves; no button presses were
  needed.
- The S3's console runs on its native USB port, which does not reset the chip when a monitor opens. You
  therefore miss the start-up banner. That is why the console key `s` prints the status and the command
  list. To see the banner, reset the board first (for example with `esptool.py --after hard_reset`),
  then open the monitor.
- A serial tool that opens the port with DTR and RTS asserted (the default of Python's `pyserial`)
  resets the board. It once made every reading show "uptime 1 s".
- The S3 has no wire to reset the A32. After its first USB flash, the A32's only update route over the
  air is the relay through the S3 (section 3.10.3); a USB flash remains the way to recover it.

## 3.9 The first boot

What the S3 does at start-up, step by step, is in chapter 4, section 4.2. Here is what a builder meets,
in order, on a factory-fresh pair of boards:

1. **No stored settings.** The compiled defaults apply (Appendix A lists them).
2. **No stored WiFi network.** The S3 raises its **rescue access point** at once: network name
   `Ambersong`, on channel 1, an open network with no password. Join it; on most phones the portal's
   sign-in page opens by itself. Otherwise open `http://192.168.4.1/`, or `http://ambersong.local/`.
   Set your house network from the portal's System tab, Network card, or with the console key `y`. If a
   stored network cannot be joined within 20 s, the rescue access point comes up and the house network
   is retried every two minutes. The transmit power starts at its lowest rung, 2 dBm, and climbs on
   failed joins; the ladder and its 15 dBm ceiling are in chapter 8, section 8.4.
3. **The placeholder portal account.** The firmware ships with a public placeholder account. While
   the stored account still matches it, the portal refuses everything except changing the password.
   Only `/api/boot`, `/api/state`, `/api/passwd` and `/api/logout` are let through. Every other request
   gets HTTP 403 `mustchg`, and the page shows only the change-password form. Both update endpoints
   refuse too. **Change the password first.** The console key `~` erases all accounts and restores the
   placeholder. An administrator can type it in the portal's Console tab; if nobody can sign in any
   more, the USB cable is the only way to type it. That is by design: there is no front-panel reset for
   a forgotten password (chapter 8).
4. **The clock.** The battery clock on the A32 keeps time, and network time corrects it once the S3 is
   online. The console key `W` sets it by hand. That prompt reads your input in a fixed eastern North
   American time zone, whatever the portal's time-zone setting (chapter 4, section 4.9). A new clock
   module may come up with no valid time. The portal then shows
   **BATTERY CLOCK LOST ITS TIME - check its battery** until the clock reports a valid time again. It
   is asked every minute.
5. **Needle calibration.** The needle has no end switches. Calibrate in this order:
   1. the band calibration (`k`) with the needle on its index sensor (it saves its result by itself);
   2. the soft limits (`m`, `M`);
   3. the tuner ends (`c`, `C`), which the firmware also uses at every boot to pick the turn of the
      tuning shaft;
   4. the dial marks.

   Chapter 5 explains each step.
6. **The dial's self-calibration.** With the set plugged in but its front switch off, sweep and mark the
   fixed spurs (`q`, `o`). With the front switch off, the amplifier, and with it the tube set, is off, so its
   oscillator is not running, and every peak the sweep finds is a fixed spur. Then switch the set on,
   select RADIO, and measure three positions spread across the dial (`V`, or **Measure
   this dial position** on the portal). From then on the radio keeps its own calibration up to date.
   Chapter 6 explains the method.

**The A32 at first boot** arms its 15-second watchdog as the very first step. It then runs its own link
self-test: a failure mutes it and keeps it off Bluetooth, but the board stays reachable for an update.
It loads its settings, reads the clock chip, and waits for the S3's HELLO message (chapter 9).

**A program written by USB is never on trial**, on either board. The S3's image line then reads
`not tracked (USB flash)`, and both boards save their settings normally from their first boot.

## 3.10 Updating over the air

The portal's **System** tab has two file pickers, one per board. Choose the matching `firmware.bin` and
upload it. Behind them are two HTTP endpoints, both taking a multipart file upload of `firmware.bin`:

| Endpoint | Target |
|---|---|
| `POST /api/ota/s3` | the S3 itself |
| `POST /api/ota/a32` | the A32, relayed by the S3 |

**To script an update**, sign in with `POST /api/login` (form fields `u` and `p`; the answer sets a
session cookie), then post the file to the endpoint with that cookie. Keep the credentials in
environment variables, never in the script.

**Do not trust the HTTP answer of an update that restarts the board.** Several transfers reported a
failure and had in fact landed. Confirm by reading the version after the restart (section 3.13).

### 3.10.1 What both endpoints check first

- **Administrators only.** Another account gets `403 admin only`.
- **Not with the placeholder password.** The shipped account gets
  `403 change the default password first`.
- **The right chip.** Bytes 12 and 13 of an ESP32 program image hold the chip number: `0x0009` for an
  ESP32-S3, `0x0000` for a classic ESP32. On the first chunk, each endpoint refuses an image built for
  the other chip, before anything is written. The two pickers sit side by side and the two files have
  the same name, so this mistake is easy to make.
- **The upload watchdog.** If no chunk arrives from the browser for 15 s, the S3 aborts the update and
  goes back to work. The web server does not reliably report a connection that died mid-upload, and a
  dead transfer once left the machine muted for four minutes.

### 3.10.2 Updating the S3

Updating the main board over the air.

1. **Is the running program still on trial?** If it is, the update is refused (section 3.11.4). Nothing
   is stopped or darkened, and the bytes that keep arriving are dropped. The console prints
   `portal: S3 update refused - this image is still on trial.` At the end the page gets HTTP 409 with
   `{"e":"this firmware is still on trial - retry in a minute"}`. The browser still sends the whole
   file before that answer comes back.
2. **Otherwise the S3 streams the file into its idle program slot.** While it writes, it stops the
   needle where it is, blanks the clock digits and darkens the panel lamps. Writing flash suspends the
   processor's flash cache, which would make those animations stutter; fifteen dark seconds read better than
   fifteen ugly ones. **The sound keeps playing**, because it lives on the A32.
3. **On success** the S3 clears its "update in progress" flag and saves any pending settings (a failed
   save is reported as a warning). It answers `200 rebooting into the new firmware`, waits 300 ms and
   restarts.
   The new program boots on trial (section 3.11). The needle remembers its position across the restart
   and homes from there (chapter 5).
4. **If the upload fails and the S3 does not restart**, the needle and the display come back as they
   were (chapter 4, section 4.8). That happens on a wrong chip, an aborted or failed write, or 15 s
   without data.

### 3.10.3 Updating the A32 through the S3

Updating the audio board: the main board relays the file over the link, one acknowledged kilobyte at a time.

The A32 cannot be reached by WiFi. The file goes to the S3 over WiFi. The S3 relays it to the A32 over
**the link**, the serial line between the boards (921 600 baud, framed and checksummed; chapter 9).
The S3 stores nothing: it is a pipe.

1. **Begin.** The S3 refuses with `the A32 is not answering` if the A32 has not said HELLO. The A32
   refuses with `still on trial - retry in 1 min` if its own running program is still on trial; the
   portal shows `A32: still on trial - retry in 1 min (err 0)`. Otherwise the A32 remembers your mute
   setting and mutes. It waits 400 ms for the fade and for its audio buffers to drain (chapter 9
   explains the figure), then opens its idle slot. Opening erases nothing; the slot is erased a sector at a time as
   the data is written. The S3 waits up to 20 s for this answer. **The S3 does not stop its needle or
   darken its display**, because it is not writing its own flash; the sound stops because the A32 is.
2. **The chip check.** It runs on the first chunk, after the begin, so the A32 has already muted. A
   file built for the S3 is aborted with `that image is not for the audio board (wrong chip) - nothing
   was written`, and the abort restores the A32's mute. A file that is not an ESP32 image at all (its
   first byte is not 0xE9) passes this check and is refused by the A32's updater instead (error 8,
   magic byte).
3. **Data.** The S3 cuts the upload into 1 KB frames, each carrying its offset and its length. The A32
   writes a frame only if it starts exactly where the image so far ends. It acknowledges every frame
   with the number of bytes it has actually written. The S3 moves on when the acknowledgement equals
   offset plus length. It sends the frame again when the acknowledgement equals the offset (a duplicate
   or a late acknowledgement lands here harmlessly). It gives up on anything else
   (`A32 is at X, we are at Y`). Each frame gets 4 tries of 3 s; four silences give
   `no answer at N bytes`.
4. **End.** The S3 sends the CRC32 checksum of the whole image. Neither the size nor the checksum is
   known at the start, because the upload is streamed. The A32 checks it (`crc mismatch` if it
   differs), finishes the update, switches its boot slot, answers `ok, rebooting` and restarts 250 ms
   later. The S3 waits 4 s for that answer. If it does not come, the portal says
   `the A32 did not confirm the update - check its version once it reconnects`. The A32 commits before
   it answers, so a lost answer can hide a good update. On success the page shows
   `<N> bytes sent, the A32 is rebooting`; on a failure, HTTP 500 with the reason.
5. **After the end**, the S3 forgets the A32's HELLO, so the next handshake shows the new version. The
   new program boots on trial (section 3.11).
6. **If frames stop arriving for 20 s**, the A32 gives up by itself (`the S3 stopped sending`) and
   restores your mute setting, not "unmuted". A begin that arrives while an update is already running
   is refused (`begin refused`), and the running update is given up the same way.

**A failed relay keeps the old program.** The reason reaches the page, including the A32 updater's
error number. The numbers are: 1 write, 2 erase, 3 read, 4 space, 5 size, 6 stream, 7 MD5, 8 magic byte, 9 activate, 10
no partition, 11 bad argument, 12 abort.

**The relay is slow on purpose:** about 16 KB/s; a full A32 program of 1.2 MB took 76 s. Each frame
waits for its acknowledgement, and each acknowledgement waits for a flash write. A transfer that cannot
tell whether it arrived is not worth having faster.

## 3.11 Trial, confirmation and rollback

**Rollback** means this: a freshly updated program runs **on trial**, and unless it **confirms** itself,
the bootloader goes back to the previous program at the next reset. Both boards work this way, and this
section is the one place in the book that tells the whole story.

The bootloader of the pinned core is built with application rollback. By default the Arduino core marks
every new program valid before the program's own start-up runs. A build that crashed or hung at boot
would then loop on itself until someone used the USB cable. Both programs instead tell the core "this
firmware confirms itself". A program written over the air therefore boots on trial. If the board resets
for any reason before the program is confirmed, the bootloader marks it invalid and starts the previous
one, which is still in the other slot.

The life of a new program on either board: on trial, then confirmed or rolled back.

### 3.11.1 How each board names the state

The S3 prints an **image line** at the end of its start-up and in the console's `s` status:
`image      : <state>, watchdog on|OFF`. The A32 puts the same state in its **boot report** (section
3.11.7).

| State | Meaning |
|---|---|
| `ON TRIAL (rollback armed)` | A new program sent over the air, not yet confirmed. |
| `valid` | A confirmed program. |
| `valid (confirmed)` | Shown after the program confirmed itself during this run. |
| `NEW - this bootloader has no rollback` | The bootloader did not arm the trial. |
| `not tracked (USB flash)` | A program written by USB. It is never on trial. |

Whenever the bootloader has marked an earlier program invalid, the line ends with
` - an earlier update was ROLLED BACK`.

### 3.11.2 What earns confirmation

| | S3 (main board) | A32 (audio board) |
|---|---|---|
| When it checks | Not before 60 s of running, then once every 10 s. The first check only takes a reading, so the earliest confirmation comes about 70 s after start-up; expect 70 to 90 s. | 60 s after its first handshake with the S3. |
| What it needs | **The portal task still turning** (its pass count has moved since the previous check); **a network up** (the house network joined, or the rescue access point up); **a passed link self-test**. | **A handshake with the S3** and **a passed link self-test**. If after 5 minutes nothing at all has ever arrived on the link — no valid frame and no damaged one — it confirms anyway. |
| What it never waits for | The A32 and the needle. | — |
| What it prints | `image confirmed (a minute of running, network and portal up).` | `[A32] image confirmed (a minute of running with the S3)`, or `(five minutes running, the S3 never spoke)` |
| If the confirmation itself fails | `image confirm FAILED (err N) - retrying`, again 10 s later. Until it succeeds, a reset still rolls back and updates are still refused. | The same message and the same retry. |

**Why the S3 asks only for a way in.** Confirmation asks for what the next update needs: a portal and a
network. A broken or absent audio board must not roll back a good main board, and a homing fault is
about the mechanism, not the build.

**Why the A32 waits a minute after the handshake.** The handshake arrives about a second after start-up,
before the A32 has woken, opened Bluetooth or played anything. Confirming there would accept a build that
crashes a moment later.

**Why the five-minute fallback.** It keeps a good A32 program from being thrown away just because the S3
was absent. It applies only when nothing at all arrived. A program whose link is broken in a way that
still produces bytes stays on trial: damaged frames, or valid frames that never include a HELLO. The
next reset then takes the old program back.

### 3.11.3 What ends a trial in a rollback

**Any reset before confirmation:**

- a crash;
- a hang caught by the 15-second task watchdog (chapter 4, section 4.11 for the S3; chapter 9 for the
  A32), or by the S3's interrupt watchdog;
- **Reboot the main board** or **Reboot the audio board** on the portal (section 3.11.6);
- a power cut, or unplugging the set.

The rolled-back board runs its previous program exactly as before. A crash, a watchdog reset and a
reboot count as software restarts. After a rollback on the S3 caused by one of them, the needle homes
from the position it remembered. After a power cut it is assumed at the low stop (chapter 4, section 4.10;
chapter 5).

### 3.11.4 No second update during a trial

While a board's program is on trial and not yet confirmed, **a new update of that board is refused**. The
new program would be written into the other slot, which holds the very program a rollback returns to.
A second bad build would leave nothing to fall back on.

- **The S3** decides on the first chunk. It darkens nothing, and the needle keeps running. The answer
  is HTTP 409 `this firmware is still on trial - retry in a minute`, but only after the browser has sent
  the whole file.
- **The A32** refuses at the begin, before anything is muted: `still on trial - retry in 1 min`.
- An A32 update is not affected by the S3's trial.

Wait for the `image confirmed` line, then upload again.

### 3.11.5 No settings are saved during a trial

**On the S3**, settings changed during the trial are applied at once, kept in RAM and marked unsaved. The
ordinary two-second save writes them on the first pass after the program is confirmed. The portal's
Save answers `NOT saved yet - this firmware is on trial after an update; settings are written once it
is confirmed (about a minute)`. The console prints
`save held - this firmware is on trial; settings are written once it is confirmed.` The WiFi network
and the portal accounts live in their own namespaces and are not held: they are saved at once, trial or
not.

**On the A32**, a change sent from the portal is applied at once and kept in RAM. The moment the
program is confirmed, the A32 writes it and sends `settings changed during the trial are now saved`.
The S3's console prints that as `[A32] ...` next to the confirmation line (it can come one line
before it). If that write fails, the A32's ordinary save retry takes over and says so (chapter 7).

**Why.** A new program may change the layout of the stored settings. On the S3 it migrates the stored
settings when it starts. Had it written them and then been rolled back, the previous program would find
a layout newer than it knows, and lock its settings (**SETTINGS LOCKED**, chapter 7). The A32 keeps a
stored settings structure only if its size matches exactly, so a rolled-back A32 would run that
structure on its defaults. With nothing written until confirmation, a rolled-back program always finds
its settings exactly as it left them. **So a settings layout change is safe over the air on both boards,
with no special step.** Downloading a settings file before any update is still a good habit.

**The cost.** A change made during the trial minute is lost if the trial ends in a reset: a rollback, a
reboot of that board, or a power cut.

### 3.11.6 A reboot during a trial is a rollback

**The S3.** An ordinary portal reboot first saves the settings, and refuses if the save fails (chapter
8). During the trial there is nothing it may save. So **Reboot the main board** skips the save and the
needle stop. It answers `rebooting - this firmware was still on trial, so the previous firmware comes
back`, and restarts at once. The bootloader then starts the previous program. This button is the way to
take back an S3 update that misbehaves in its first minute. Refusing would take away the one button that
undoes a bad update.

**The A32.** **Reboot the audio board** during the trial forces a save that writes nothing, and the
restart is a rollback like any other reset.

### 3.11.7 Reading the outcome without a cable

**The S3's image line**, in the console's `s` status (readable on the portal's Console tab), for example
`image      : ON TRIAL (rollback armed), watchdog on`. The status also gives the last reset reason
(chapter 4, section 4.10).

**The A32's boot report**, sent once per A32 start-up at the first HELLO from the S3, and printed on the
S3's console:

```
[A32] boot: commit <hash>, reset reason N, setup X ms, image <state>, watchdog on|OFF
```

with ` - an earlier update was ROLLED BACK` appended when the bootloader has marked a slot invalid.
Reset reason 6 is the task watchdog. Chapter 9 explains every field. The report is not repeated if the
S3 restarts and handshakes again.

**A failed link self-test.** Each board tests its own frame encoder and decoder at start-up. Only a
broken build can fail it. Neither board halts:

- **The S3** prints `[FAIL] proto self-test - this image will NOT be confirmed;` and
  `reboot to roll back, or upload a good build.` It then starts as usual: display, needle, link, WiFi
  and portal. The program is simply never confirmed. Sent over the air, it stays on trial, so a portal
  reboot rolls it back (S3 updates are refused meanwhile). Written by USB, it is not on trial and
  cannot roll back; upload a good build through the portal.
- **The A32** stays muted and closed to Bluetooth, but keeps its link and its update receiver, and says
  `proto self-test FAILED - muted, BT closed, awaiting OTA` every 10 s. It is never confirmed, so the
  next reset takes the previous program back.

## 3.12 Walk-through: updating both boards

This is the whole round trip, with no USB cable connected. When a release changes only one board,
update only that board. It assumes the two boards share one protocol version. If the portal shows
**BOARDS RUN DIFFERENT PROTOCOL VERSIONS - flash both**, the relay in step 6 cannot reach the audio
board: follow section 3.13 instead. A release that itself changes the protocol version needs the opposite
order, audio board first (chapter 9, section 9.14.5).

1. **Build both environments and check both exit codes** (section 3.6). Note the commit you built
   from. If the build printed `-dirty`, you are about to send code that no commit names.
2. **Sign in to the portal as the administrator** and open the **System** tab. Its "running" line shows
   the S3's current `v.1.<stamp> (<hash>)`.
3. **Choose `.pio/build/s3/firmware.bin` in the main board's picker, and upload.** The clock goes
   blank, the panel lamps go dark and the needle stops; the sound keeps playing. When the program is
   written the page reports `rebooting into the new firmware`, and the S3 restarts 300 ms later.
4. **Reload the page** (sign in again if it asks). Check that the "running" line shows the new stamp and
   hash. On the Console tab, `s` ends with `image      : ON TRIAL (rollback armed), watchdog on`.
5. **The trial minute. Leave the S3 alone.** Another S3 upload now is refused with
   `this firmware is still on trial - retry in a minute` (HTTP 409), and nothing is written. Settings you
   change now are held in RAM (section 3.11.5). If the new program misbehaves, press **Reboot the main
   board**. The page answers `rebooting - this firmware was still on trial, so the previous firmware
   comes back`. The S3 returns to the program it had before, with its settings as they were.
   Otherwise, about 70 to 90 seconds after the restart, the console prints
   `image confirmed (a minute of running, network and portal up).` From then on the program is
   permanent, held settings are written, and a new S3 upload is accepted.
6. **Choose `.pio/build/a32/firmware.bin` in the audio board's picker, and upload.** The sound stops;
   the S3's clock, lamps and needle carry on. The relay takes over a minute for a full program. The page
   reports `<N> bytes sent, the A32 is rebooting`.
7. **On the S3's console, watch for three lines.** First the A32's boot report,
   `[A32] boot: commit <hash>, ... image ON TRIAL (rollback armed), watchdog on`. Then
   `[PASS] A32 up: proto v4, firmware v.1.<stamp>` at the new handshake. A minute later,
   `[A32] image confirmed (a minute of running with the S3)`. An A32 upload started inside that minute is
   refused with `still on trial - retry in 1 min`. Audio-board settings changed in that minute are held;
   if there were any, `[A32] settings changed during the trial are now saved` appears next to the
   confirmation.
8. **If either board comes back with `- an earlier update was ROLLED BACK`** in its image line or boot
   report, the new program failed its trial. The board runs the one it had before. Read the reset
   reason (`s` on the S3; the boot report for the A32), fix the build, and upload again.

## 3.13 Versions, and where to read them

The firmware carries **four independent numbers**. Do not confuse them.

| Number | Set in | What it means | Changes when |
|---|---|---|---|
| `FW_VERSION`, for example `v.1.20260926T101500` | `scripts/version.py` | Which binary: MAJOR plus the build time. | Every build. |
| `FW_COMMIT`, for example `a1b2c3d` or `a1b2c3d-dirty` | `scripts/version.py` | Which source it was built from. | Every commit, or uncommitted changes. |
| `PROTO_VERSION`, 4 | `include/proto.h` | Compatibility on the link between the two boards. | A protocol change that breaks compatibility. |
| `SETTINGS_VERSION`, 7 | `src/s3/main.cpp` | The layout of the S3's stored settings. | A settings layout change (append-only, with a migration; chapter 7). |

**MAJOR means only "the author's release".** It is `1` from the v.1.0 release, and it changes only when
the author declares a new release. Before v.1.0 it was `0`; reaching `1` meant the firmware fully
calibrated, updates over the air confirmed, and every outstanding problem resolved. A protocol break is `PROTO_VERSION`'s job, not MAJOR's.

**Releases.** Each release is marked in the firmware repository by an annotated git tag. The tag names a
commit; the version stamp still carries only MAJOR, so every build reads `v.1.<stamp>`.

| Tag | Boards changed | S3 build on the radio | A32 build on the radio |
|---|---|---|---|
| `v.1.0` | both | `v.1.20260925T200355` | `v.1.20260925T200411` |
| `v.1.0.1` | S3 only | `v.1.20260925T211316` | unchanged |
| `v.1.0.2` | both | `v.1.20260925T222141` | `v.1.20260925T222159` |
| `v.1.0.3` | both | `v.1.20260926T103447` | `v.1.20260926T103503` |
| `v.1.0.4` | A32 only | unchanged | `v.1.20260926T113302` |
| `v.1.0.5` | S3 only | `v.1.20260927T101323` | unchanged |

The pair this book describes is the S3 at `v.1.0.5` (`v.1.20260927T101323`) and the A32 at `v.1.0.4`
(`v.1.20260926T113302`), both sent over the air and confirmed. When a release changes only one board,
the two boards run builds from different commits. That is normal, and the handshake is what tells them
apart. Chapter 11 has the release notes.

**When the two boards run different protocol versions.** At the handshake each board sends its
`PROTO_VERSION` and `FW_VERSION`. But the link drops every frame whose protocol number is not its own,
before anything reads it, and counts it. So boards with different protocol versions never complete a
handshake: the link simply looks silent, like a broken cable. The count is what tells the two apart:

- the `link` line of the console's `s` shows a `wrong-version` count above 0, followed by
  `<- the boards run different protocol versions: flash both`;
- while the link is down, the portal shows the pill
  **BOARDS RUN DIFFERENT PROTOCOL VERSIONS - flash both**;
- `GET /api/state` carries the count as `linkver`.

**What to do when they differ.** "Flash both" needs the right order, because the relay to the audio
board refuses (`the A32 is not answering`) while the versions differ:

1. **Update the main board first**, over its own WiFi, with a build whose protocol version matches the
   audio board's. The main board's own update does not use the link, so the mismatch does not block it. Once the
   versions match, the handshake comes back.
2. **Then update the audio board** through the main board's portal, if it needs a new program too.

If the audio board is still on trial after its own update, unplugging the set also works: it rolls back
to its previous program. Once the audio board has confirmed its program, the mismatch survives a power
cycle. To move both boards to a new protocol version on purpose, chapter 9, section 9.14.5 gives the one
order that works over the air.

Fields added at the end of the A32's status report do not change the protocol version. An older peer's
report then has the wrong length and is rejected. So a half-updated machine loses its telemetry but
keeps its sound (chapter 4, section 4.10; chapter 9 has the full story).

**Where to read each board's version.** Each board shows its version in different places:

| Board | Where |
|---|---|
| S3 | The portal's System tab, line "running": `v.1.<stamp> (<hash>)` (the schema field `fw`, from `GET /api/schema`, or inside `GET /api/boot` whenever the browser's cached schema is out of date, which it always is after an update). The console banner, `firmware v.1.<stamp> (<hash>)`. The second line of a downloaded settings file, `# firmware v.1.<stamp> (<hash>)`; the first is `# Ambersong settings`. |
| A32 | Only on the S3's console, which the portal shows: `[PASS] A32 up: proto vN, firmware <version>` at each handshake, and the boot report, `[A32] boot: commit <hash>, ...`. No portal field carries the A32's version. |

> **For firmware changes**
>
>
> The portal's cached settings schema is keyed on `FW_VERSION` plus the administrator flag, so every new
> S3 build makes browsers fetch a fresh schema.
>

## 3.14 Build and update constants

Nothing in this chapter is a user setting. These are the values that govern building and updating.

> **For firmware changes**
>
>
> | Name | Value | Meaning | Where |
> |---|---|---|---|
> | `platform` | `espressif32@7.0.1` | PlatformIO platform: Arduino core 2.0.17 on ESP-IDF 4.4.7. Pinned. | `platformio.ini` |
> | ESP32-A2DP | commit `3245602afc494f9e62160a0cfb2af864af45a37f` (v1.8.11) | The A32's only library. Pinned. | `platformio.ini`, `lib_deps` |
> | `MAJOR` | 1 | The author's release number. | `scripts/version.py`, by hand |
> | `FW_VERSION` | `v.MAJOR.YYYYMMDDTHHMMSS`, at most 23 characters | Which binary. | `scripts/version.py`, every build |
> | `FW_COMMIT` | 7-character short hash, plus `-dirty`; or `nogit` | Which source. | `scripts/version.py`, every build |
> | `PROTO_VERSION` | 4 | Link compatibility. | `include/proto.h`, by hand |
> | `PROTO_VERSION_LEN` | 24 bytes | The version field in the handshake. Changing it is a protocol change. | `include/proto.h` |
> | `PROTO_MAX_PAYLOAD` | 1088 bytes | Largest frame payload: a 1024-byte update chunk plus its header. | `include/proto.h` |
> | Page compression | gzip level 9, `mtime=0` | The portal page in program memory. | `scripts/page.py` |
> | Upload watchdog | 15 s | Abort an upload with no chunk for this long. | S3 portal |
> | S3 restart after an update | 300 ms | Time for the HTTP answer to leave. | S3 portal |
> | A32 begin answer wait | 20 s | The A32 preparing its idle slot. | S3 relay |
> | A32 fade wait before writing | 400 ms | Mute fade plus audio buffer drain. | A32 |
> | Relay frame | 1024 bytes | Update data per frame. | S3 relay |
> | Relay tries per frame | 4 × 3 s | Resend budget. | S3 relay |
> | A32 end answer wait | 4 s | Waiting for `ok, rebooting`. | S3 relay |
> | A32 relay give-up | 20 s | No frame for this long ends the A32's update. | A32 |
> | A32 restart after the end | 250 ms | — | A32 |
> | A32 trial confirmation | 60 s after the handshake, or 300 s with no traffic from the S3; retry every 10 s | When a relayed program becomes permanent. | A32 |
> | A32 task watchdog | 15 s | A frozen main loop resets the chip. | A32 |
> | S3 trial confirmation | not before 60 s, then a check every 10 s; earliest about 70 s | When an S3 program becomes permanent. | S3 |
> | S3 task watchdog | 15 s, on the main loop and the needle supervisor | A hang becomes a reset. | S3 |
> | Settings writes during a trial | none, on either board | Changes wait in RAM until confirmation. | S3 and A32 |
> | S3 portal reboot during a trial | at once, no save attempted (200 ms for the answer) | A reboot of a trial program is a rollback. | S3 portal |
>

## 3.15 When it goes wrong

| What you see | What happened | What the firmware does | What you do |
|---|---|---|---|
| The S3 build fails at the page step | The portal page's script does not parse. | Stops the build. | Fix `data/portal.html`. |
| `[WARN] esprima not installed - the portal's script was NOT checked.` | `esprima` is missing from PlatformIO's Python. | Builds without the check. | Install `esprima` there (section 3.6). |
| A build reports success but the exit code is not 0 | It did not build. | — | Trust the exit code. |
| An upload is refused for the wrong chip | The file in that picker was built for the other board. | Refuses before writing. For the A32: `that image is not for the audio board (wrong chip) - nothing was written`. | Pick the other file. |
| An upload stops halfway | The browser's connection died. | Aborts after 15 s without a chunk; the S3 goes back to work. | Upload again. |
| An S3 update fails without a restart | The write failed. | Reports it; the needle and display come back as they were. | Upload again. |
| The page reports a failure, yet the board restarted | The restart beat the answer. | — | Read the version on the System tab after the restart. |
| `this firmware is still on trial - retry in a minute` (HTTP 409) | The running S3 program is still on trial. | Drops the upload; darkens nothing. | Wait for `image confirmed`, then upload again. |
| `A32: still on trial - retry in 1 min` | The running A32 program is still on trial. | Refuses before muting. | Wait a minute. |
| `the A32 is not answering` | The A32 has not said HELLO. | Refuses to begin. | Wait for the handshake (chapter 9). |
| The relay stops mid-stream; the sound stays off until the A32 gives up 20 s later, and the A32 keeps its old program | The relay stopped mid-stream. The S3 sends no abort for a failed frame. | The A32 gives up after 20 s and restores your mute setting. | Upload again. |
| `the A32 did not confirm the update - check its version once it reconnects` | The A32's final answer was lost. It commits before it answers, so the update may well have landed. | Re-handshakes. | Read `[PASS] A32 up: ...` on the console. |
| `- an earlier update was ROLLED BACK` | A new program crashed or hung before it was confirmed. | The bootloader started the previous program. | Read the reset reason, fix the build, upload again. |
| A new S3 program misbehaves, still on trial, portal reachable | — | Nothing by itself. | **Reboot the main board**: it rolls back at once. |
| A new S3 program never confirms | Its portal task stalled, or no network came up. | Stays on trial; S3 uploads are refused. Never exercised on the radio. | Any reset returns the previous program. With the portal unreachable that means unplugging the set, because the front switch neither resets the S3 nor removes its power. A BLOCKER, but no longer one that needs the USB cable. |
| `[FAIL] proto self-test - this image will NOT be confirmed` | A broken S3 build. | Boots as usual; never confirms. Never exercised on the radio. | Sent over the air: **Reboot the main board** rolls it back. Written by USB: upload a good build through the portal. |
| A relayed A32 program crashes or hangs at start-up | — | The A32's watchdog or the crash resets it; the bootloader starts the previous program; the boot report says `ROLLED BACK`. | Nothing; fix the build. |
| A relayed A32 program runs but never completes a handshake | Bytes arrive from the S3, but no HELLO. | Stays on trial, never confirmed. Never exercised on the radio. | A reset returns the previous program. The S3 cannot reset the A32 without the link, so unplug the set: the front switch does not remove the A32's power. A BLOCKER. |
| `image confirm FAILED (err N) - retrying` | The confirmation write failed. | Retries every 10 s; updates refused meanwhile. Never exercised on the radio. | Nothing. |
| Settings changed during a trial are gone | The trial ended in a reset: rollback, a reboot of that board, unplugging. | Nothing was written; the stored settings are those from before the update. | Set them again once a program is confirmed. |
| **SETTINGS LOCKED** after a deliberate downgrade | The older program does not know the stored settings version. | Runs on defaults; writes nothing. Never exercised on the radio. | Upload a complete settings file (chapter 7). |

## 3.16 Design choices

- **The platform pinned at `espressif32@7.0.1` (core 2.0.17).** The A32's audio needs the legacy I2S
  driver, which the Bluetooth library drives directly only on core 2.x.
- **The Bluetooth library pinned to one commit.** The A32 overrides its internals, and an unpinned
  dependency changes whenever the `.pio` folder is rebuilt.
- **One project, two environments, one shared `include/`.** The pin map and the protocol must be the same
  file for both boards by construction; a pin map kept in more than one place drifted apart five times
  during bring-up.
- **The version stamped at build time from the build PC's clock.** The useful question is "which
  binary", and the boards run builds from different moments because the S3 updates the A32.
- **A separate commit stamp, never inside the version.** It would not fit the 24-byte handshake field,
  and widening it is a protocol change.
- **The portal page compressed at build time and served from program memory.** Uncompressed page loads
  took 0.7 to 3.6 s on a server that handles one connection at a time. Every browser accepts gzip. The
  chip's ROM has a decompressor but no compressor, so compressing per request would only move the
  cost.
- **A zero gzip timestamp.** An unchanged page gives byte-identical data, so the ETag holds across
  rebuilds and a reload costs one empty "304 Not Modified".
- **The build fails if the page's script does not parse.** A duplicated declaration once shipped a dead
  page; a syntax error is the one class of bug a machine can catch for free.
- **No filesystem for the page.** Nothing to upload separately, nothing to fall out of step.
- **Two program slots on the A32 (`min_spiffs.csv`).** Without a second slot there is no update over the
  air, and the A32 is inside the cabinet.
- **The A32 updated through the S3, one acknowledged 1 KB frame at a time, a whole-image CRC32, and a
  final answer required.** The A32 has no network and no reset wire from the S3. A transfer that cannot
  tell whether it arrived is worse than a slow one.
- **The chip checked in the image header before anything is written.** The two pickers sit side by side
  and both files are called `firmware.bin`.
- **The A32 confirms a minute after the handshake (or after five minutes with no traffic at all), refuses
  updates on trial, and runs a 15-second watchdog.** An update that cannot boot must not need the USB
  cable. The watchdog turns a hang into the reset that triggers the rollback.
- **The S3 gets the same treatment: trial, refusal on trial, a self-test that degrades instead of
  halting, and a 15-second watchdog.** Otherwise an S3 build that crashed, hung or could not serve the
  portal needed the USB cable.
- **No settings written on either board during a trial.** A rolled-back program must never find a layout
  newer than it knows, and the defence must not depend on a person remembering a procedure.
- **A portal reboot during the S3's trial goes through at once.** There is nothing it may save, and
  refusing would take away the one button that undoes a bad update.
- **Every board identified by its MAC address, the port always given, and no flashing under
  observation.** Boards of one kind share USB numbers on the bench; an update during a listening or
  measuring session spoils it.

## 3.17 Tried and rejected

> **For firmware changes**
>
>
> - **One 3 MB program slot on the A32 (`huge_app.csv`)**, as the bench suite used: no room for an update
>   over the air.
> - **An unpinned Bluetooth library:** worked until the visibility rule came to depend on its internals.
> - **Sending the portal page uncompressed:** page loads of 0.7 to 3.6 s.
> - **Waiting 5 s for the A32 to answer the begin:** the update never started, consistently. Now 20 s.
> - **A 250 ms fade wait before the A32 writes flash:** too little margin once the audio buffers were
>   counted. Now 400 ms.
> - **Trusting the HTTP answer of an update:** several updates reported failure and had landed.
> - **Treating the relay's silent end as success:** a lost final answer hid whether the A32 had taken the
>   update, and the S3 went on showing the old A32 version.
> - **Confirming an A32 program at the first handshake:** the handshake lands before Bluetooth starts, so a
>   program that crashed later was already confirmed.
> - **Judging a build by searching its output for `SUCCESS`:** hid a linker failure.
> - **A version stamp without a commit:** matching a build to its source meant comparing build and commit
>   times.
> - **Letting the Arduino core confirm every new S3 program:** a build that crashed or hung at boot looped
>   on itself, and only the USB cable could fix it.
> - **Saving settings during the S3's trial, with a settings file kept as the key:** the defence was a
>   procedure to remember. Replaced by holding every write.
> - **Saving settings during the A32's trial, with advice to export a settings file first:** replaced by
>   the same hold.
>

## 3.18 Known limits

- **The A32's version is in no portal field.** It is readable only on the S3's console, at each
  handshake and in the boot report.
- **A relay that fails on a frame sends the A32 no abort.** It stays muted until its own 20-second
  give-up (chapter 12).
- **An A32 program built with the wrong `PROTO_VERSION` confirms itself after five minutes.** Frames of
  another protocol version count only as wrong-version frames. The five-minute fallback does not look
  at those, so to the A32 the S3 looks absent. The link stays down until both boards share a version; the
  S3 shows the wrong-version count and pill (chapter 12).
- **`- an earlier update was ROLLED BACK` stays in every image line and boot report** until the next
  update replaces the invalid program, so an old rollback can look like a new one (chapter 12).
- **The version stamp uses the build PC's local time with no time zone.** Builds made in different
  zones, or across a daylight-saving change, cannot be ordered by stamp alone.
- **A partition-table change always needs a USB cable.**
- **The downgrade lock has never been exercised.** Since settings are held during the trial, a rollback
  can no longer cause it; only a deliberate downgrade can.
- **Rollback has been seen working on both boards**, with a deliberately hanging program and with a
  portal reboot during the S3's trial. **Never exercised on the radio:** an S3 program that runs but never earns
  confirmation; a failed link self-test on either board; a confirmation write that fails; a reset during
  either board's trial with a setting changed in it.

## 3.19 Changing it safely

> **For firmware changes**
>
>
> **What must stay true**
>
> - `platform` stays `espressif32@7.0.1`, and the library commit stays pinned. If you move either, do it
>   on purpose, rebuild both boards, and re-test the A32's sound (radio, Bluetooth and AUX) and its
>   Bluetooth visibility in every mode.
> - `FW_VERSION` fits in `PROTO_VERSION_LEN - 1` = 23 characters. The commit hash never goes into it.
> - A change that breaks the link's compatibility bumps `PROTO_VERSION`. Appending fields to the status
>   report `ProtoState` does not. MAJOR is not touched for either.
> - NVS stays at 0x9000 in both partition tables, so stored settings survive a partition change.
> - Edit `data/portal.html`, never `src/s3/page_gz.h`.
> - Nothing secret goes into the source: WiFi credentials and accounts live only in NVS.
> - Both update handlers (`hOtaUpload()`/`hOtaEnd()` and `hOtaA32Upload()`/`hOtaA32End()` in
>   `src/s3/portal.cpp`) keep their own administrator and placeholder-password checks — they are the only
>   handlers that do not go through `requireLogin()` — and the chip check on the first chunk.
> - Any change to a trial keeps two properties: a program is confirmed only after it has shown that it
>   **runs**, not merely that it booted; and an update is refused while the running program is on trial.
>   On the S3, confirmation never waits for the A32 or the needle, and is never given to a program whose
>   link self-test failed; the same holds for the A32's self-test.
> - Both programs keep `verifyRollbackLater()` returning true, and the task watchdog stays the first thing
>   `setup()` does, so a hang anywhere in the start-up is caught.
> - Nothing reaches the S3's stored settings while its program is on trial: every write goes through
>   `settingsWrite()` in `src/s3/main.cpp`, which refuses on trial. A new path that writes the `amb3`
>   namespace directly would reopen the rollback trap.
> - The portal's reboot (`hReboot()`) never waits for, or refuses on, a save while the S3 is on trial.
> - The same on the A32: nothing reaches namespace `amb` while its program is on trial. Every write goes
>   through `settingsFlush()` in `src/a32/main.cpp`, which refuses on trial, and `confirmImage()` writes
>   what was held.
> - On the A32, the refusal of `MSG_OTA_BEGIN` while on trial, in its message handler, is the only guard:
>   the Arduino `Update` class writes the slot directly and does not go through the framework's own
>   "refuse while pending" check.
>
> **Where the code is.** The S3's trial and confirmation are in `src/s3/main.cpp`
> (`s3ImageOnTrial()`, `confirmTick()`, `imageReport()`, constant `CONFIRM_AFTER_MS`); its updates in
> `src/s3/portal.cpp`; the relay in `src/s3/main.cpp` (`a32OtaBegin()`, `a32OtaChunk()`, `a32OtaEnd()`).
> The A32's side is the `MSG_OTA_*` cases of its message handler, `confirmTick()`, `confirmImage()` and
> `bootReport()` in `src/a32/main.cpp`.
>
> **Traps**
>
> - `extra_scripts` in an environment replaces the common list. Keep `version.py` listed in the `s3`
>   environment.
> - `pio device list` shows a USB bridge's serial number, not the ESP32's MAC address. Use
>   `esptool.py read_mac` for boards behind a bridge.
> - The S3's native USB console does not reset the board when a monitor opens. The banner is gone by the
>   time you look.
> - `-dirty` looks only at tracked files. A new, untracked source file that is compiled in does not mark
>   the build dirty. Commit before building a release.
> - A setting changed during the S3's trial minute is only in RAM. It is written once the program is
>   confirmed, and lost if the trial ends in a reset.
> - A second S3 upload inside the trial minute is refused with HTTP 409 only after the whole file has been
>   sent. Wait for `image confirmed` first.
>
> **How to test a change here**
>
> 1. Build both environments and check both exit codes.
> 2. Update the S3 over the air. Confirm with the System tab's "running" line (version and commit), not
>    the upload's answer. The image line must read `ON TRIAL (rollback armed), watchdog on`.
> 3. Try a second S3 update inside the trial: it must be refused with HTTP 409. Change a setting and press
>    Save: it must answer that the settings are held until confirmation. Then wait for
>    `image confirmed (a minute of running, network and portal up).` If you changed anything about the
>    trial, also check the reboot rollback: send a program, press **Reboot the main board** during its
>    trial, and check that the S3 comes back on the previous commit with `ROLLED BACK` in its image line.
> 4. Update the A32 over the air. On the S3's console, look for the boot report
>    (`image ON TRIAL (rollback armed)`, `watchdog on`), the new version at the handshake, and
>    `image confirmed (a minute of running with the S3)` about a minute later.
> 5. Try a second A32 update inside that minute: it must be refused. Change an audio-board setting in that
>    minute (for example the Bluetooth lamp's `btLedOff`, then put it back): at the confirmation the
>    console must show `[A32] settings changed during the trial are now saved`.
> 6. If you changed anything about the trial or the watchdog, repeat the rollback test with a deliberately
>    hanging program (its main loop spinning for ever), sent over the air with the USB cables unplugged,
>    and watched through its rollback. **Never commit that program.**
> 7. Download a settings file and check that its second line, `# firmware ...`, names the new build and
>    commit.
>

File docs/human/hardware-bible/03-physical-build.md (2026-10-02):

# 3. The physical build

This chapter says where things are and how they are held, so that you can open the cabinet, find a part,
and repair or rebuild it. It describes this cabinet; yours will differ. Screw details for the printed
plates, cable routing and the length of each cable are not covered.

> **Danger — unplug the cord first.** The front power switch does not remove mains from the cabinet.
> Read chapter 2 before you open it.

## 3.1 The cabinet and how to open it

A **wooden cabinet** holds everything. The tube radio's original case has been stripped; its original
chassis sits in the cabinet. The table says how each main piece is held, so you know what to undo.

| What | How it is held |
|---|---|
| **Back panel** | An inverted-T panel of ½ in plywood behind the radio, held by ten countersunk 3 mm screws. |
| **Front panel** | Held from the inside by five 3 mm screws. |
| **Tube radio** | Two #8 ½ in wood screws through its tabs, one on each side. |
| **Everything else** | Almost every board and mechanical part is on a small perfboard or module in its own printed PLA case, or on a printed PLA carrying plate, screwed to the cabinet with #8 screws. |

**Every cable inside is under 14 in long**, long enough to service the machine with the panels open and
nothing unplugged.

The order in which the back panel and the front panel come off is not recorded.

Beyond this, the book does not describe where each module sits inside the cabinet.

## 3.2 The front panel

The table lists the controls and displays on the front panel, with the chapter that covers each one.
Where each one sits on the panel is not recorded.

| Control or display | What it is | Chapter |
|---|---|---|
| **Tuning knob** | A printed front knob, on a printed shaft extension, turns the tube radio's original tuning knob, which drives the dial cord and the tuning capacitor. Clockwise raises the frequency. | 8 |
| **Volume knob** | The audio board's volume control, read digitally. It is **not** the amplifier's volume control, which is reached only from the back. | 9 |
| **Source switch** | A three-position switch (double-pole, on–off–on): RADIO and BT at the two ends, AUX in the centre. | 9 |
| **Power switch** | The front power switch. It turns on the amplifier and the tube radio, but does not remove mains from the cabinet. | 2, 5 |
| **Bluetooth LED** | A single part that is both the Bluetooth LED and the Bluetooth button. | 9 |
| **Clock display** | Four seven-segment digits and a colon, made for this panel. | 7 |
| **FM panel lamps** | Four LEDs, dimmed together by the main board. | 9 |
| **FM panel** | The needle shows the rough FM position against a blackened brass plate. What it shows on AM and SW is not recorded. | 8 |

The source switch and the power switch are fixed in the wooden front panel itself, each by its own nut
and then plenty of hot glue.

The tube radio's own power and tone switch (S2) and its own volume control (R1) are **not** on the front
panel. Where on the radio they sit, and which position S2 is left in, are not recorded. The radio's volume
control sits at about one eighth of its travel (chapter 13, section 13.11).

The AUX jack is not in this list either. Where it sits is not recorded (chapter 6, section 6.7).

## 3.3 Tuning, needle and index

The printed front knob, on a printed shaft extension, turns the radio's original tuning knob, which
drives the dial cord and the tuning capacitor. A magnetic angle sensor
(AS5600) reads the capacitor's shaft. The needle sits on a printed mount on a small stepper motor, which
alone moves it. A magnet on that mount passes a Hall-effect switch, the needle's only position
reference. Chapter 8, section 8.1, describes the mechanics and how each part is mounted.

## 3.4 Cooling

Two fans move air (chapter 5, section 5.6):

- The **box fan** sits at the top of the back panel and blows air **out** of the cabinet. Fresh air comes
  in through two small louvred printed vents at the other two ends of the back panel's inverted T.
- The **cage fan** is screwed to the tube radio's Faraday cage and blows air **into** it.

## 3.5 The Faraday cages

Three earthed cages shield the tube radio, the angle sensor and the mains line filter. The cages over
the tube radio and the angle sensor are printed PLA boxes lined with aluminium tape. The tape is covered
with Kapton tape. The cage over the tube radio stands well clear of it. The line filter's cage is layers of
tape over the circuit. Chapter 5, section 5.4, describes each cage and how it is earthed.

## 3.6 Connectors and labels

This section lists the main connectors, and how the cables are marked.

- **Mains inlet:** a standard IEC C14 inlet, the one that came on the amplifier's aluminium back plate.
  That plate is at the back of the cabinet. The amplifier's own volume control is reached only from the
  back. Where the amplifier's input panel sits is not recorded.
- **Connectors that fit only one place.** Some connector types are used once only, so that a cable cannot
  be plugged where it would break something. The mains feed to the front power switch is one of them.
- **Labels.** Each cable is marked at both ends, with an evident name or with its name on the cable
  sheet. This book uses the cable sheet's names (chapter 10).
- **Power sockets.** The 5 V and 3.3 V buses are rows of small 2-pin JST XH sockets (chapter 5,
  section 5.5).
- **Back-panel USB-C ports.** One for each microcontroller board (chapter 4, section 4.6).
- **Antenna connector:** a BNC (J10) on the back panel, where the FM antenna's coax arrives (chapter 11).

## 3.7 Printed parts

Every printed part of this build is listed in Appendix D. All are PLA except the membrane of the passive
radiator, which is TPU.

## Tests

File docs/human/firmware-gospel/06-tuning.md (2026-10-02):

# 6. Tuning and the dial's self-calibration

You tune the radio with its original knob, which turns the tube set's own tuning capacitor. The
main board reads the angle of that capacitor's shaft and turns it into a frequency in megahertz
(MHz). That frequency drives the needle on the glass, the clock digits when they are set to show
tuning, and the **Now** readout on the portal. The relation between shaft angle and frequency is a
curve. It is not known in advance, and it can drift, so the machine measures it itself: a small FM
receiver chip inside the cabinet listens to the tube set's own oscillator and works out where the
set is really tuned.

Chapter 2, section 2.2 explains how the two sensors share the work: the angle sensor is the live
measure, and the receiver chip only calibrates the curve. Chapter 5 is the needle half of the chain.
This chapter is the tuning half.

> **Specific to this build — adapt.** The tuning chain is fitted to this LLOYDS TM-838N: its dial,
> its intermediate frequency and its local oscillator. Your set will differ. The method carries over.

## 6.1 What you see

1. **You turn the knob.** The needle follows, the portal's **Now** shows the frequency to a tenth of
   a MHz, and the clock digits show it too when set to (section 6.4).
2. **You listen to the radio and leave the knob alone.** After 8 seconds of stillness the radio
   measures the dial by itself, at most once every five minutes. The outcome appears on the portal's
   Needle tab, under *last measurement*. For example:
   `RE-MEASURED 106.1 MHz (LO 95.50, +36 over local) -> slot 4; 6 stored; curve QUADRATIC`.
   Section 6.8 works through this very line.
3. **You press Measure this dial position.** The same measurement, at once, with a slightly lower
   bar for what counts as found. It takes about 15 seconds when the curve already predicts well, up to
   about 85 seconds when it has to search the whole range. A refusal always says why.
4. **The measurements accumulate.** Nine slots hold measured samples. A measurement near an existing
   sample replaces it, so the positions you actually listen to keep being re-measured. Once all
   nine are full, a new position replaces the most crowded sample, so the nine stay spread across
   the dial.
5. **You can correct by hand.** You can type up to three stations you know by ear (the **hand
   marks** A, B and C), slide the whole curve in 0.1 MHz steps (the **dial correction**), reset that
   correction to 0, and remove any single sample. **Nothing automatic ever changes a hand mark or the
   dial correction.**
6. **You tune past the printed scale.** The clock digits stop at the end of the scale. The portal's
   **Now** keeps the true value and adds "(past the printed face)".

## 6.2 Radio terms you need

The tube set mixes the station with its own oscillator; the oscillator leaks to the RDA5807M, and the firmware adds the IF back.

**Superheterodyne ("superhet").** The tube set does not amplify the station it receives directly. It
generates a signal of its own, the **local oscillator (LO)**, and mixes the incoming station with it.
The mixer produces the difference between the two frequencies. That difference is fixed by design and
is called the **intermediate frequency (IF)**. All the set's filtering and amplification happen at
the IF. Turning the knob retunes the LO; the IF never moves. So at any knob position the LO and the
station differ by exactly the IF.

**Low-side injection.** The LO can run above the station ("high-side") or below it ("low-side"). This
set's FM oscillator runs **below** the station, so the firmware computes **station = LO + IF**. This
was measured on the bench (section 6.13), and the Hardware Bible records it (chapter 13).

**The IF value.** This set's FM IF is **10.6 MHz**. It was set when a professional tuned the FM path,
and the RDA5807M's readings of the oscillator agree with it. The 10.7 MHz on the set's drawing is the
design value. The firmware's IF is a setting, **Tube set IF**, with a default of 10.60 MHz (section 6.11).

**Why the LO can be heard.** A set of this age has nothing that stops its oscillator from radiating a
little. A receiver a few centimetres away hears it as a **bare carrier**: a signal with nothing
broadcast on it. The RDA5807M's antenna is a 30 cm wire inside the tube radio's cage, bent over the
radio's FM oscillator (Hardware Bible, chapter 8, section 8.5).

**Worked example.** The set is tuned to a station at 98.5 MHz. With an IF of 10.6 MHz the LO runs at
98.5 − 10.6 = 87.9 MHz. The RDA5807M, sweeping around 87.9 MHz, finds a carrier standing out there.
The firmware adds the IF back: 87.9 + 10.6 = 98.5 MHz. It reads the shaft angle at the same moment
and stores the pair (angle, 98.5 MHz) as a **sample**.

**RSSI.** "Received signal strength indicator": the strength number the RDA5807M reports for the
frequency it is tuned to, from 0 to 127 (bits 15:9 of its register 0x0B).

**Spur, fixed feature, notch.** A **spur** is a signal the RDA5807M hears that is *not* the tube
set's oscillator: interference made inside the cabinet itself. It stays at the same frequency
whatever the knob does. The firmware calls a learned spur a **fixed feature**, and around each one it
cuts a **notch**: the search may not choose any frequency within ±0.2 MHz of a fixed feature. On this
radio the spurs form a **comb** of seven peaks, at 79.0, 81.8, 84.6, 87.4, 90.3, 93.1 and 95.9 MHz,
2.7 to 2.8 MHz apart, present with the set switched on and off. One of them, 79.0 MHz, reads louder
than the oscillator. Their source is unknown (section 6.15).

**Stereo pilot.** An FM broadcast in stereo carries a 19 kHz "pilot" tone. A bare oscillator never
carries one. So when the RDA5807M's stereo indicator (register 0x0A, bit 10) is set on a strong
signal, that signal is a broadcast and not the LO. The indicator can only *reject*: a mono or weak
broadcast reads the same as a bare carrier.

**Floor, local floor, margin.** The **floor** of a sweep is the median RSSI of all its points. The
**local floor** of one point is the median of up to 16 neighbours within ±0.8 MHz of it. The
**margin** of a point is its RSSI minus its local floor. The firmware judges a peak by its margin,
never by its height.

## 6.3 Units and tasks

Several units are mixed on purpose. In the code, the end of a variable's name tells its unit.

| Name ending | Unit | Example |
|---|---|---|
| `f10`, `...10` | tenths of a MHz | 985 = 98.5 MHz |
| `f20`, `...20` | twentieths of a MHz (50 kHz steps) | 1971 = 98.55 MHz; IF 212 = 10.60 MHz |
| `acc`, `tuneP[]`, `calLow`, `calHigh` | angle sensor **accumulated counts**: 4096 per shaft turn, counted across turns | — |
| permille | 0 to 1000 across `calLow` … `calHigh` | shown only by the console `s` |

**On this radio the count falls as the frequency rises.** The firmware never relies on that direction:
every test compares sizes or the signs of slopes, never order.

> **For firmware changes**
>
>
> The tuning work runs in four places on the main board, all but the portal on core 1. Chapter 2,
> section 2.4 has the full task table.
>
> | Work | Runs in | Priority | Rate |
> |---|---|---|---|
> | Angle sensor read | the needle task | 4 | every 20 ms |
> | RDA5807M sweeps and fine passes | its own task, `rda` | 2 | looks for a request every 100 ms; each point takes at least 300 ms |
> | Measurement stages, automatic trigger, console keys, saving `lastAngle` | the main loop | 1 | every pass; `lastAngle` checked every 10 s |
> | Portal actions (measure, marks, settings) | the portal task, core 0 | 3 | on request |
>
> **The RDA task outranks the main loop on the same core.** A path in it that never pauses starves the
> main loop, and a main loop starved for more than 2 seconds mutes the audio (the link to the audio
> board times out). So every path in the RDA task pauses: 300 ms per measured point, 10 ms per failed
> point, 100 ms while idle. The main loop is also under a 15-second watchdog (chapter 4); the RDA task
> is not watched.
>

## 6.4 From shaft angle to megahertz

From the shaft's angle to the frequency shown, with the outage path.

**1. Read.** Every 20 ms the firmware reads the 12-bit raw angle from the AS5600, a magnetic angle
sensor on the tuning capacitor's shaft, at I2C address 0x36 on the main board's first I2C bus. I2C is
the two-wire bus the main board uses to talk to its sensors. The firmware runs this one at 100 kHz,
not 400 kHz: slower edges radiate less, and a hand-turned knob needs no speed. The difference from
the previous read is wrapped to ±2048 counts and added to the **accumulated count**, which carries on
across shaft turns.

The firmware only ever *reads* the sensor: the raw angle, its status, its automatic gain (AGC) and the
magnetic field strength. It writes none of its configuration and never touches its one-time
programmable range, which can be burned once only, ever. The sensor runs at its power-on settings, and
all scaling is done in firmware. The full 4096 counts per turn are plenty: the tuner's roughly 2200
counts across 20 MHz are about 10 kHz per count, against channels 200 kHz apart. The status is kept as
three separate facts (magnet detected, too weak, too strong) beside the gain and the field strength.
That is because "no magnet" covers three conditions that need different fixes.

**2. Which turn.** The AS5600 knows the angle within one turn only. At start-up, and after an outage,
the firmware must choose the turn:

- If **both tuner ends were measured**, and the span between them plus 300 counts on each side is
  narrower than one turn, exactly one turn puts the angle inside that window. That turn is taken,
  whatever moved meanwhile.
- **Otherwise** (ends not measured, the window a whole turn or wider, or the angle outside it) the
  turn nearest a reference is taken: the saved `lastAngle` at start-up, the last count after an
  outage. That is right for any movement under half a turn.

The main loop saves the live count as `lastAngle` every 10 seconds, only when it changed and only
while the sensor answers. A placeholder count from before the first good read is never saved. At
start-up the measured tuner ends are loaded before the first reading is placed on its turn, so the
ends can choose the turn (chapter 4 gives the whole start-up order).

On this tuner the whole travel lies inside one shaft turn: about 2200 counts (2197 measured), some
190 degrees. The firmware relies on that and on the ends repeating within 300 counts; it checks the
first at run time, and a measured span too wide for one turn falls back to the nearest turn.

**3. Outages.** When a read fails, the sensor is left alone for 2 seconds before the next try, the
outage counter goes up once, and the sensor is reported down (`i2c` 0 in the portal's state). While
it is down, the count is frozen and the needle holds its last target. On the first good read the
angle is **re-seated** on a turn by the rule above, never simply added across the gap. A movement
hidden by the outage counts as tuning, and the console prints how far the shaft moved. The sensor is
reported up again only after the re-seat. Chapter 2, section 2.2 says what each surface does
meanwhile.

**4. "The knob is being turned."** The firmware treats the knob as being turned for 400 ms after the
last detected movement. A movement is detected when changes in the same direction add up to 12 counts
(the deadband). A reversal resets the sum, so sensor jitter never trips it, and a slow turn still
counts. This drives the tuning readout on the clock digits and every "knob still" timer. Those timers
include the 3-second wait before a needle re-index (chapter 5) and the 8 seconds before an automatic
measurement.

**5. The curve.** The count is clamped to the range the curve was fitted over (its **domain**), the
curve is evaluated in tenths of a MHz, and the **hand offset** (the dial correction) is added. A
curve value that is not a number, or lies outside 10 to 300 MHz before the offset is added, gives
88.1 MHz plus the offset instead. One version of the result is rounded to the nearest tenth, another
is not; the table below says which surface shows which.

**6. Who uses which count.** The needle follows a filtered copy of the angle (chapter 5). The
measurements, the readouts and the movement detector all use the raw accumulated count.

**Where the frequency is shown.**

| Surface | What it shows |
|---|---|
| Clock digits, `showTuning` = 1 ("Tuning always") | The frequency rounded to the nearest tenth, held inside `dialLow` … `dialHigh`. Shown whatever the amplifier and source. The panel has no decimal point: `1017` means 101.7 MHz. |
| Clock digits, `showTuning` = 2 ("Tuning while tuning") | Only while the amplifier is on and the source is RADIO, and for `tuneHoldMs` after the last movement. The unrounded frequency, held inside the printed face, then snapped to the nearest odd tenth (87.9, 88.1, … the grid of FM channels in the Americas), never off the face. |
| Portal **Now** | The frequency to a tenth, **not** held inside the face; "(past the printed face)" is added outside `dialLow` … `dialHigh`. Shown whenever the angle sensor answers. |
| Portal Needle tab | *last measurement* (the last outcome sentence, or "measuring N % ..."), *tuning curve* (how many samples, the model, the hand offset), *tuner reaches* (the curve's frequencies at the two ends of its domain). |

Chapter 4 describes the clock readout's modes in full.

## 6.5 The calibration curve

The curve is fitted through **samples**: pairs of (shaft count, frequency in tenths of a MHz). There
are twelve slots. **Slots 0 to 2 are the hand marks A, B and C**; **slots 3 to 11 are RDA samples**.
The fit treats them alike. Every change to any setting refits the curve, so a stored sample and the
running curve can never disagree.

| Samples | Curve |
|---|---|
| Fewer than 2 | The **stored straight line**: from `bandLow` (88.1 MHz) at `calLow` to `bandHigh` (107.9 MHz) at `calHigh`. |
| 2 | A least-squares straight line. |
| 3 or more | A **quadratic** (a gentle curve), accepted only if its slope has the same sign at both ends of the domain: a tuner never turns back. Otherwise, or if the samples are degenerate, a least-squares straight line. |

**Least squares** means the curve that makes the sum of the squared errors at the samples as small as
possible.

**The domain.** If both tuner ends are measured, the domain is exactly `calLow` … `calHigh`, widened
only to include a sample outside it. If not, it is the samples' own span padded by 30 % on each side
(at least 100 counts), and the curve's description says "tuner ends NOT measured". Until the ends are
measured, `calLow` and `calHigh` hold the placeholders 0 and 6023, which mean "not measured".

**Guards.** At both ends of the domain the curve, without the hand offset, must lie between 50.0 and
200.0 MHz, and the two ends must be at least 2.0 MHz apart. If either test fails, the stored straight
line is installed instead.

**The tuning sentence.** The model actually running is recorded, never guessed from the number of
samples. One sentence describes it, "N marks, MODEL, reaches X - Y MHz", and the console, the portal's
card and every tuning message print that same sentence. These words in it mean something is wrong:

| Words in the sentence | Meaning | What you do |
|---|---|---|
| "QUADRATIC REFUSED: turns back on itself" | The quadratic would reverse inside the tuner's travel; a straight line is running. | Find the bad sample (console `s` residuals) and drop it. |
| "the marks are degenerate" | The samples cannot define a quadratic; a straight line is running. | Drop the bad sample. |
| "MARKS REFUSED (...)" | The fit failed a guard; the stored straight line is running. The portal's message is red. | Re-mark or drop the bad sample. |
| "tuner ends NOT measured" | The domain is a guess padded around the samples. | Press **Tuner = low end** and **Tuner = high end** (section 6.10). |

Typing `calLow` or `calHigh` into its portal row returns the sentence as a warning when something is
wrong (the fit refused or demoted, or a tuner end not measured). A single field edit can demote the
curve and throw marks away, and the answer says so instead of a plain "ok".

> **Caution — the reach can reassure falsely.** The stored straight line always reports the most
> reassuring reach, 88.1 to 107.9 MHz. Read the model in the sentence, not the reach, to know whether
> your samples are in use.

## 6.6 The RDA5807M as an instrument

The RDA5807M is a single-chip FM receiver. Here it plays no sound: it is a measuring instrument. It
sits on the main board's **second** I2C bus, which the firmware runs at 100 kHz, and answers at
address 0x11; the firmware addresses it there only. The chip, its supply and its antenna are in the
Hardware Bible, chapter 8, section 8.5.

> **For firmware changes**
>
>
> **Set-up.** At start-up and at every re-probe the firmware resets and enables the chip, then writes:
>
> | Setting | Value | Why |
> |---|---|---|
> | Register 0x02 | DHIZ, DMUTE, NEW_METHOD, ENABLE | NEW_METHOD is a sensitivity mode of the chip; the bench test ran with it. |
> | **MONO** (in 0x02) | cleared | The stereo indicator needs the stereo decoder running. |
> | **AFC** (automatic frequency control), register 0x04 | **off** | AFC would let the chip slide toward a louder neighbour and report its frequency. |
> | Band, register 0x03 | band 2, 76 to 108 MHz, 100 kHz spacing | The LO window starts at 77.2 MHz, below the ordinary 87–108 band. |
> | Low-noise amplifier, register 0x05 | both input ports, 2.7 mA | The chip's most sensitive settings. The bench test used the defaults (1.8 mA, one port) and still read the LO at 59 against a floor of 44, but inside the cabinet that margin might not survive, and these cost nothing. Both ports work whichever way the module's antenna pad is routed. |
> | Volume, register 0x05 | 0 | An instrument, not a radio. |
>

The chip is set up at start-up and at every re-probe. Every one of these set-up writes must succeed, and a final read of register 0x0A must answer, or the chip is
reported absent. A **re-probe** runs the whole set-up again, not just a check for an answer: a chip that
came back may have browned out and reset to its power-on defaults, AFC on among them.

**One point.** The firmware tunes the chip to a channel, on the 100 kHz grid (channel = tenths of a MHz
− 760) or the 50 kHz grid (channel = twentieths − 1520), waits up to 60 ms for the chip's "tune
complete" flag (STC, register 0x0A bit 14), then waits **300 ms**, the **dwell**, whatever the
caller asked. The RSSI reading needs about 300 ms to settle after a tune: on the bench a 40 ms dwell
hid the oscillator completely. Then it reads the RSSI and the stereo flag. The stereo flag is read only
after the tune has completed, because its power-on value is 1 and an early read says "stereo" for
everything. A failed read is a failure: never a zero, and never "mono".

**A sweep** is a run of points 100 kHz apart, each kept as a **bin**. It is clamped to the **LO
window, 77.2 to 97.2 MHz**, a compiled range. A sweep is refused if one is already running or asked
for, if the chip is absent and a re-probe fails, or if nothing is left after the clamp. A failed point
is recorded as RSSI 0 and counted. At the end, the sweep's floor is the median of all its bins.

| Sweep | Points | Time |
|---|---|---|
| Narrow, ±1.5 MHz around a prediction | 31 | about 10 s |
| The whole window | 201 | about 60 to 70 s |
| Fine pass, ±0.25 MHz in 50 kHz steps | 11 | about 3.5 s |

**The candidate.** Over the last sweep's bins, skipping any bin within ±0.2 MHz of a fixed feature
and any bin whose stereo flag is set **above the floor + 3**, the firmware picks the bin with the
**largest margin** over its local floor. The local floor uses up to 8 bins each side.

**The fine pass** pins the candidate down: eleven points 50 kHz apart, ±0.25 MHz around it. It skips
any point within ±0.2 MHz of a fixed feature, and any point whose stereo flag is set above the last
sweep's floor + 3. It keeps the **highest** reading: the coarse sweep has already decided this is the
oscillator, and a local floor over eleven neighbouring points would measure the peak against itself.
If every point was skipped or read 0, the pass found nothing. The fine pass is not clamped to the LO
window (only its centre must be inside it), so it can reach 0.25 MHz past either end. Sweeps and fine
passes share one request slot, so only one run is ever in progress.

**Both halves stay readable.** The coarse bins and the fine pass's eleven points stay readable until
the **next sweep** starts; only a sweep clears them. In the fine list, a point skipped as a fixed
feature, or whose read failed, shows RSSI 0; a point skipped as a broadcast keeps the RSSI it read. A
fine pass that loses the chip keeps no points.

**Losing the chip.** Five failed points in a row end the run. The chip is marked **lost**, and the run
publishes nothing (no bins, floor 0). A re-probe tries the chip again at most once every 10 seconds,
never while a run holds the bus, and runs the whole set-up if it answers. Every sweep request, fine
pass request, measurement start and automatic trigger calls the re-probe. The firmware also counts
every failed transfer of the last run, in a row or not.

**Fixed features.** The list lives in the settings, up to 16 entries, empty by default. The RDA task
holds a copy, refreshed whenever settings change. It is learned by hand with the console key `o`,
which marks the current best candidate of the last sweep as a fixed feature and saves the list. Do it
with the set powered but switched **off**: the mains cord in, so both boards and the RDA5807M run, and
the front switch off. The tube set runs only while the amplifier does, so its oscillator is then not
running, and every peak is a spur (section 6.10, step 2). The console `O` or the portal's **Forget the fixed features** clears the list,
and the clear is saved too. At start-up a stored list longer than 16, or with any entry outside 77.2 to
97.2 MHz, is cleared whole.
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

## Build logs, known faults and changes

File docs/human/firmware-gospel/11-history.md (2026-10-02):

# 11. History and bench tests

The firmware was written in about a month, and many of its rules come from what went wrong along the
way. This chapter says how it came to be and what each release changed. It also says what the bench tests
proved; most of them ran before the firmware was written. Several design choices in chapters 3 to 10 rest
on those results, so this is where to look when a choice seems strange.

## 11.1 How the firmware came to be

The work falls into nine eras. The firmware's own history starts on 1 September 2026; the first era comes
from the project's notes. The last column is what each era left in the firmware: a rule it still follows,
or the part of the code it produced.

| Era | When (2026) | What happened | What it left in the firmware |
|---|---|---|---|
| **0. Bring-up** | 26 to 31 August | Both microcontrollers arrived blank. The toolchain was chosen and pinned (chapter 3, section 3.3). The bench tests of section 11.3 ran, phases A to G. A motion test rig settled the needle's motion (chapter 5). The needle was redesigned around a single index sensor, with no end-stop switches. Then the firmware was written in three steps: the link between the boards (framed, checksummed, with a self-test that corrupts a byte on purpose); the audio board's sound engine; the main board's core, with versioned, migrated settings. Last came the portal: one compressed page, settings generated from one table, user roles, salted password hashes, sessions held in memory, a back-off after failed sign-ins, the rescue access point, network time setting the battery clock, and updates over the air for both boards. Once the audio board could be updated through the main board, the cabinet no longer had to be opened. Two bugs were found on the hardware: the display showed `88:88` at brightness 255, and the battery clock's "oscillator stopped" flag was sticky. | **Check what a configuration call returns:** a PWM set-up call had silently refused 11 bits. **Never starve the idle task:** the main board boot-looped. **Give every homing phase its own step budget.** **Keep flash writes away from motion:** a flash write stalls everything that is not in IRAM (the internal memory code can run from without the cache). The needle homes once, when the main board starts; after that the front switch homes it again only if it has no zero, as after a FAULT. The Bluetooth library gets an output with no route to the audio interface, because its sample-rate call reconfigured the I2S driver (chapter 10, section 10.3.3). The oscillator-stopped flag stays set until the time is written, which is how the firmware uses it (chapter 9, section 9.9). |
| **1. The first pop hunt** | 1 September | The machine popped, and the repository was created to track the investigation. A diagnostic isolated data activity at the audio word boundary. An ADC clock toggle was retired. The audio board learned to sleep while the amplifier is off. Seven defects were fixed, three of them regressions from that sleep rule. The portal's jog was bounded, and a reboot no longer lands on top of unsaved settings. | The awake rule (chapter 9, section 9.4). The main board's wait for the audio board's answer to the start of an update went from 5 s to 20 s (chapter 3, section 3.17), and an upload watchdog was added. **An update that reboots cannot report its own success** (chapter 3). |
| **2. The needle's root cause** | 2 and 3 September | Two-point dial calibration. The high soft limit could not be set, and a bus stumble had eaten a revolution. **The root cause:** the index calibration was measured and then thrown away while its frame shift was kept, so every soft limit was about 640 half-steps wrong. Two earlier fixes turned out to be destructive together, and a jog that landed on the index invented a slip. | Homing step budgets as constants based on the measured band; corrupt values purged at load; provisional limits. The unguarded end-stop calibration removed, as a hazard behind a button (the keys `g` and `G` now only say so). Sampling lag at an index crossing no longer counted as a slip. No password in the image: a placeholder account with a forced change (chapter 8, section 8.6.3). The settings save at an update fixed. |
| **3. The dial calibrates itself** | 4 to 7 September | The dial is a curve, not a line: a two-point line was exact at its marks and about 0.5 MHz out mid-band, and the straight line over the tuner's travel 1.4 MHz out at the bottom. Bench Phase H showed that the tube set's oscillator can be heard and read (chapter 6). The RDA5807M, an FM receiver chip used as an instrument, then measured the dial; the curve became quadratic, and it predicted a position it was never fitted to (98.5 MHz). AFC was switched off during measurements, a stereo-pilot rejector and a 50 kHz fine pass were added, and the radio learned to keep calibrating while it is listened to. WiFi was held at 2.0 dBm, because at the time nothing could hear the board at any higher power. | The self-calibration of chapter 6. A curve is proved only at a position it was not fitted to (chapter 6, section 6.10). |
| **4. The needle watches itself** | 8 to 10 September | A self-recovery ladder: small errors absorbed at each index crossing, a larger one re-indexed once tuning stops, three failures give FAULT. The needle had been chasing a rounding boundary while its status said "stationary"; this was found by watching the stepper driver's LEDs, not by reading the code. A hunting detector followed. | **A needle that knows it has slipped must not run on, wildly inaccurate, and do nothing about it.** **Every failure must be visible in the machine's own telemetry, at a resolution that would show it:** the status could not show the hunting, because both positions rounded to the same published value. |
| **5. The second pop hunt** | 10 to 12 September | The pops came back. An objective counter (a microphone on USB, one-minute A/B windows, 30 windows) showed that driving the audio board's clock pads at full strength, **drive 3**, took the rate from 3.33 pops a minute to none in the 932 s measured with it. The same measurement excluded the DAC's clock-error mute. The root cause is still open. Pop-hunt telemetry reached the portal; a diagnostic message was retired after it sent the radio to full volume. The audio board's fade wait before an update went from 250 to 400 ms. The rescue access point became reachable and checkable. | Drive 3 as the start-up default (Appendix H, sections H.4 and H.5). The audio buffers stay at 8, because 32 KB more would exceed the roughly 24 KB really free on the audio board (chapter 10, section 10.8). The method for counting pops (Appendix H, section H.8). |
| **6. A hardware freeze** | 13 to 21 September | Hardware and firmware changes paused while the hardware record was completed. The one firmware change of substance brought the pin file's comments and unused definitions in line with the hardware, without changing behaviour. | No behaviour. The unpublished display-timing bench program stopped building, because two pin names it used were removed (section 11.4). |
| **7. The IF as a setting, the console in the portal** | 22 and 23 September | The master clock and the frame clocks can be driven at different strengths, for a pop test that has never been run. The tube set's IF (intermediate frequency) became a setting, 10.6 MHz; the RDA5807M's readings that day, about 10.60 MHz over six stations, agree. Four stale things that told the reader something untrue were removed. | The web console: everything the main board prints goes into a 16 KB ring the portal can read and type into, so no cable and no second ground connection to a PC are needed (chapter 8, section 8.9). A real index debounce: four polls, back-dated so it adds no position bias. The zero handed to the stepper cannot be lost, and is applied before anything uses it. Hand marks belong to the user alone. The audio board measures RMS level. The compiled audio gains are the measured ones. |
| **8. The transmitter and the needle's speed** | 24 September | Six fixes from what was seen on the machine. A forced access point lives long enough to be seen. A transmit power loaded from a settings file reaches the radio. The transmit ceiling became 15 dBm: nothing could see the board at 20 dBm, everything could at 15 (chapter 8, section 8.4). The up leg dropped to 1100 half-steps/s: at 1500 the needle stalled every time it moved up through the index, at 1200 to 1400 often, at 1100 never, and the stalls had left power-up sweeps about 400 half-steps low. The band check's margin grows with speed. The needle follows a filtered angle reading, so sensor noise no longer moves it. | **Where the bench rig and the machine differ, the machine decides** (chapter 5, sections 5.6 and 5.20). |

Release v.1.0 followed on 25 September.

## 11.2 Release notes

All six releases were made between 25 and 27 September 2026. The boards are updated separately, so their
numbers need not match. This book describes the main board at **v.1.0.5** and the audio board at
**v.1.0.4**.

| Release | Boards | What changed |
|---|---|---|
| **v.1.0** | both | The main board gets the audio board's recovery: an image sent over the air boots **on trial** and is confirmed after about a minute of running with its network and portal up; a hang or crash before that rolls it back; a main-board upload sent during the trial is refused (HTTP 409); a 15 s task watchdog watches the main loop and the needle supervisor; a failed link self-test no longer halts the main board. An audio-board build whose link self-test failed is never confirmed. Every build names its commit beside its version, in the console banner, the portal, the settings file and the audio board's boot report (chapter 3, sections 3.4 and 3.11). |
| **v.1.0.1** | main | A needle with no zero is homed, not re-indexed. Nothing is saved while a main-board image is on trial: changes wait in memory until it is confirmed; **Save** says why it is held; a portal reboot during the trial goes through at once and brings the previous firmware back (chapter 3, section 3.11.5). |
| **v.1.0.2** | both | The audio board counts a save only when it reached flash, and retries a failure. When the audio board goes silent the main board forgets its copy of the audio settings: audio edits get HTTP 409 and a settings download writes `n/a` for them. Boards running different protocol versions show it: `wrong-version` in the console's `s`, a portal pill, the state field `linkver`. The battery clock's health reaches the portal (`rtc`, two pills). `W` claims to have set the battery clock only when the audio board answers. The RDA5807M keeps the coarse sweep's points after a refinement and the fine pass's 11 points (console `a`, `/api/rda` field `fine`). The hand correction of the dial is never erased automatically; **Reset the dial correction to 0** is the only way. Removed: the `autoConnect` portal row, which did nothing; the console keys comma (`,`) and full stop (`.`); the learned transmit power from the settings file. Old files that carry those keys still upload. Every comment was checked against the code, and about twenty false console and portal messages were fixed. Console `D` prints the IF. |
| **v.1.0.3** | both | When every automatic sample slot is full, the most crowded automatic sample makes room for a new dial position; if the new point would itself be the most crowded, nothing is stored ("would add the least coverage"). Hand marks are never replaced. Before, a full table refused every new position. The audio board's console key `y` and the setter behind it, for the data-line output delay, are removed, because one of its positions sent the radio to full volume (chapter 10, section 10.15.3); the read-back stays. |
| **v.1.0.4** | audio | The audio board saves nothing while its image is on trial. Changes wait in memory and are written the moment it is confirmed, with the console line `settings changed during the trial are now saved` (chapter 7, section 7.4.2). |
| **v.1.0.5** | main | The rescue access point `Ambersong` is an **open network**, with no WiFi password, so a person trying to make the radio work again need not find and type a passphrase. While it is up, a DNS server answers every name with the radio's address, so a phone that joins opens the sign-in page by itself (a captive portal). The DNS server stops with the access point (chapter 8, sections 8.3.2 and 8.3.3; the cost of an open network is in section 8.6.7). |

Two rules came with v.1.0.2 and still hold: **a comment that is false serves no purpose**, and **a hand
correction of the dial is never erased automatically, only by hand.**

## 11.3 What the bench tests proved

Each part of the machine was tested on its own, with one small program per test and one source file
per program. A failure was therefore isolated by construction. The phases ran in order, and a
phase did not start until the one before had fully passed. Phases A to G ran before the firmware was
written; Phase H ran a few days after it. The programs are not published and are not
needed to build or run the firmware; this section records what each one proved. Where a result is about
the hardware itself, the Hardware Bible holds it.

| Phase | What it tested | Result | What it left in the firmware |
|---|---|---|---|
| **A** | The 5 V side, with a meter, before any firmware | Passed (Hardware Bible, chapter 5). | — |
| **B1**, main board | The build's memory settings | 16 MB of flash, and 8 386 295 bytes (8.00 MB) of PSRAM seen by the firmware; stable; the heap flat (Hardware Bible, chapter 4). | — |
| **B1**, audio board | Its identity | No PSRAM, which frees the pins the DAC needs (Hardware Bible, chapter 4). | — |
| **B2** | The battery clock's I2C bus | Passed, after a pin-map correction found by measuring. The clock's "oscillator stopped" flag read as set, and was reported, never cleared. | — |
| **B3** | The angle sensor's I2C bus and its magnet | Passed. Repeatable to ±1 count (0.08°), both over a full sweep out and back and on returning to a marked position. | — |
| **B4** | The link between the boards, both directions at once | 14 round trips of 14, none lost, 1 to 2 ms each. | — |
| **C5 to C7** | The panel inputs and the amplifier sense | Passed, after wiring corrections (Hardware Bible). | — |
| **D** | The clock display | Passed (Hardware Bible, chapter 7). | — |
| **E** | The needle drive, end to end | Passed. The first run moved the needle the opposite way to "forward"; the fix inverted the phase advance, so there is one definition of forward. | **One definition of forward**, shared by the motion, the checks and the messages. **The safety pattern:** check before every step, refuse a direction whose limit is reached, release the coils when idle (chapter 5). |
| **F** | The whole audio path | F1 DAC playback, F4 ADC capture and F5 radio end to end passed. F2: muting works in software, by writing digital zeros. F3: the audio board receives Bluetooth audio (A2DP) and plays it. F5 measured the radio at −53.2 dBFS RMS at the author's reduced volume, about 33 dB below plan. | **Mute by digital zeros**, ever since. **Two boards**, because the main board's chip has no Bluetooth Classic (chapter 2, section 2.3), and the pinned toolchain (chapter 3, section 3.3). **The gain staging** (chapter 10, section 10.5.6), which began with F5's shortfall. |
| **G** | Whether a web portal can share the main board with the multiplexed display | A timer interrupt in IRAM drove the digits and timed every slot. WiFi plus four concurrent multi-megabyte web downloads: imperceptible. The same plus stepper motion: imperceptible. Deliberate thrashing of the flash bus: the only visible disturbance, still bearable. Cleared. | **Display and stepper on core 1, WiFi and the web server on core 0. The display interrupt stays in IRAM. Settings writes are debounced. The display is parked during a main-board update** (chapter 4, sections 4.3, 4.8 and 4.14). |
| **H** | Whether the dial can be read off the tube set's oscillator | Yes. Chapter 6, section 6.13, has the three answers and the lessons. | See below. |

**Phase H** belongs to the tuning chapter (chapter 6, section 6.13). Its main lesson, in short, follows.
Phase H showed the oscillator cannot be told by loudness: a fixed spur at 79.0 MHz was louder at every dial
position, and only moving the dial told them apart. The firmware uses that lesson by learning what does
not move (the fixed features, with the set off) and masking it; it does not itself check that a peak
moves between two sweeps. It also showed that the injection is low-side (the oscillator runs one IF below the station), which
the Hardware Bible records.

**The motion rig**, a bare stepper motor and driver on a spare ESP32 with no needle, settled the needle's
motion before any of it went into the firmware, and found four motion bugs of the same shape as the
firmware's. Its findings, and how to build a new rig, are in chapter 5 (sections 5.6 and 5.23.4). The rig
is retired. Its numbers were a starting point, not a standard: the firmware's own defaults (Appendix A)
are the rule.

## 11.4 Tools that ship

Only two tools ship with the firmware, both build scripts that run before every compile (chapter 3,
section 3.4). They matter only to someone building or changing the firmware.

> **For firmware changes**
>
> | Script | What it does |
> |---|---|
> | `scripts/page.py` | Checks the portal page's script, compresses the page and embeds it in the main board's build. |
> | `scripts/version.py` | Stamps every build of both boards with its version and its commit. |

**Not published:** the bench programs and test rigs of section 11.3, and the pop hunt's recordings and
analysis scripts, which no longer exist (Appendix H). The display-timing program of Phase G no longer
compiles, because it used two pin names (`S3_LIMIT_LEFT`, `S3_LIMIT_RIGHT`) removed from the firmware's
pin file during the hardware freeze. Anyone who needs such tools again will have to remake them: chapter
5, section 5.23.4, says how to build a motion rig, and Appendix H, section H.8, how to count pops.

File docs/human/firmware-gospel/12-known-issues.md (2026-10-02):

# 12. Known issues, ideas and untested paths

No firmware is finished; this one has a list of things that were seen, understood and left as they are.
Only one of them stops the radio from working: an audio-board program built with the wrong protocol
version (section 12.5). Each is written down so that whoever meets it does not have to
rediscover it, and so that whoever wants to fix it knows where to start.

The chapter opens with an index: find what you see, and it sends you to the section that explains it,
in this chapter or another. Then come the issues left as they are, grouped by area, one row each: what
you see, why it was left, and where a fix would start. The "where a fix starts" column names functions
and files; only someone changing the firmware needs it. A starting point is a suggestion, not a design;
none has been tried.

The class in the last column is the recovery ladder of *About this book*:

- **NOTE** heals by itself or is only cosmetic.
- **DEFECT** needs a portal reboot, a console reset or the front switch.
- **BLOCKER** leaves the radio unusable through a power cycle, or reachable only by the USB cable.

Two issues here are BLOCKERs: that program (section 12.5) and, at worst, a blank board's access point,
if nothing but the USB console helps (section 12.4). The chapter ends with ideas for improvement, the
paths never exercised on the radio with a way to test each, and a tidy list for the code.

Everything here was checked against the main board's firmware v.1.0.5 and the audio board's v.1.0.4. The
placeholder portal account, the open rescue access point and the author's time zone are not faults but
things a builder sets: see the builder checklist, chapter 8, section 8.2.1.

## 12.1 Index by symptom

Find what you see; the second column gives the section that explains it (5.19 is chapter 5, section
5.19; Appendix H is the pop hunt).

| What you see | Where |
|---|---|
| **The needle** | |
| **NEEDLE OFF**, **NEEDLE RE-INDEXING**, **NEEDLE FAULT**, **NEEDLE HUNTING** | 1.5, 5.19 |
| The needle holds still while you tune | 5.13, 6.12 |
| The needle pinned at one end; the first search at power-up goes up and away; `*** LEDC REFUSED ***` | 5.19 |
| The needle frozen and the clock dark | 4.8, 5.19 |
| **Re-index** answers "re-indexing" but homes; steps lost after raising `upVmax`; no warning for a gain that will hunt | 12.3 |
| A portal jog stutters | 12.4 |
| **Tuning and the dial** | |
| A measurement REFUSED, DISCARDED, ABANDONED or NOTHING FOUND; QUADRATIC or MARKS REFUSED; "tuner ends NOT measured" | 6.12 |
| Every reading off by the same amount; one sample with a large residual in `s` | 6.12 |
| The top of the dial (107.9 MHz) cannot be measured | 6.15, 12.2 |
| Samples stored up to 50 kHz high; the fine-pass list shows a rejected broadcast; a garbled status line or a mixed sweep dump; the gap message names the tuner's ends | 12.2 |
| **Drop one sample** removed a hand mark | 12.4 |
| **The clock and the display** | |
| The clock blank or `--:--`; a battery-clock pill; the old time back after `W` | 1.10, 4.13, 9.10 |
| The clock blank with a working network, the audio board absent since start-up | 12.5 |
| Eastern North American time after `W` | 4.9, 8.2.1 |
| The wrong brightness after `-` or `=`; `0879`; a frequency shown while the angle sensor is dead; 3.3 s before anything starts | 4.16, 12.7 |
| The battery clock wrong from the year 2100 | 12.5 |
| **Sound and Bluetooth** | |
| Pops | 10.10, Appendix H |
| A click at the start of every audio-board update; a click with `stalls` rising; silence while the link and the blue lamp work | 10.11, 12.6 |
| Full volume or silence after a change to the audio interface | 10.11, 10.15.3 |
| Wrong pitch; rare drops; the volume does not follow the knob; a phone dropped; no phone finds the radio | 10.11 |
| "pairing window open", but nothing opens | 12.5 |
| Updates and phones refused (memory) | 10.8, 10.11 |
| Peak or ring readings missing on the portal after the audio board's `s` | 12.6 |
| One pop at every audio-board restart or update | 10.14 |
| **The network, the portal and the console** | |
| Off the house network, `Ambersong` appears; a phone joins but no page opens | 1.4, 8.11 |
| A blank board's access point cannot be joined; the portal slow while the needle moves | 8.11, 12.4 |
| The portal dead but the radio answers a ping; sign-in refused with a wait; the password lost | 8.11 |
| The portal dead while the radio, clock and needle work | 4.13 |
| The Network card's save rejoins; the access point confirmed only on the console; the reboot toast says only "rebooting"; an upload's count hidden; no "unsaved" sign | 12.4 |
| `one key at a time ...`, `console busy`; the display freezes and the sound mutes while a prompt waits | 8.11 |
| `y` shows the password; `i` says `*** LOW ...`; the first `B` gives 11 dBm; `D` cannot be pasted into a file | 12.4 |
| `i` says `OWN ACCESS POINT` while joining; `B`, `o` or `O` say "saved" too early; `q` or `v` refused with no reason | 12.8 |
| **Updates and versions** | |
| An upload refused (wrong chip, on trial, audio board not answering); the page says it failed, but it worked | 3.15 |
| "flash" on the page for a main-board file for the wrong chip; "No Error" after a refusal | 12.4 |
| `- an earlier update was ROLLED BACK` at every start-up; the sound off 20 s after a relay stopped | 3.15, 12.5 |
| `proto self-test FAILED - muted, BT closed, awaiting OTA`; silence and no handshake after an audio-board update | 9.10, 12.5 |
| The audio board's version on no portal page | 12.5 |
| The Firmware card says the needle "parks"; two builds cannot be ordered by stamp | 12.8, 12.7 |
| **Settings** | |
| **SETTINGS LOCKED**; a setting back at its old value after a power cut; the fixed-feature list empty | 1.11, 7.7 |
| Audio settings back at their defaults after an update | 7.7, 10.11 |
| `the audio board is not answering ...` (HTTP 409); `n/a` in a download | 7.7, 9.10 |
| An audio edit lost just before the audio board fell silent; an audio-board console change undone | 12.5 |
| "TUNING MARKS REFUSED - the file announced 0 and 0 parsed", or no word about the marks | 12.4 |
| **The link between the boards** | |
| `[WARN] A32 silent.`; `link SILENT`; **AUDIO BOARD SENDS NO STATE**; asleep for up to 80 s; reset reason 6 | 1.8, 9.10 |
| `[WARN] A32 silent` and the link pill red, yet the sound plays on | 9.10, 12.5 |
| **BOARDS RUN DIFFERENT PROTOCOL VERSIONS - flash both** | 9.10, 12.5 |
| The audio board says `crc ok`, `[PASS] clock pads`, or `[ZDD] DAC left analogue mute`; its help line omits `k` and `g` | 12.8, 12.5 |

## 12.2 Tuning

Issues in the dial calibration and the tuner chip.

| What you see | Why it was left | Where a fix starts | Class |
|---|---|---|---|
| **The top of the dial cannot be measured.** The firmware sweeps the oscillator only between 77.2 and 97.2 MHz. At the default IF of 10.60 MHz, 107.9 MHz needs it at 97.3 MHz, one step outside, so a measurement there finds nothing or only the edge of the peak. Every station up to 107.8 MHz is inside. | The highest station receivable where this radio lives is 107.3 MHz, and the dial reads true up to there. | The range is compiled (`Rda::LO_WINDOW_LO10`, `LO_WINDOW_HI10` in `src/s3/rda.h`), from the old nominal IF of 10.7 MHz. Derive it from the dial's printed ends minus the IF setting. Then the fixed features just above 97.2 MHz (98.7, 101.6 and 104.4 MHz) must be learned like the others, and the start-up purge of out-of-range fixed features (`purgeCorruptSpurs()`) must follow the new range. `requestSweep()` clamps every sweep to the range; `requestRefine()` checks only the centre; `sampleStart()` refuses a position well outside. | NOTE |
| **Readings shared between tasks without a lock.** A status line read mid-rewrite mixes old and new text; a sweep dump (`a`, `/api/rda`) taken during a sweep mixes two sweeps. The fixed-feature list can be replaced while a sweep reads it: never seen; at worst one sweep judges one frequency against the old or the new list. | Cosmetic or theoretical, and a lock would add a new way for the tuner task and the portal to wait on each other. | One small mutex for the tuner task, or copy on write: build the status text and the bins privately, publish them with one index or pointer swap. For the fixed-feature list, make the count and the array `volatile` and publish with an atomic store, as `pushBt()` in `src/a32/audio.cpp` publishes its ring head. | NOTE |
| **The gap message names the tuner's ends** ("AS5600 gap - angle re-seated on the turn inside the tuner's ends") even when the ends are not measured and the nearest turn was used. | Wording only. | Have `seatTurn()` in `src/s3/needle.cpp` report which rule it used, and print "on the nearest turn" when the ends are not measured, or the shaft lies outside them. | NOTE |
| **Samples are stored to 100 kHz.** The fine pass measures in 50 kHz steps, but a sample is stored in tenths of a MHz, rounded up: an odd-twentieth result is stored 50 kHz high (an oscillator at 95.05 or at 95.10 MHz stores 105.7 MHz either way, with the default IF). About +25 kHz on average. | At most half a channel step, and the dial reads true. | Store `tuneF` in twentieths and fit the curve on those: a settings version bump, with a conversion that doubles every stored mark (chapter 7, section 7.5). The rounding is the `station10` line of `sampleStore()`. | NOTE |
| **The fine-pass list does not mark a broadcast.** A point rejected as a broadcast keeps its reading, under the legend "fine pass (50 kHz; 0 = skipped)", and looks like a candidate that lost. The `fine` list in `/api/rda` has the same gap. | The choice itself is right; only the printout is incomplete. | Keep a stereo flag per fine point, as the coarse bins do (`binStereo()`), and print "(STEREO - a broadcast)" after such a point; or complete the legend. | NOTE |
| **The comb's source is unknown.** The tuner chip sees fixed features at multiples of 2.8224 MHz. One suspect, the audio board's I2S clocks, which run even while it sleeps, has never been tested. | The notches work; the comb costs only part of the window (chapter 6, section 6.15). | Add an experiment action, reset at start-up like the others, that stops the I2S peripheral for a set time (about 90 s) and restarts it. Sweep inside that time and compare the `a` list with one taken with the clocks running. I2S is set up in `Audio::begin()` and fed by `audioTask()`. | NOTE |

## 12.3 Needle

Issues in the needle's motion and its portal buttons.

| What you see | Why it was left | Where a fix starts | Class |
|---|---|---|---|
| **A direct write of the position can race a pending correction.** Never seen; a hypothesis from reading the code. The step task owns the position and folds corrections in at the top of every pass, but the index calibration's start and finish, the microstep change, the coil release, the jog, the low-stop assumption and the start-up position still write it directly. A correction landing during such a write would be lost, and the needle would run in a frame off by a few to a few hundred half-steps. | Rare, never seen, and it corrects itself: the next index crossing, the idle check or a re-index finds the error. | Make the step task the only writer: add a "set position to" request that `stepTask()` applies at the top of its pass, next to the fold. Simpler: have each writer wait until `gCorrectHs` reads 0, as `homingTick()` does. The writers are `calFinishBand()`, `calStartBand()`, `useMicro()`, `coilRelease()`, `jogRaw()`, `assumeAtLowStop()` and `bootPosition()`, in `src/s3/needle.cpp`. | DEFECT at most |
| **"Measuring pass speed" says less than it does.** The row (`reapHsps`, default 60 half-steps/s) sets the index calibration's creep **and** the portal's jog. It does not set the homing re-approach, which is not a setting. | Judged not worth changing. | Rename the label, for example "Calibration creep and jog speed". The key stays, so settings files keep working. | NOTE |
| **No warning for a needle gain that will hunt.** The start-up check of `wn` against its ceiling runs before the stored settings are applied, so it only checks the compiled defaults. A stored or portal value above the ceiling is never warned about. | Judged not needed. | Call the same check (`wnCeiling()`) from `applySettings()` after the needle settings are pushed down; print the warning and return it to the portal as a `warn`. | NOTE |
| **The portal's needle buttons run on the portal task** (core 0) and write the needle's state while the needle task runs on core 1; only stop and abort are handed over safely. A jog also holds the portal for its whole length, up to about 20 s at the lowest `reapHsps`; nobody gets an answer meanwhile. | A known cross-core class, deferred: the buttons are used by one person at a time, with the needle at rest. | Turn each action into a request that the needle task picks up at the top of its pass, as `Needle::stop()` already works, and answer the portal from its result. The jog becomes a request that returns at once. | DEFECT at most; the jog's hold is a NOTE |
| **Re-index answers "re-indexing" when it homes.** On a needle with no zero it runs a plain home. Its refusal always says "a calibration or a bring-up tool has the needle", also when the needle is homing or sweeping. | Not yet addressed; the console says what really happened. | Have `startReindex()` return a reason string, as `startHoming()` does, and a flag saying it homed; then answer "homing - there is no zero to re-index from". | NOTE |
| **`upVmax` accepts speeds that stall the needle:** up to 4000 half-steps/s, while this needle stalls through the index far below that. | Not yet addressed. The default, 1100, is the measured limit of this mechanism. | Lower the row's maximum to the measured stall speed (chapter 5, section 5.18), and note that another mechanism needs its own ceiling. | DEFECT at most: the crossing check finds the lost steps and re-indexes |

## 12.4 Settings, portal and console

Issues in the stored settings, the web portal, the network and the main board's console.

| What you see | Why it was left | Where a fix starts | Class |
|---|---|---|---|
| **`i` calls normal powers "LOW".** It adds `*** LOW - the transmitter is turned down ***` to any value under 10 dBm, but the ladder's rungs 8, 20, 28 and 34 (quarter-dBm) are normal. | A bench line; its comment already says to check the value against the rung. | In `Net::driverReport()`, compare the driver's value with the rung asked for; flag only a difference, or a zero. | NOTE |
| **The first `B` after a start-up gives 11 dBm.** `B` keeps its own place in its list from start-up, so its first press always sets 44 (11 dBm), whatever the radio was running at, and saves it. | A bench key; the printout shows the new value. | Start from the rung in force (`cfg.wifiTxQ`) and step to the next lower entry. | NOTE: a later press, or the ladder, changes it again |
| **The portal is starved while the needle moves.** The step task runs at high priority on core 0 and does not yield during a move. The portal shares that core. An audio-board update is relayed by the portal task: the likely cause of four failed audio-board updates on one early day. | Accepted: the step timing comes first, and the portal is not needed while tuning. | Keep the needle at rest during an audio-board update (the workaround in use). For a fix, emit steps from a hardware timer or the RMT peripheral so the step task can sleep between steps, and measure the step jitter before and after. | NOTE: it ends when the needle stops |
| **A settings write can land while the needle moves.** "Still" is judged by the needle's speed, which reads 0 in the pause before a move and during a portal jog, so a write can land then and make the jog stutter. The forced save also retries up to 40 times without asking again. | Not yet addressed; the stutter is brief and the step task catches up. | Judge "still" by the needle's state (no move, no dwell, no jog), not its speed, and call `writeSafe()` again before each retry. | NOTE |
| **No lock around the settings across the two cores.** Known races, each of microseconds: a hand mark and an automatic sample at the same instant; an upload half applied when a background save copies the settings, followed by a power cut within about 2 s; a soft-limit edit crossing an apply. None seen. | The risk was accepted rather than rebuild the settings around a lock (chapter 7, section 7.11.2). | One mutex held by every writer of `cfg` and by the copy in `settingsWrite()`; or post every portal change to the main loop as a request, so only one core ever writes. | NOTE |
| **No "unsaved" sign on the page**, for example during the trial minute after an update, when nothing is saved. The page shows only the lock. | Not yet addressed. | Add an `unsaved` field to the state the page polls, and a pill "CHANGES NOT SAVED YET" naming the reason the firmware already keeps for the **Save** button. | NOTE |
| **A settings upload with a warning hides the count:** the page shows the warning, not "N settings applied". | Not yet addressed. | Show both: the count, then the warning. | NOTE |
| **An unreadable `tuneUsed` line.** It is skipped with no note, and so is every mark line after it; the stored marks are kept. In a downloaded file the page then says "TUNING MARKS REFUSED - the file announced 0 and 0 parsed; the stored calibration was kept", which is misleading. In a file with no `tuneOffset10` line, nothing is said. | Not yet addressed; nothing stored is lost. | Remember that a `tuneUsed` line was seen but unreadable, as the hand-offset line already does (`mkOffBad`), and refuse the block in its own words: "the tuneUsed line could not be read - the file's samples were not applied". | NOTE |
| **The dump `D` is only partly a settings file.** Its first lines carry several pairs each, which an upload refuses; only its tuning, IF (`ifOffset=`) and fixed-feature lines paste as they are, and its `wifiTxQ` line is ignored. | A bench view; the portal's **Download** is the settings file. | Print one pair per line, or the same text as the download. | NOTE |
| **Reboot the main board shows only "rebooting".** On trial the radio answers "rebooting - this firmware was still on trial, so the previous firmware comes back", and the page drops that sentence. A refusal is shown in full. | Not yet addressed. | In the page's `#rb` handler: `toast(r.m \|\| 'rebooting')`. | NOTE |
| **Two main-board update messages.** An upload refused during the trial also prints the updater's "No Error" on the console. An upload refused for the wrong chip gives its reason on the console only; the page shows "flash". | Not yet addressed; both refusals work. | Skip `Update.end()` when the upload was refused or never began. Keep a reason string for the main board's own image, as the relay does with `a32OtaSetError()`, and send it from `hOtaEnd()`. | NOTE |
| **Saving the Network card always rejoins**, 3 s later, even for an NTP server or time-zone change alone, because the card always sends the network name. | Not yet addressed; the rejoin takes a few seconds. | Have `Net::setWifi()` skip the rejoin when the name and passphrase are unchanged, or send them only when they changed. | NOTE |
| **A portal-raised access point is confirmed on the console only.** | The console is readable on the **Console** tab. | Carry the access point's state in the page's state, so a browser that joins it sees a pill. | NOTE |
| **A blank board's access point transmits at 2 dBm.** The ladder moves only on failed joins, and a board with no network has none. On this machine an access point at 2.0 dBm was visible at 44 % but could not be joined; on another board it may be fine at close range, untested. | On this machine the rung was learned long ago. | Raise the access point at a fixed rung known to be joinable (15 dBm here), or step the ladder while the access point is up and nobody has joined. | NOTE when moving closer works; BLOCKER only if nothing but the USB console helps. A blank board has just been flashed by USB, and `y` sets the network over the same cable |
| **`y` echoes the WiFi password**, onto USB and into the console ring, which any administrator with the **Console** tab open can read. | Accepted for this machine; a builder may judge otherwise. | In `setWifiInteractive()`, echo the network name, then a `*` for each character after the space. | NOTE |
| **Drop one sample also drops hand marks.** It accepts slots 0 to 2, the hand marks A, B and C. | It is the only way to remove one hand mark without clearing them all, so it may be wanted; the label is what is loose. | Relabel it ("Drop a mark or sample, slot 0-11"), or refuse slots 0 to 2 there and add a separate "Clear mark A/B/C". | NOTE |
| **`sys.quiet` casts its number unchecked.** Nothing in practice: a value of 65 536 or more is undefined in C++; on this compiler 65 536 becomes 0, which turns into the 1 s minimum, and radio silence is capped at 600 s anyway. | Harmless. | Clamp the argument to 0..600 before the cast in `doAction()`. | NOTE |

## 12.5 The link and the audio board

Issues in the link between the boards and in the audio board's own firmware.

| What you see | Why it was left | Where a fix starts | Class |
|---|---|---|---|
| **An audio-board image built with the wrong `PROTO_VERSION` confirms itself** after five minutes, because frames of another version count only as wrong-version and the S3 looks absent. It becomes permanent; the link stays down, with no radio or Bluetooth sound, until the main board matches. The main board shows it (`wrong-version` in `s`, the pill, `linkver`); the audio board counts it but prints it nowhere, and its `s` shows only `link SILENT rx 0`. | By design: it lets a protocol change roll out one board at a time (chapter 9, section 9.14.5). | If it ever bites: count wrong-version frames on the audio board too, and refuse the five-minute path while they arrive, so the image stays on trial and rolls back at the next reset. That removes the one-board-at-a-time path, so the protocol procedure would need another way. | BLOCKER: radio and Bluetooth stay silent through a power cycle once the audio board has confirmed itself. Recovery: update the main board built with the audio board's version, then both together; no cable |
| **No network time without the audio board.** If the audio board is absent or silent from start-up, the main board never takes network time either, because that path writes through to the battery clock and waits for the handshake. The clock stays blank even with a working network. | Accepted: with the audio board down there is no radio or Bluetooth sound either, and the clock comes back with the link. | Let network time set the main board's software clock (`epochAtSync`, `millisAtSync`, `timeValid`) without the handshake, and send the write-through only when the audio board answers. The block is in the main loop, gated on `peerHello`. | NOTE |
| **A one-way link failure leaves the audio board on a stale amplifier state.** If only the audio-board-to-main-board direction fails, the main board hears nothing, drops the handshake and from then on sends only HELLO, once a second. The audio board still receives those HELLOs, so for it the main board is alive: it stays awake on the last amplifier state it was told. The sound plays on, and if the amplifier is switched off it never learns it (Bluetooth stays connectable on the Bluetooth source). Everything recovers by itself when the line works again. Never seen on the radio (chapter 9, section 9.10). | Not yet addressed; it needs a broken wire to happen. | Have the audio board count only `SET_SYS` (not HELLO) as "the main board is talking", or have the main board keep sending `SET_SYS` while it tries to handshake. The sending side is the link keep-alive block of the main board's `loop()` (`SET_SYS` and `PING` go only while handshaken); the waking side is the audio board's `serviceWake()` (awake = amplifier on and the main board alive). | NOTE |
| **`autoConnect` is still in the protocol**, stored by the audio board and read by nothing: the radio never starts a Bluetooth connection itself. Old settings files that carry the key still upload. | Removing the byte changes the structure's size. That needs no new `PROTO_VERSION`: until both boards carry it, each refuses the other's Bluetooth-settings messages and everything else works. But the audio board then resets its stored Bluetooth settings to defaults, and both boards need the update. | Remove it the next time `ProtoBtCfg` has to change anyway, so the reset is paid once. The audio board has no conversion: any size change puts that structure back to its defaults (chapter 7, section 7.5.5). | NOTE |
| **"pairing window open", and nothing opens.** **Pair a new device** (`bt.pair`) sends a message named `MSG_BT_LOOK`, which opens the pairing window (the state `BT_LINK`, not `BT_LOOK`), and only on the Bluetooth source. The portal answers "pairing window open" on any source. | Renaming a message touches both boards and the protocol header. | Rename it (for example `MSG_BT_PAIR`); the value stays, so `PROTO_VERSION` need not change. Have `bt.pair` refuse with "switch to Bluetooth first" when the audio board's reported source is not Bluetooth. | NOTE |
| **The audio board's help line omits `k` and `g`.** Both keys work (Appendix D). | Bench keys, reachable only with a USB cable on the audio board. | Add both to the `keys:` line printed in `setup()`. | NOTE |
| **The audio board's version is on no portal page.** It appears on the main board's console at each handshake (`[PASS] A32 up: ...`) and in the boot report. | Not yet addressed. | Add the audio board's version (and its commit, from the boot report) to the page's state, and show it on the System tab beside the main board's. The value is `gLink.peerVersion`. | NOTE |
| **A relay that fails mid-image sends no abort.** The audio board stays muted until its own 20 s give-up, then restores its sound and keeps its old firmware. A wrong chip, a dropped connection, a stalled upload and a missing final answer do send the abort. | Judged not a problem. | Call `a32OtaAbort()` in `hOtaA32Upload()` the moment `a32OtaChunk()` fails. | NOTE |
| **An audio edit made just before the audio board falls silent is lost.** The refusal starts only once 2 s of silence have cleared the main board's copy; an edit in those 2 s is accepted, sent to nobody, and replaced by the audio board's own settings when it returns. | Not yet addressed; the window is short and needs the audio board to fail at that moment. | Have the audio board acknowledge each settings message, and report the edit as not applied when no acknowledgement arrives. | NOTE: nothing is corrupted |
| **The save before a commanded restart is tried once.** When the main board asks the audio board to restart, the audio board forces a save; if that write fails, it restarts anyway and the change is lost. | Not yet addressed; a failed write has never been seen. | Retry the forced save a few times, and send a log line to the main board before restarting if it still fails. | NOTE |
| **Audio-board console changes are undone.** The volume law (`t`, `T`) and the knob calibration (`p`, `c`, `P`) set on the audio board's console are saved there, but the main board's copy is not refreshed, and the next portal edit of any audio row sends the older volume law back. **Re-read the A32** (`sys.getcfg`) refreshes the copy. | Bench keys, reachable only with a USB cable on the audio board. | Have the audio board send its settings to the main board after any console change, as it answers `MSG_GET_CFG`. | NOTE |
| **A broken audio-board image on trial says the wrong thing.** An image that failed its link self-test announces "proto self-test FAILED - muted, BT closed, awaiting OTA", and at start-up "link and OTA kept up so this build can be replaced". On trial, an update is refused; only a reset, which rolls it back, gets out. The words are true only for an image flashed by USB. | The behaviour (never confirmed, rolled back by the next reset) is accepted; only the words are wrong. | When the image is on trial, announce "reboot the audio board to go back to the previous firmware" instead. | NOTE |
| **The battery clock's temperature is sent and not used.** Every time message carries it; the audio board prints it once, in its own USB banner; the main board never reads it. | Not yet addressed. | Show it in the portal, or drop the field at the next protocol change that has to happen anyway (see `autoConnect` above). | NOTE |
| **The battery clock is wrong from the year 2100.** The audio board reads and writes the year as two digits from 2000 and ignores the chip's century bit. | Not yet addressed. | Read and write the century bit in `Rtc::read()` and `Rtc::write()`, or accept the limit and say so. | NOTE |
| **"ROLLED BACK" stays in every start-up report** of both boards until the next update replaces the invalid image, so an old rollback can look like a new one. | Not yet addressed. | Remember in flash that a rollback was reported and print it only at the first start-up after it; or print the invalid image's version. Both boards use `esp_ota_get_last_invalid_partition()`. | NOTE |

## 12.6 Sound

Issues in the sound path.

| What you see | Why it was left | Where a fix starts | Class |
|---|---|---|---|
| **A click at the start of an audio-board update** when the fade-out is longer than about 340 ms. The audio board mutes, then waits a fixed 400 ms before it writes flash, which stalls the audio task. The wait covers the fade-out, one audio block and the 46.4 ms output buffers. The default fade-out is 150 ms; the portal allows up to 5000 ms. | The default is well inside the wait, and an update is rare. | Make the wait follow the setting, the fade-out plus about 60 ms, staying well under the 20 s the main board waits for the audio board's answer; or cap `fadeOutMs` at 340 ms. The wait is the `delay(400)` in the `MSG_OTA_BEGIN` case of the audio board's `onMessage()`. | NOTE |
| **The stall click.** The audio task is sometimes frozen for 23 to 111 ms, and a click can be heard. The cause was never measured; the leading guess is a flash write, which turns the flash cache off and stalls every task that runs from flash. | A deeper output chain would ride through it, but costs memory the audio board does not have (chapter 10, section 10.8). | Measure first. The stall detector already records each stall's length and time (`stalls`, `stlast`); record the time of every flash write on the audio board beside it. If they line up, keep flash writes away from playing moments, as the main board keeps them away from the moving needle. | NOTE: the sound comes back by itself |
| **Silence while everything else works:** the audio task is not watched by the watchdog. If it wedged, the main loop, the link and the portal would stay alive with no radio or Bluetooth sound, and nothing would restart the audio board. Never happened. | Not yet addressed. | Subscribe the audio task to the watchdog (`esp_task_wdt_add()`) and feed it once per block. The 15 s timeout is far above the longest stall seen. | DEFECT: **Reboot the audio board** fixes it |
| **The audio board's `s` steals the portal's readings.** It reads the peak meter (with its clip flag) and the ring's high-water mark, and reading resets them, so the portal misses them for one period. It also clears the I2S latches, but the portal reads `i2sSticky`, a copy nothing clears. | A bench key, reachable only with a USB cable on the audio board. | Give the console a read that does not reset (a "peek"), and leave the resetting read to the state message. | NOTE |
| **No live figure for the audio board's free memory.** The one figure, about 24 KB, was measured once. `s` prints only `ESP.getFreeHeap()`, which is not what a plain or a DMA allocation can get; the Bluetooth library prints the right figure only at start-up, on USB; the portal's `heap` is the main board's. | Not yet addressed; no fix chosen. | Print `esp_get_free_heap_size()` and `heap_caps_get_largest_free_block(MALLOC_CAP_DMA)` in `s`. Carrying them in `ProtoState` puts them on the portal; a new field goes at the end of the structure (chapter 10, section 10.15). | NOTE |

## 12.7 Main board, clock, display and build

Issues in the main board's start-up, its clock display and the build.

| What you see | Why it was left | Where a fix starts | Class |
|---|---|---|---|
| **About 3.3 s before anything starts.** At every start-up the main board waits up to 3 s for its USB console port to open, then 300 ms more, before the display, the needle and the link start. In the radio no USB host is attached, so every start-up pays it all. | It keeps the start-up report whole when a cable is attached. | Shorten the wait, or start the display and the link first and print the banner when the port opens. The web console's ring already keeps lines for a late reader. | NOTE |
| **Readout mode 1 shows a stale frequency.** With the readout on "Tuning always", the digits show the frequency of the last angle count even when the sensor has stopped answering. Mode 1 is deliberately not gated on the amplifier and the source; the sensor is a separate matter. | Not yet addressed. | When `Needle::i2cOk()` is false, show the placeholder the clock shows when it has no valid time. | NOTE |
| **The frequency readout shows a leading zero** below 100 MHz (`0879` for 87.9 MHz). The clock follows `blankLeadZero`; the readout does not. | Not yet addressed. | Pass `true` for the leading-zero blank in the `Display::showNumber()` call of `updateDisplay()`, or follow `blankLeadZero`. | NOTE |
| **The console's `-` and `=` (or `+`) bypass the fade.** They change `brightOn` by 15 and write it straight to the display, also while the amplifier is off, so the clock can sit at the wrong level until the next amplifier change, or step back briefly before it eases. They also skip the settings table's bounds, though their own floor and ceiling (0 and 255) match today. | Bench keys; the portal's brightness rows take the normal path. | Route both keys through the settings table's setter for `brightOn`, the portal's path, so the bounds and the fade apply. | NOTE |
| **Version stamps cannot always be ordered.** The stamp comes from the build PC's local clock, with no time zone; two builds made in different zones, or across a daylight-saving change, cannot be ordered by stamp alone. | Every build so far was made on one PC. | Stamp in UTC and add a `Z` in `scripts/version.py`. The string must still fit the 24-byte version field of the handshake (chapter 3, section 3.4). | NOTE |

## 12.8 Texts that say something false

These texts tell a reader something that did not happen. None changes what the radio does. All are NOTE.

| Where you read it | What it says | What is true | Fix |
|---|---|---|---|
| The portal's Firmware card | "The needle parks and the display goes dark while an update writes" | The needle stops where it is; a park is a different move. | "The needle stops and the display goes dark". |
| Console `B`, `o`, `O` | "saved" ("known, saved", "the clear is saved") | They only mark the settings changed. The write follows about 2 s later once the needle is still, and never while an image is on trial or the settings are locked. | "will be saved". |
| Console `i` | `OWN ACCESS POINT` and the access point's name whenever the main board is not joined | Also during a join, or radio silence, when no access point is up. | Print the real state: joining, silent, or access point up. |
| The answer to `POST /api/net` | "network saved - the radio joins it in a few seconds", also for a request with only the NTP server and time zone | Only a direct call to the API sees it, because the page always sends the network name (section 12.4). | Answer by what was set. |
| Console `q`, `v` | "sweep refused - see the RDA state in 's' (running, absent, or lost)" | A request lying wholly outside the oscillator window is refused too, and leaves nothing in `s` to see; `v` reaches it when the dial sits outside the window. | Have `requestSweep()` give its reason. |
| The audio board's console | "[ZDD] DAC left analogue mute" | The code only models that event, from a theory the pop hunt excluded (Appendix H). | "[ZDD] a zero run long enough for the DAC's zero-data mute has ended". |
| The audio board's console | "OTA wrote N bytes, crc ok" | Printed also when the main board sent no checksum and none was checked. | Print "no crc sent" in that case. |
| The audio board's start-up line | "[PASS] clock pads at drive N" | PASS whatever the pads read back, also a value other than 3, or 0xFF when the three pads disagree. | Print FAIL unless it reads 3. |

## 12.9 Ideas for improvement

These are not faults: improvements considered after v.1, with a starting point.

### 12.9.1 Check left and right, and let the portal swap them

**The idea.** The audio board writes the right speaker's sound into the first I2S slot and the left's into
the second, the reverse of the usual order, because that gave correct stereo on this machine. The author
knows that the amplifier sends each channel to the right speaker; whether the audio board and the DAC
deliver them the right way round has never been tested. The channel order is a setting of this machine
that another builder will need to check (chapter 10, section 10.3.4), and a portal switch to swap it on
the fly would make that easy.

**The test still to run.** Play a left/right test track over Bluetooth and listen to which speaker speaks.
That settles the Bluetooth path only. The radio path copies the converter's two slots straight across,
and with mono sum on (the default) both slots carry the same sound, so the radio's order matters only with
mono sum off.

> **For firmware changes**
>
> **Where.** `audioTask()` in `src/a32/audio.cpp`: the Bluetooth path writes `.r` into slot 0 and `.l` into
> slot 1, and the radio path copies the input slots in order. The channel format is set in
> `Audio::begin()`; the order is described at the top of `src/a32/audio.h`.
>
> **How.**
>
> 1. Add a swap flag to the audio settings (`ProtoAudio` in `include/proto.h`).
> 2. In `audioTask()`, swap each frame's two words after the volume, balance and meter pass and before
>    `i2s_write()`. Balance and the level meters then keep meaning the right and left speakers.
> 3. Add the row to `src/s3/settings_table.h`, and it appears in the portal.
>
> **What the new field costs.** It changes `ProtoAudio`'s size. A size change needs no new `PROTO_VERSION`
> (chapter 9, section 9.14.5): a message of the wrong length is refused, so a half-updated pair loses only
> the messages that carry `ProtoAudio`, and the link stays up. Until both boards carry the new structure, the
> audio board refuses every `MSG_SET_AUDIO` (volume, balance, fades and the rest do not reach it), and the
> main board refuses the audio board's `MSG_CFG` (its copy stays unknown, so the portal refuses audio
> edits). So:
>
> - **Flash both boards:** the audio board first, through the main board (updates do not use
>   `ProtoAudio`), then the main board.
> - **Download a settings file first and upload it afterwards.** The audio board accepts a stored structure
>   only if its size matches exactly, so its stored audio settings go back to their defaults once.

### 12.9.2 An equaliser

There is none; one was considered together with the swap.

> **For firmware changes**
>
> It would go in the same pass of `audioTask()`
> that applies volume and balance, and would cover the radio and Bluetooth only: AUX never passes through the
> audio board. A few biquad filters per channel, with fixed-point coefficients worked out on the main board
> (or when the setting changes) and sent as settings. The audio board is short of memory and its audio task
> runs under a tight deadline (chapter 10), so measure the task's time per block and the free memory before
> and after. The pop hunt showed how much this chain cares about timing.

## 12.10 Untested paths

Each of these is in the code and has never run on the radio. Nothing has gone wrong; each needs a fault, a
state or a set-up the radio has not had. The class of each path if it fails is in the *When it goes wrong*
table of its chapter. "Test build" means the method of the rollback tests (chapter 3, section 3.19): a
build made to fail in one chosen way, never committed, sent over the air with the USB cables unplugged, and
watched through its rollback; one build per path.

| Area | Path never run on the radio | How to test it |
|---|---|---|
| Tuning | The discard of a measurement after a bus error on the tuner chip; the "lost" path; a re-probe after a real loss | On the bench, break the tuner chip's bus during a sweep and watch the console for the discard and the ABANDONED line; restore it and watch for the re-probe. |
| Tuning | The replacement of a sample in a full table | Fill the table to twelve samples and take one more. |
| Tuning | A measurement showing both the coarse and the fine lists | Run `a` straight after a measurement. |
| Needle | **Re-index** on a needle with no zero | From the portal: **Re-index** after a failed home. |
| Needle | A portal stop or abort in the middle of an index calibration | From the portal, during **Calibrate the index**. |
| Needle | A slip of more than 40 half-steps found at a crossing, driving the re-index ladder; the three-failure FAULT; any homing FAULT since the step budgets were fixed | They need lost steps, which a test build can fake by shifting the counted position. |
| Needle | The position memory after a crash, and the detection of a torn record | The crash: a test build with a deliberate crash. A torn record: no method recorded. |
| Needle | The turn chosen by the measured tuner ends after an angle-sensor outage of more than half a turn | No method recorded. |
| Settings | The `n/a` rows of a download and the HTTP 409 refusal of audio edits, while the audio board is silent | A test build of the audio board that stops sending for a minute. |
| Settings | The downgrade lock, its complete-file unlock, the NOT SENT note and the refused download | A test build of the main board with a higher settings version, left to confirm itself and save, then replaced by the release image over the air. A rollback cannot do it: nothing is saved on trial. |
| Settings | A failed audio-board save and its retry; a failed write at the audio board's confirmation | Needs a flash fault; no method recorded. |
| Network | The rescue access point coming back after a failed join, on the current retry path | Needs a network that refuses the radio. |
| Network | The placeholder gate and the whole first-time path (chapter 8, section 8.2.2) | A spare board with the release image. |
| Network | The lockout beyond its first steps; the "full" answer to a fifth account; session eviction with more than four browsers | No method recorded. |
| Network | A phone joining the open access point and opening the sign-in page by itself. The main board's side has been seen working. | Raise the access point from the portal, join `Ambersong` from a phone, and expect the sign-in page to open by itself. |
| Link | The audio board's five-minute "the S3 never spoke" confirmation; the wrong-version count and pill with a real mismatch (they have only read 0) | A test build with another `PROTO_VERSION` on the audio board only. |
| Link | The degraded mode after a failed link self-test, on either board, and the rule that such a build is never confirmed | A test build with the self-test forced to fail. |
| Link | The two battery-clock pills in a real fault (`rtc` 1 or 2) | A test build of the audio board that reports an invalid time, or does not answer the time request. |
| Recovery | A main-board image that runs but never earns confirmation (portal or network down); a confirmation write that fails; a reset during either board's trial with a setting changed in it; a hang of the needle supervisor; a hung portal task | One test build per path. |
| Sound | Bluetooth staying invisible in RADIO mode, checked with a phone; to be repeated after any library update. **The check still pending.** | With a phone, on RADIO (chapter 10, section 10.7). |
| Sound | The channel order | A left/right test track over Bluetooth (section 12.9.1). |
| Sound | `sys.clkpair`: the master clock and the frame clocks driven at different strengths | Chapter 10, section 10.10, and Appendix H, section H.7. |
| Sound | The volume-swing test: audio-board volume 47 against 94 with a tone streaming, to see whether pops follow the signal level | Chapter 10, section 10.10. |
| Sound | The Bluetooth transmit-power A/B that would prove the 0 dBm start-up ceiling; a drive-3 pop count with Bluetooth idle | Appendix H, sections H.7 and H.8. |
| Sound | A phone negotiating 48 kHz; `connectable` off | Each waits for a listening session with the right phone or set-up (chapter 10, section 10.14). |
| Sound | A long session measuring the drift between a phone's clock and the local 44.1 kHz. There is no rate adaptation; the 186 ms ring absorbs only jitter. | A long listening session over Bluetooth. |

## 12.11 Code tidy list

> **For firmware changes**
>
> None of these changes what the radio does; they mislead a reader of the code. **Comments:** correct them
> in one comment-only commit, and prove it by stripping the comments from each file and comparing with the
> previous commit. **Unused code:** remove it in one commit; the build then proves nothing used it.
>
> **Comments that say something the code does not do.** The code is right.
>
> | Where | What the comment says | Fix |
> |---|---|---|
> | `src/s3/rda.cpp`, the stereo bits (`gBinST`) | "See isStereoBin()"; the function is `binStereo()`. | Rename it in the comment. |
> | `src/s3/rda.cpp`, the broadcast comment in the fine pass of `rdaTask()` | "see candidate()"; it is `bestCandidate()`. | Rename it in the comment. |
> | `src/s3/rda.cpp`, `requestSweep()` | "three of the five known fixed features" lie outside the window; the window's comment in `src/s3/rda.h` lists four (98.7, 101.6, 104.4 MHz and the 76.2 MHz band edge). | Make the two agree. |
> | `src/s3/needle.cpp`, `readAs5600()` | The gap warning "still says 'nearest turn' either way"; it prints "on the turn inside the tuner's ends" (section 12.2). | Correct it with that fix. |
> | `src/s3/needle.h`, `setMicro()` | `moving` is the division used for homing; no homing path selects a division, so a home started from tracking runs at `microSlow`. The comment above `coilRelease()` already says the division is set only for a sweep, tracking and a park. | Correct the header, or have homing select `moving` if that was the intent. |
> | `src/s3/needle.cpp`, `calFinishBand()` | `cfg.idx*` "is never written by anything"; the main loop now writes them from `calTakeBand()`. | Put it in the past tense. |
> | `src/s3/needle.cpp`, the band snapshot at the top | `applySettings()` runs `setIndexCal(0,0,0,0)`; true only before an index calibration has been saved. | "with the stored values, zero before the first band is saved". |
> | `src/s3/main.cpp`, `updateDisplay()` | "The timezone is set ONCE, by Net::begin()"; it is also set by `Net::setNtp()`, by `startNtp()` in `src/s3/net.cpp`, and by the console `W`. | List the setters. |
> | `src/s3/main.cpp`, the `B` case of the console | Its list has an 80 level "applied as 60"; there is no 80, and after 8 it wraps to 60. | Drop the sentence. |
> | `src/s3/main.cpp`, `settingsDump()` | Its `wifiTxQ` line is "BYTE-FOR-BYTE WHAT settingsToText WRITES"; the settings file no longer carries `wifiTxQ`. | Say the line is for reading only. |
> | `src/s3/main.cpp`, above `settingsDump()` | "one-pair lines from dialLow on"; the `dialLow` line carries two pairs. | "from tuneOffset10 on", or split the line. |
> | `src/s3/net.cpp`, the join-failure comment in `Net::loop()` | "This file opens with 'THE RADIO MUST NEVER BECOME UNREACHABLE'"; that text opens `src/s3/net.h`. | Name `net.h`. |
> | `src/s3/main.cpp` and `src/s3/needle.cpp`: `seatTurn()`'s banner, the `calLow` comment, `SMP_MAX_DRIFT`'s comment | The tuner's travel is "about 2300 counts"; the measured span is 2197, about 2200. | Write about 2200. |
> | `data/portal.html`, the `data-a` click handler | `tune.drop` uses "the same frequency prompt"; it has its own slot-number prompt. | Say so. |
> | `src/a32/audio.cpp`, "THE TWO KNOBS" | The data-line output delay function "remains only for the A32's own USB console"; the setter and its key are gone, only the read-back `sdOutDelayIs()` is left. | Say only the read-back remains. |
> | `src/a32/audio.cpp`, `src/a32/audio.h`, the audio board's key handler | They date the removal of the console key `y` a day earlier than the release that removed it, v.1.0.3. | Give the release, v.1.0.3. |
> | `src/a32/audio.cpp`, above `zeroWatch()` | "Every other counter in this file resets on read"; `btUnderruns()` and `gainWatch()` do not. | Name the ones that do. |
> | `src/a32/main.cpp`, above the `[ZDD]` announcements | Calls "a pop is predicted HERE" in the text below stale; that text is gone. | Drop the reference. |
> | `src/a32/main.cpp`, `settingsDefaults()`, `cfgB.autoConnect` | The value is "stored and shown"; its portal row was removed, so it is stored and not shown. | Correct it. |
>
> **Code defined and never used.**
>
> | Where | What | Fix |
> |---|---|---|
> | `src/s3/rda.cpp` | `R2_MONO`. | Remove it. |
> | `src/s3/rda.h`, `src/s3/rda.cpp` | `Rda::fineRssi()`, so `gFineR` is written and never read. | Remove both, or print it with the fine pass (section 12.2). |
> | `src/s3/rda.cpp` | `tuneTo()`'s `fine` flag, false at every caller. True would be wrong: the function takes tenths of a MHz, so doubling the channel addresses the same 100 kHz points; the real 50 kHz path is `tuneTo20()`. | Remove the parameter, so nobody can pass true. |
> | `src/s3/rda.h` | `Rda::IF_OFFSET20_NOMINAL`, the nominal 10.7 MHz, read by nothing. | Remove it, or keep it and derive the oscillator window from it (section 12.2). |
> | `src/s3/needle.h`, `src/s3/needle.cpp` | `Needle::getCalibration()`, `Needle::getIndexCal()`, `Needle::state()`: no caller. | Remove them. |
> | `src/s3/drive.h` | `HALFSTEPS_PER_REV`. | Remove it, or keep it as documentation with a comment that nothing uses it. |
> | `src/s3/drive.h`, `src/s3/drive.cpp` | `DRV_FULL`: `Drive::setMode()` handles it, nothing selects it. | Remove it, or keep it as documentation. |
> | `src/s3/net.h`, `src/s3/net.cpp` | `Net::apVerified()`, `Net::isQuiet()`, `Net::quietLeft()`, `Net::ntpResync()`. | Remove them. |
> | `src/s3/main.cpp`, the `MSG_HELLO_ACK` case of `onMessage()` | The "[WARN] PROTOCOL MISMATCH" check, which can never fire: the decoder drops every frame of another version first, and the wrong-version count does the job. Its comment already calls it "A GUARD THAT CANNOT FIRE TODAY". | Kept as a guard; only its removal is open. |
> | `src/a32/main.cpp` | `btStreaming`: written by the Bluetooth audio-state callback, never read. | Remove it. |
> | `src/a32/audio.h`, `src/a32/audio.cpp`, `src/a32/rtc.h` | `Audio::source()`, `Rtc::present()`. | Remove them. |
> | `include/link.h` | `txDropped_` (counted, never read), `lastRxMs()`, `peerProto()` with `peerProto_` (the main board reads the handshake's `protoVersion` directly). | Remove them, or print `txDropped_` in the console `s`. |
> | `include/proto.h` | `ProtoFramer::overruns`: counted, never read. | Remove it, or print it in `s` beside the other link counters. |
> | `platformio.ini`, `[env:s3]` and `[env:a32]` | The flags `AMB_S3=1` and `AMB_A32=1`: no source file tests them; each board is selected by its own source folder. | Remove them, or use them if shared code ever needs to tell the boards apart. |

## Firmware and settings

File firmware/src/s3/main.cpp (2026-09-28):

// ============================================================================
//  AMBERSONG  -  MAIN MCU (ESP32-S3)
//
//  Clock, needle, panel lighting, tuning, amp sensing, the link to the audio
//  MCU, WiFi, NTP and the web portal. The portal only sets values that already
//  exist (the settings table) rather than reaching into behaviour.
//
//  CORE SPLIT (Firmware Gospel §4):
//    core 1  display ISR, needle task, RDA task, this loop
//    core 0  WiFi, the portal task and the needle's step emitter
//
//  TIME LIVES ON THE OTHER MCU. The battery clock is on the A32 (Bible §5) and
//  the display is here, so the clock crosses the UART. The S3 keeps its own
//  software clock disciplined by what the A32 reports (and by NTP when WiFi is
//  up), so a slow or missing link never makes the display stutter - it just
//  stops being corrected.
//
//  WHAT "POWER ON" MEANS FOR THE NEEDLE
//  S3 boot is not necessarily the moment a person turns the radio on. The boot
//  home always ends with a full sweep; `sweepOn` adds another full sweep on
//  each amp-on edge (the front toggle), which is when someone is actually
//  watching. Adjustable, because it is a matter of taste.
// ============================================================================

#include <Arduino.h>
#include <Preferences.h>
#include <time.h>
#include <rom/crc.h>
#include "pins.h"
#include "console.h"
#include "link.h"
#include "display.h"
#include "needle.h"
#include "rda.h"
#include <esp_phy_init.h>
#include <esp_wifi.h>
#include "panel.h"
#include "drive.h"
#include "net.h"
#include "portal.h"
#include "settings_api.h"
#include <esp_ota_ops.h>
#include <esp_task_wdt.h>

#ifndef FW_VERSION
#define FW_VERSION "v.0.unstamped"
#endif
#ifndef FW_COMMIT
#define FW_COMMIT "nogit"
#endif

// ---------------------------------------------------------------------------
//  SETTINGS. One struct, stored whole, with a magic and a version so an older
//  layout is migrated (below) rather than reinterpreted. Written to NVS on a
//  DEBOUNCE: flash traffic is the one load that disturbs the display (measured
//  in phase G), and a portal slider dragged across its range would otherwise
//  write on every pixel.
// ---------------------------------------------------------------------------
//  VERSIONED AND MIGRATED, because the previous scheme silently threw away
//  everything on any layout change: the blob was rejected on a size mismatch
//  and the defaults quietly took over. That is right for a bench rig and wrong
//  for a machine somebody has spent an evening calibrating.
//
//  Rules from here on:
//    - NEVER reorder or remove an existing field. Append only.
//    - Bump SETTINGS_VERSION when you append, and add a migration case.
//    - A blob from an older version is COPIED FIELD BY FIELD into the current
//      struct, so old values survive and new fields take their defaults.
//  The soft-limit pair a machine gets before it has been calibrated, and the
//  pair a corrupt stored one is purged to. One number, three uses.
//
//  IT HAS A LOWER BOUND, AND IT IS NOT ABOUT SAFETY. After a purge the
//  post-home SWEEP runs both legs at +/-this, which traverses zero and
//  therefore the index band. That crossing is what satisfies captureLimit()'s
//  "a crossing since the home" (gMeasAtHome is taken when homing finishes), so
//  capturing the soft limits depends on it. Tune this DOWN below about half
//  the band width and homing still succeeds while no stop can ever be
//  captured. 300 clears the half-band several times over and is still far
//  inside the travel.
static const int32_t PROVISIONAL_LIMIT_HS = 300;

static const uint16_t SETTINGS_MAGIC   = 0xA838;   // settings-file magic number
static const uint16_t SETTINGS_VERSION = 7;

//  HOW MANY (angle, frequency) SAMPLES the tuning curve can hold.
//  Three are set by hand - marks A/B/C, a typed frequency at the dial's
//  current position - and the rest are there for the RDA5807M
//  auto-calibration (Firmware Gospel §6), which reads the tube
//  set's own local oscillator and can therefore produce a sample at ANY dial
//  position without a station to identify. The manual marks take slots 0-2 so
//  an automatic sample can never overwrite something the author set by hand.
static const uint8_t TUNE_MARKS = 12;

//  HOW MANY FIXED FEATURES the settings layout can hold. A SETTINGS constant,
//  deliberately NOT Rda::MAX_SPURS: sizing the struct from a module's tuning
//  knob means somebody raising that knob later changes what a version-6 blob
//  MEANS without changing its version, which is the one thing the whole scheme
//  forbids. Frozen at 16 with room to spare - this cabinet needs seven - so
//  growth needs no migration; if it ever must grow, APPEND a second array at
//  a new version rather than widening this one. The static_assert below is
//  the guard.
static const uint8_t CFG_SPURS = 16;
static_assert(Rda::MAX_SPURS == CFG_SPURS,
              "the RDA's fixed-feature list and the settings' must be the same size, or learned features are dropped");

//  tunerEndsSet: bit 0 = the low end was measured, bit 1 = the high end was.
//  Only BOTH means the travel is known.
static const uint8_t ENDS_LOW  = 1;
static const uint8_t ENDS_HIGH = 2;
static const uint8_t ENDS_BOTH = 3;

//  Version 1 is the layout that was in the machine on 2026-08-31, the one that
//  holds the first real needle calibration. It is kept verbatim so that
//  calibration migrates rather than being lost.
struct SettingsV1 {
  uint8_t  brightOn, brightOff, hour12, blankLeadZero;
  uint16_t dispDwellMs, dispFadeMs;
  uint8_t  panelTuning, panelIdle, panelOther;
  uint16_t panelIdleMs, panelFadeMs, panelDwellMs;
  uint16_t upVmax, upAccel, dnVmax, dnAccel;
  float    wn, zeta;
  uint16_t riseMs, fallMs, dwellUpMs, dwellDnMs;
  uint8_t  microFast, microSlow;
  uint16_t seekHsps, reapHsps;
  int32_t  posMin, posMax, idxOnFwd, idxOffFwd, idxOnRev, idxOffRev;
  uint8_t  sweepOn;
  int32_t  calLow, calHigh, lastAngle;
  uint8_t  showTuning;
  uint16_t bandLow, bandHigh;
};

//  Version 2 is the layout that shipped the web portal. Kept verbatim for the
//  same reason V1 is: the calibration in it is an evening of somebody's work.
struct SettingsV2 {
  uint16_t magic, version;
  uint8_t  brightOn, brightOff, hour12, blankLeadZero;
  uint16_t dispDwellMs, dispFadeMs;
  uint8_t  panelTuning, panelIdle, panelOther;
  uint16_t panelIdleMs, panelFadeMs, panelDwellMs;
  uint16_t upVmax, upAccel, dnVmax, dnAccel;
  float    wn, zeta;
  uint16_t riseMs, fallMs, dwellUpMs, dwellDnMs;
  uint8_t  microFast, microSlow;
  uint16_t reapHsps;
  int32_t  posMin, posMax, idxOnFwd, idxOffFwd, idxOnRev, idxOffRev;
  uint8_t  sweepOn;
  int32_t  calLow, calHigh, lastAngle;
  uint8_t  showTuning;
  uint16_t bandLow, bandHigh;
};

struct Settings {
  uint16_t magic   = SETTINGS_MAGIC;
  uint16_t version = SETTINGS_VERSION;
  uint8_t  brightOn      = 255;   // clock brightness, amp powered
  uint8_t  brightOff     = 110;   // clock brightness, amp off. Not too low:
                                  // the firmware has no colon pin, so the colon
                                  // cannot dim with the digits and stands out
                                  // more the further down these go.
  uint8_t  hour12        = 0;
  uint8_t  blankLeadZero = 1;
  uint16_t dispDwellMs   = 250;   // stillness before the brightness moves
  uint16_t dispFadeMs    = 1500;  // eased travel between the two levels

  uint8_t  panelTuning   = 255;
  uint8_t  panelIdle     = 128;
  uint8_t  panelOther    = 96;
  uint16_t panelIdleMs   = 5000;
  uint16_t panelFadeMs   = 900;   // eased travel, not a step
  uint16_t panelDwellMs  = 250;   // stillness first, so it decides rather than reacts

  //  NEEDLE MOTION - THE VALIDATED CONFIGURATION (Firmware Gospel §5).
  //  These took a whole session and four firmware bugs to find. Do not re-tune
  //  them by eye.
  //  1100, NOT 1700 - MEASURED BY THE AUTHOR, 2026-09-24. Faster than this, moving
  //  UP through the index, the needle stops following while the firmware keeps
  //  counting (1500 failed every time, 1200-1400 often, 1100 never), and every
  //  power-up sweep landed ~400 half-steps low. The band check in needleTask now
  //  catches it if it ever happens again.
  uint16_t upVmax        = 1100;  // half-steps/s, every second-order move (either direction)
  uint16_t upAccel       = 18000; // half-steps/s^2, same moves
  uint16_t dnVmax        = 1700;  // the decay (the fall, the park) gets its own limits on purpose
  uint16_t dnAccel       = 18000; // only enters the park's arrival test
  float    wn            = 9.0f;  // ring-down knob. Ceiling is 4*zeta*a/v = 32.7 at these defaults
  float    zeta          = 0.50f; // overshoot knob. ~5 deg, ~300 ms tail
  uint16_t riseMs        = 100;   // decay envelope, the fall
  uint16_t fallMs        = 1000;
  uint16_t dwellUpMs     = 100;   // hesitation before every commanded second-order move (not tracking)
  uint16_t dwellDnMs     = 1000;  // a full second before the fall
  uint8_t  microFast     = 16;    // sweeps, parks, homing. 1/32 clamps to 92% of commanded rate
  uint8_t  microSlow     = 32;    // while tracking the tuner - smoother where smoothness shows
  uint16_t reapHsps      = 60;    // band-calibration creep and the portal jog (not the homing re-approach)

  //  SOFT LIMITS, half-steps either side of the index. These and the search
  //  budget are all that keep the needle on the dial now.
  //  PROVISIONAL, and deliberately narrow (PROVISIONAL_LIMIT_HS, above). The
  //  old +/-967 default was an arc estimate that ran well past the measured high
  //  limit. A default with no end-stop switches must be a LOWER bound on the
  //  travel: too narrow is useless, too wide grinds. Homing does not depend on
  //  this pair (its budgets are constants).
  int32_t  posMin        = -PROVISIONAL_LIMIT_HS;
  int32_t  posMax        =  PROVISIONAL_LIMIT_HS;
  int32_t  idxOnFwd      = 0;     // the homing edge, by definition zero
  int32_t  idxOffFwd     = 0;
  int32_t  idxOnRev      = 0;
  int32_t  idxOffRev     = 0;

  uint8_t  sweepOn       = 0;     // nonzero = a full sweep on each amp-on edge (the boot home always sweeps)

  //  ACCUMULATED AS5600 counts, not raw (turns are counted across the wrap).
  //  The defaults are placeholders until the tuner's ends are measured - see
  //  tunerEndsSet.
  int32_t  calLow        = 0;
  int32_t  calHigh       = 6023;
  int32_t  lastAngle     = 0;     // so the turn can be recovered at boot

  //  0 = the clock, always. 1 = the tuning readout, always.
  //  2 = the readout WHILE TUNING, then back to the clock - the same idea as
  //      the panel lights coming up under your hand and settling afterwards.
  //      Author's request, 2026-08-31.
  uint8_t  showTuning    = 0;
  uint16_t bandLow       = 881;   // 88.1 MHz, shown as "881"
  uint16_t bandHigh      = 1079;  // 107.9 MHz

  //  How long the readout stays after the last movement of the dial, in mode 2.
  uint16_t tuneHoldMs    = 4000;
  //  APPENDED AT V4. What is PRINTED at the needle's two stops, in tenths of
  //  a MHz. Separate from bandLow/bandHigh, which describe how far the tuning
  //  CAPACITOR travels - on this set that is wider than the printed face.
  uint16_t dialLow       = 879;   // 87.9 MHz printed at the low stop
  uint16_t dialHigh      = 1079;  // 107.9 MHz printed at the high stop

  //  APPENDED AT V5. THE MAPPING IS A CURVE, NOT A LINE.
  //
  //  Measured on this set 2026-09-04 from three stations the author verified by
  //  ear: the local slope is 0.251 tenths of a MHz per permille between 91.3
  //  and 98.5, and 0.288 between 98.5 and 107.3 - a 15% change. A straight
  //  line fitted to the two ends is exact at the ends and half a megahertz out
  //  in the middle, which is precisely what happened: the two-point Mark A/B
  //  looked right, mid-band read high, correcting mid-band broke the ends.
  //
  //  SAMPLES ARE STORED, NOT COEFFICIENTS. They are self-describing, they can
  //  be re-fitted with a better model later without another migration, and no
  //  float ever goes into flash. The fit is redone on every applySettings().
  int16_t  tuneOffset10  = 0;     // slides the whole curve, tenths of a MHz
  uint16_t tuneUsed      = 0;     // bit i: slot i holds a sample
  //  RAW ACCUMULATOR COUNTS, not permille. permille is derived from
  //  calLow/calHigh, so a point stored in it stops meaning the same thing the
  //  moment the tuner ends are re-measured. The accumulator is the shaft.
  int32_t  tuneP[TUNE_MARKS] = {0};   // shaft position
  uint16_t tuneF[TUNE_MARKS] = {0};   // frequency there, tenths of a MHz
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
void loop() {
  gLink.poll();
  Net::loop();
  confirmTick(millis());
  //  THE LEARNED RUNG COMES BACK. net.cpp owns the live transmit power while it
  //  is hunting; cfg is the record. Copying it here, every pass, keeps the two
  //  within a millisecond of each other - which matters because applySettings()
  //  pushes cfg INTO net and runs dozens of times a session, so a slow sync
  //  would let an unrelated slider move stamp a stale rung over a working one.
  //  Same two-owners shape as the purge that once fired mid-edit.
  if (Net::txPower() != cfg.wifiTxQ) { cfg.wifiTxQ = Net::txPower(); settingsTouch(); }
  sampleTick();
  autoSampleTick();
  needleRecoverTick();
  idleIndexTick();
  settingsFlush();
  updateBrightness();
  uint32_t now = millis();

  // --- amp sense, and everything that hangs off it -------------------------
  {
    static uint32_t lastSys = 0;
    static uint32_t debounce = 0;
    bool amp = (digitalRead(S3_AMP_SENSE) == LOW);
    if (amp != ampOn || !ampKnown) {
      if (!debounce) debounce = now;
      if (now - debounce > 50) {
        bool wasOn = ampOn, wasKnown = ampKnown;
        ampOn = amp; ampKnown = true; debounce = 0;
        Con.printf("  amp %s\n", ampOn ? "ON" : "OFF");
        brightnessTarget(ampOn ? cfg.brightOn : cfg.brightOff);
        //  NO HOMING HERE ANY MORE. The needle knows where it is: it has been
        //  sitting at the low stop since the set was last switched off, and any
        //  index crossing since has corrected it. The switch only decides where
        //  it should now point - and from the low stop to a station IS the
        //  sweep, so nothing is lost visually.
        //
        //  The exception is a set that never found its zero: if homing failed
        //  at boot, the front switch is the natural place to try again.
        //  NOT DURING AN UPLOAD: the flash write stalls the
        //  step timing, so the needle holds still until it is over. A failed
        //  upload is caught by otaResume, which homes an unhomed needle; a good
        //  one reboots, which homes anyway.
        if (otaQuiet) {
          //  nothing - see above
        } else if (ampOn && wasKnown && !wasOn && !Needle::homed()) {
          Con.println(F("  amp came up and the needle has no zero -> homing."));
          Needle::startHoming();
        } else if (ampOn && wasKnown && !wasOn && cfg.sweepOn) {
          Con.println(F("  amp came up -> full sweep (setting)."));
          Needle::sweepRange(false);
        }
        applyNeedleMode();
        lastSys = 0;      // push the new state immediately
      }
    } else debounce = 0;

    if (peerHello && (now - lastSys >= 2000 || lastSys == 0)) {
      lastSys = now;
      ProtoSys s = {};
      s.ampOn = ampOn ? 1 : 0;
      gLink.send(MSG_SET_SYS, s);
    }
  }

  // --- link keepalive ------------------------------------------------------
  {
    static uint32_t lastHello = 0, lastPing = 0, lastTime = 0;
    if (!peerHello && now - lastHello >= 1000) {
      lastHello = now;
      ProtoHello h = {};
      h.protoVersion = PROTO_VERSION;
      strncpy(h.fwVersion, FW_VERSION, PROTO_VERSION_LEN - 1);
      gLink.send(MSG_HELLO, h);
    }
    if (peerHello && now - lastPing >= 1000) { lastPing = now; gLink.send(MSG_PING); }
    if (peerHello && now - lastTime >= 60000) {
      lastTime = now; gLink.send(MSG_GET_TIME);
      if (!gTimeAsked) gTimeAsked = now ? now : 1;
    }
    //  Asked, the A32 is alive, and no TIME came back: the DS3231 is not
    //  answering on its bus (the A32 sends nothing when its read fails).
    if (gTimeAsked && peerHello && now - gTimeAsked > 5000) { gRtcBad = 2; gTimeAsked = 0; }
    if (!peerHello) gTimeAsked = 0;
    if (peerHello && !gLink.peerAlive()) {
      peerHello = false; haveState = false;
      //  AND ITS SETTINGS ARE NO LONGER KNOWN (2026-09-25). The mirror kept
      //  saying "known" after the A32 went quiet: portal edits went nowhere and
      //  were overwritten when it came back, and a download wrote the stale
      //  copy instead of n/a. The next handshake fetches them again.
      haveCfg = false;
      Con.println(F("  [WARN] A32 silent. Clock and needle keep running."));
    }
  }

  // --- needle mode follows the source and the amp --------------------------
  {
    static uint8_t lastSrc  = 0xFF;
    static bool    lastHomed = false;
    uint8_t src = haveState ? a32.source : SRC_AUX;
    bool    h   = Needle::homed();
    //  Also on the moment homing FINISHES: that is when the needle first has a
    //  place to be, and nothing else would tell it to go there.
    //  Not consumed during an upload: applyNeedleMode() refuses then, and an
    //  edge eaten here would never be acted on.
    if (!otaQuiet && (src != lastSrc || h != lastHomed)) {
      lastSrc = src; lastHomed = h;
      applyNeedleMode();
    }
    //  AN UPLOAD THAT DID NOT END IN A REBOOT: put the needle back to work. If
    //  it was mid re-index when stopped it is unhomed, and only an amp-on edge
    //  would have homed it again - so home it now, unless homing had already
    //  given up (that fault stays for a person, as before).
    //  AND ONLY ONCE THE STOP HAS LANDED. stop() is a request the needle task
    //  carries out within 5 ms; an upload refused on its first chunk used to
    //  get here first, start tracking or homing, and then have the stop set the
    //  needle IDLE on top of it - frozen, with the radio playing.
    if (otaResume && !otaQuiet && !Needle::stopPending()) {
      otaResume = false;
      if (!Needle::homed() && !Needle::recovering() && !Needle::faultReason()[0])
        Needle::startHoming();
      else
        applyNeedleMode();
    }
  }

  //  A calibration now finishes asynchronously, so its result has to be
  //  collected rather than returned. Without this the measurement is taken
  //  correctly and then thrown away.
  //  THE BAND RESULT, WHICH USED TO EVAPORATE. calFinishBand() shifts the
  //  position frame and sets the four index constants in RAM; nothing ever
  //  copied them into cfg, and the next applySettings() called
  //  setIndexCal(cfg.idx*, ...) - all zero - putting the reference back while
  //  the frame kept its shift. Every soft limit captured afterwards was out by
  //  that shift. Collecting it here - producer raises a flag, consumer polls it
  //  once - is the contract; the end-stop collector that used to be its twin
  //  was removed on 2026-09-03.
  {
    int32_t a, b, c, d, shift;
    if (Needle::calTakeBand(a, b, c, d, shift)) {
      cfg.idxOnFwd = a; cfg.idxOffFwd = b; cfg.idxOnRev = c; cfg.idxOffRev = d;
      //  SHIFT THE LIMITS WITH THE FRAME rather than telling him to re-set
      //  them. calFinishBand() moved the position frame by `shift`, and the
      //  soft limits are PHYSICAL marks - a point at P in the old frame is at
      //  P - shift in the new one. Asking for a manual re-set is what made the
      //  band calibration destructive, and every corruption so far came from
      //  that step being missed. This also re-brackets zero automatically,
      //  because the index is 0 in the new frame by construction.
      cfg.posMin -= shift; cfg.posMax -= shift;
      //  If the carried pair no longer brackets the index, the OLD pair was
      //  already wrong by more than the travel - fall back to the narrow
      //  provisional pair rather than let setGeometry() refuse it and leave
      //  old-frame numbers behind.
      if (cfg.posMin > 0 || cfg.posMax < 0) {
        Con.printf("  carried limits do not bracket the index - reset to %ld..%ld, set the stops again.\n",
                      (long)-PROVISIONAL_LIMIT_HS, (long)PROVISIONAL_LIMIT_HS);
        cfg.posMin = -PROVISIONAL_LIMIT_HS; cfg.posMax = PROVISIONAL_LIMIT_HS;
      }
      applySettings();
      settingsTouch();
      Con.printf("  index band SAVED: onFwd %ld offFwd %ld onRev %ld offRev %ld\n",
                    (long)a, (long)b, (long)c, (long)d);
      Con.printf("  frame moved %ld half-steps; soft limits carried to %ld..%ld\n",
                    (long)shift, (long)cfg.posMin, (long)cfg.posMax);
      //  calStop() leaves st = IDLE and only applySettings() runs here, so the
      //  needle sat inert after every calibration stage and read as a hang.
      applyNeedleMode();
    }
  }


  //  Dark and still while a firmware image is being written. Deliberate - see
  //  portalOtaQuiet(). Everything comes back on the reboot that follows.
  if (otaQuiet) Panel::update(false, SRC_AUX, false);
  else          Panel::update(ampOn, haveState ? a32.source : SRC_AUX, Needle::tuningActive());

  { static uint32_t last = 0;
    if (!otaQuiet && now - last >= 200) { last = now; updateDisplay(); } }
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

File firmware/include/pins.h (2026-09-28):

#pragma once
// ============================================================================
//  GARAGE RADIO - PIN MAP, SINGLE SOURCE OF TRUTH FOR THE FIRMWARE'S PINS
//
//  The firmware takes every pin number from this file. If
//  the firmware's use of a pin changes, it changes HERE and nowhere else -
//  duplicating pin numbers across twenty test sketches is how they drift.
//
//  This file says which pin the firmware drives or reads. What each pin is
//  WIRED to is the Hardware Bible's ("docs/HARDWARE-BIBLE.md",
//  §2 for the S3, §3 for the A32). Where a comment here disagrees with the
//  Bible, the Bible is right and the comment is stale.
// ============================================================================


// ####################  MAIN MCU - ESP32-S3 N16R8 (Hardware Bible §1)  #######

// --- Amp power sense -------------------------------------------------------
//  The firmware reads LOW as "amp POWERED" (the PC817 sense: Hardware Bible
//  §7, §22).
#define S3_AMP_SENSE        1

// --- Leditron display: segment sinks (Hardware Bible §2, §9) ---------------
#define S3_SEG_A            6
#define S3_SEG_B            7
#define S3_SEG_C           15
#define S3_SEG_D           16
#define S3_SEG_E           17
#define S3_SEG_F            8      // CORRECTED 2026-08-27, was 18
#define S3_SEG_G           18      // CORRECTED 2026-08-27, was 8
//  F and G were swapped. Author drove each and reported which bar lit:
//  the pin previously named G lights the TOP-LEFT bar (F), and vice versa.

// --- Leditron display: digit select ----------------------------------------
//  Driving a digit pin HIGH turns its digit ON (the driver chain is in the
//  Hardware Bible §9). Only ever one digit at a time, and blank before
//  switching.
//  CORRECTED 2026-08-27. Author observed: driving the pin then named DIGIT_1 lit
//  physical digit 2, and the pin named DIGIT_3 lit physical digit 4, so 1<->2
//  and 3<->4 were swapped. The author has since ruled this order right ("Pins.h
//  is right.", Hardware Bible §0).
#define S3_DIGIT_1         42      // was 2
#define S3_DIGIT_2          2      // was 42, confirmed: this pin lights digit 2
#define S3_DIGIT_3         40      // was 41
#define S3_DIGIT_4         41      // was 40, confirmed: this pin lights digit 4

// --- Stepper driver inputs IN1..IN4 (Hardware Bible §11) -------------------
//  drive.cpp drives these in this order, I1..I4 = 9, 10, 11, 12, through LEDC
//  with its own half-step table. AccelStepper is not used.
#define S3_STEPPER_I1       9
#define S3_STEPPER_I2      10
#define S3_STEPPER_I3      11
#define S3_STEPPER_I4      12

// --- Index sensor ----------------------------------------------------------
//  One Hall switch, read active LOW with no internal pull-up (the sensor and
//  its pull-up: Hardware Bible §11). It is a reference mark, NOT an end-stop.
//  Travel is bounded by soft limits in needle.cpp, and every homing phase runs
//  under a step budget so a dead sensor faults instead of driving on forever.
//  It replaced the two limit switches on 2026-08-30.
#define S3_INDEX_HALL       5
//  S3_LIMIT_LEFT (was 5) and S3_LIMIT_RIGHT (was 4) were deleted on
//  2026-09-20. Neither was used anywhere in src/ or include/. LEFT only
//  aliased the Hall pin above, which is a trap. The firmware does not use
//  GPIO4 (Hardware Bible §2).

// --- Inter-MCU UART (the link: Hardware Bible §2, §3) ----------------------
#define S3_UART_TX         13      // TX; the A32 receives on A32_UART_RX
#define S3_UART_RX         14      // RX; the A32 sends on A32_UART_TX

// --- Panel lighting --------------------------------------------------------
//  One PWM output that switches the panel lamps (Hardware Bible §11). Nothing
//  here computes from the lamp hardware: the panel runs LEDC channel 1 at
//  1 kHz, 8-bit.
#define S3_PANEL_PWM       21

// --- AS5600 tuning position encoder (I2C) ----------------------------------
//  100 kHz, NOT 400. The bus's pull-ups, series resistors and supply are in
//  the Hardware Bible (§2, §11).
#define S3_AS5600_SDA      38
#define S3_AS5600_SCL      39
#define S3_I2C_HZ      100000
#define AS5600_ADDR      0x36
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

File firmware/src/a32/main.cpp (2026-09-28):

// ============================================================================
//  AMBERSONG  -  AUDIO MCU (ESP32-WROOM-32)
//
//  THE AUDIO ENGINE: A2DP sink, radio capture through the ADC, output through
//  the DAC (the converters: Bible §6), the source switching between them, the
//  DS3231, and the S3 end of the link, in one firmware.
//
//  What makes it tractable is in audio.h: A2DP is told NOT to touch I2S. We install
//  the driver once, full duplex, and never reconfigure it. Source switching is
//  then a decision about where the next block of samples comes from.
//
//  BLUETOOTH CONNECTION POLICY - the author's rules, and why the mapping is
//  what it is.
//    "a phone that wanders into range must not latch on its own"
//    "a phone that has connected before may reconnect on demand FROM THE PHONE"
//    "the button is for devices that have NOT connected before"
//  Those three give exactly one arrangement:
//    NOT in BT mode      -> non-connectable, non-discoverable. Invisible.
//    in BT mode, idle    -> CONNECTABLE, NOT discoverable. A bonded phone can
//                           come back on its own; an unknown phone cannot even
//                           see the radio.
//    button pressed      -> connectable AND discoverable, for new pairings,
//                           until the pairing window (cfgB.lookTimeoutS) closes.
//    a phone connected   -> NOT connectable, so no second phone pages in behind it.
//  And all of it is additionally gated on being AWAKE - the amp on AND the S3
//  talking (see AWAKE / ASLEEP) - and on the proto self-test having passed. The
//  A32 runs whenever the set is plugged in (Bible §10), so without that gate a
//  phone could connect at 3 a.m. and silently route its audio into a radio that
//  is off. Every rule is applied in one place: applyScanMode().
//
//  The radio NEVER initiates. set_auto_reconnect(false), hard-coded in setup().
//  The phone comes to the radio, not the other way round.
// ============================================================================

#include <Arduino.h>
#include <Preferences.h>
#include <Update.h>
#include <rom/crc.h>
#include <esp_gap_bt_api.h>
#include <esp_bt.h>
#include <esp_ota_ops.h>
#include <esp_task_wdt.h>
#include <esp_system.h>
#include "BluetoothA2DPSink.h"
#include "pins.h"
#include "link.h"
#include "audio.h"
#include "btled.h"
#include "rtc.h"

#ifndef FW_VERSION
#define FW_VERSION "v.0.unstamped"
#endif
#ifndef FW_COMMIT
#define FW_COMMIT "nogit"
#endif

static const char *DEVICE_NAME = "Ambersong";

// ---------------------------------------------------------------------------
//  NULL OUTPUT  -  the fix for a real bug, found on the hardware 2026-08-28.
//
//  `set_stream_reader(cb, false)` is documented as "do not write to I2S", and
//  it does suppress begin(), end() and write(). It does NOT suppress
//  set_sample_rate(): BluetoothA2DPSink.cpp calls `out->set_sample_rate()`
//  UNGATED by is_output, and BluetoothA2DPOutputDefault::set_sample_rate()
//  calls i2s_set_clk().
//
//  So the moment a phone started streaming, the library silently reconfigured
//  OUR driver from 32-bit full duplex to its own 16-bit TX settings. Observed
//  symptoms, all explained by that one call:
//    - Bluetooth played at full scale and garbled, ignoring the volume setting
//      entirely, because our 32-bit samples were being clocked out as 16-bit
//    - the active channel swapped, because the frame alignment moved
//    - and RADIO STAYED DEAD AFTERWARDS, because the capture side never came
//      back from a clock reconfiguration it never asked for
//
//  Relying on the flag was the mistake. This class makes it structural: the
//  library is handed an output object that has no way to reach I2S at all.
//  Same discipline as the rest of this firmware - make it impossible, do not
//  make it a rule to remember.
// ---------------------------------------------------------------------------
class NullA2dpOutput : public BluetoothA2DPOutput {
 public:
  bool   begin() override                            { return true; }
  size_t write(const uint8_t *, size_t len) override { return len; }
  void   end() override                              {}
  void   set_sample_rate(int) override               {}
  void   set_output_active(bool) override            {}
  void   write_silence(size_t) override              {}
};
static NullA2dpOutput nullOut;

//  See set_volume_control() below: this makes "the library does not touch our
//  samples" structural rather than hoped for.
static A2DPNoVolumeControl noVol;

//  The negotiated rate is not ours to choose - the phone picks it. Our I2S is
//  fixed at 44.1 kHz, so anything else plays at the wrong pitch. Say so loudly
//  rather than leaving it to sound mysteriously wrong.
static void onSampleRate(uint16_t rate) {
  Serial.printf("  A2DP negotiated %u Hz\n", rate);
  if (rate != 44100)
    Serial.printf("  [WARN] I2S is fixed at 44100 Hz. Audio will play at the\n"
                  "         wrong pitch (%.2fx). This needs resampling.\n",
                  rate / 44100.0);
}
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

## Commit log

2026-09-28 Ambersong: first public commit
    A vintage vacuum tube radio, connected with ESP32 audio and control.
    The Hardware Bible and the Firmware Gospel (docs/), the firmware for
    both boards (firmware/), the KiCad project and the printed parts
    (hardware/), licences and notices.
    [AUDIO - Passive Radiator - Holder.stl, AUDIO - Passive Radiator - Inside Protector.stl, AUDIO - Passive Radiator - Membrane Weight.stl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]
2026-09-28 Docs: audit fixes — tuner span about 2200 (amendment 1.3 row), pre-release commits dated instead of labelled v.1.0, duplicated version labels, §30.4 measurement note
2026-09-28 Gospel: amendment 1.8 carried over (§0.6 names homingTick())
    Source: Firmware 85a36cf.
2026-09-28 First render, collated schematic PDF, the author's BOX FAN sheet edit; the running hare is carved out of the licences
    The hare is all rights reserved; photos and renders are CC BY-NC-ND 4.0.
    KiCad and SketchUp backups are ignored. NOTICE credits Claude Code and
    Codex, as the README does.
    [Ambersong - BOX FAN.kicad_sch]
2026-09-28 Refine README content for clarity and copyright
    Removed redundant wording in the README regarding printed parts and clarified the copyright notice for the running hare image.
2026-10-01 Photos of the finished radio, and the power-up and power-down animations
2026-10-02 Bible: four heater bypass caps to CHASSIS (§20); the J42/J51 line (§22)
    Source: library b3b45eb.
2026-10-02 Gospel: amendment 1.10 carried over (needle travel about 478 000 fine steps, microstep modes, A32 gain clamps, recovery classes, new 12.4.18)
    Source: Firmware bb3a3d6.
2026-10-02 Bible: RV4 drawn B10K (§7), SP1 and SP2 are the factory's speakers on no circuit (§22, §26), antenna earth from the grounding block (§29.2)
    Source: library 4ac5dca.
2026-11-11 Release v.1: new layout, LLM and PDF editions, licence files, firmware comments
    - docs/: the Hardware Bible and Firmware Gospel as two PDFs and as Markdown
    for an LLM (4 + 9 files), with their figures, schematic sheets and crops;
    photos and animations moved here from photos/
    - llms.txt; README.md in docs/, hardware/ and firmware/
    - root LICENSE-<SPDX> files, identical to LICENSES/; the combined LICENSE
    folded into NOTICE
    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
